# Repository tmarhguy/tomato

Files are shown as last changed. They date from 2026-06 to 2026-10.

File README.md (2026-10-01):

<h1 align="center">Tomato</h1>
<p align="center"><strong>A 32-bit computer architecture built from copper to browser.</strong></p>
<p align="center">
  
  
  
  
  
</p>

<p align="center">
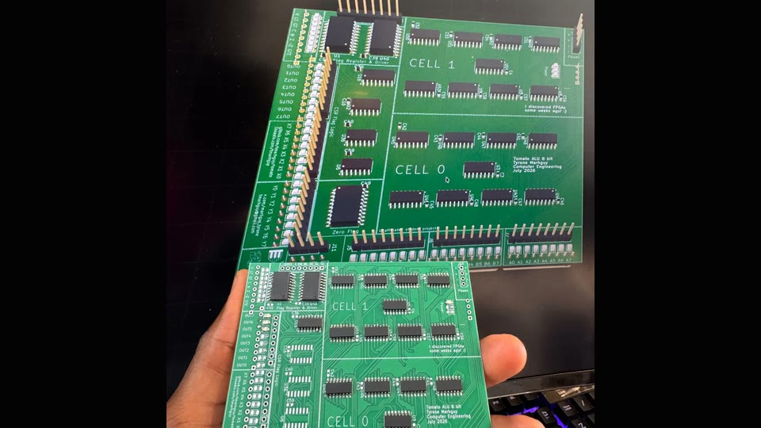
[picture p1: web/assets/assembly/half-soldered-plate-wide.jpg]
Physically assembled Tomato Dual-LUT ALU slice
  
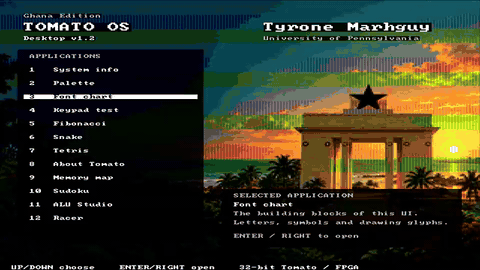
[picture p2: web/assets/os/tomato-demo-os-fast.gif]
Accelerated preview of Tomato OS running on FPGA Tomato
  
</p>
<p align="center"><em>Physical ALU slice · <a href="web/assets/os/tomato-demo-os.mp4">FPGA Tomato OS recording (4× preview)</a></em></p>

The animation is a sped-up preview of the complete FPGA machine.

Tomato is one architecture expressed at several layers:

- a fabricated and soldered **8-bit 74xx Dual-LUT ALU slice**;
- a complete **FPGA Tomato** on the Nexys A7-100T that boots the
  assembly-written Tomato OS;
- **TOMATO OS v3.0**, written in Tomato assembly, with 14 menu entries;
- a functional **Virtual Tomato** ISA emulator in the browser;
- editable Digital schematics, KiCad boards, RTL, an assembler, and focused verification.

The complete discrete computer remains a goal. The assembled ALU slice is real
hardware, but it is not a complete discrete machine. The complete running
computer in this repository is the FPGA implementation.

**Explore:** [architecture](docs/architecture.md) ·
[current status](docs/status.md) ·
[Tomato OS](software/os/README.md) ·
[ISA](docs/isa/README.md) ·
[compute](docs/compute.md) ·
[documentation index](docs/README.md) ·
[project site](https://tomato.tmarhguy.com/)

## Architecture at a glance

These curated diagrams explain the system; the
[interactive GitDiagram](https://gitdiagram.com/tmarhguy/tomato) provides a
zoomable, generated map of the public repository's default branch.

**Visual entry points:** [interactive repository map](https://gitdiagram.com/tmarhguy/tomato) ·
[architecture guide](docs/architecture.md) ·
[web architecture](https://tomato.tmarhguy.com/architecture.html) ·
[ISA reference](https://tomato.tmarhguy.com/isa.html) ·
[run Virtual Tomato](https://tomato.tmarhguy.com/virtual.html)

### One architecture, several realizations

<picture>
  <source media="(prefers-color-scheme: dark)" srcset="web/assets/gallery/diagrams/system-realizations-dark.svg">
  Editable Tomato sources flow into discrete hardware, FPGA, RTL simulation, browser emulation, and their evidence layers
</picture>

The four realization boxes are deliberately separate. The assembled discrete
hardware proves the ALU slice; the FPGA is the complete machine; Icarus runs
the RTL locally; and the browser is a functional ISA emulator.
[Diagram source](docs/diagrams/system-realizations.mmd).

### From source files to runnable artifacts

<picture>
  <source media="(prefers-color-scheme: dark)" srcset="web/assets/gallery/diagrams/artifact-pipeline-dark.svg">
  Tomato ISA and OS sources generate shared FPGA burn headers and a browser firmware image
</picture>

The generated FPGA burn and browser image share the same OS and control data.
They do not share an execution engine: the FPGA and Icarus execute Verilog,
while `tomato-cpu.js` mirrors the ISA-level behavior in JavaScript.
[Diagram source](docs/diagrams/artifact-pipeline.mmd).

### Inside FPGA Tomato

<picture>
  <source media="(prefers-color-scheme: dark)" srcset="web/assets/gallery/diagrams/fpga-datapath-dark.svg">
  FPGA Tomato datapath from program counter and memory through decode, registers, execution, writeback, and memory-mapped peripherals
</picture>

The board harness owns clocks, pins, keypad debounce, glyph rendering, DVI, and
seven-segment output. The machine core exposes those facilities as ports and
memory-mapped windows, keeping board-specific wiring outside the CPU RTL.
[Diagram source](docs/diagrams/fpga-datapath.mmd).

### Authority and state boundaries

- **Edit:** Digital schematics, ISA CSVs, assembly sources, and FPGA/browser
  implementation source.
- **Regenerate:** `.mem` images, `rtl/burn/*.vh`, `tomato-os.bin`, and
  bitstreams. These are derived artifacts, not design authorities.
- **Runtime state:** FPGA RAM, registers, framebuffer, compiler, radio mailbox,
  and the browser machine are volatile. Reset or reload restores the compiled
  image; this repository has no application database.
- **External systems:** Envelop clients, durable queues, hosted services, and
  the nearby bridge belong to the separate Envelop project.

## What runs now

| Layer | Current, repository-backed statement |
|---|---|
| Architecture | 32-bit datapath and instruction word |
| ALU | Custom three-source Dual-LUT ALU: two LUT3 functions feed an adder, `f(a,b,c) + g(a,b,c) + carry` |
| ISA | **91 instructions plus NOP, 92 burned rows** in a 512-row control ROM |
| Register array | Discrete (primary): **32,768 × 32-bit**. FPGA: **256 × 32-bit**, addressed as 3 bank bits plus a 5-bit register field; `r0` is hardwired to zero — no space for more on that implementation |
| FPGA | 100 MHz board input; **6.25 MHz** default CPU and 25 MHz pixel clocks; 90 MHz is only the nextpnr timing target |
| OS | The complete FPGA computer boots assembly-written **TOMATO OS v3.0**, with 14 menu entries including Envelop |
| Browser | Functional ISA-level emulation; not cycle-accurate RTL or physical execution |
| Hardware compiler | Counter FSM searches all **65,536 LUT pairs** for one fixed A/B/C/carry/output example; a hit verifies that example, not a general function |
| ALU verification | A **130-billion-vector** 32-bit ALU run is recorded and its harness is reproducible; the full run log is not checked in |

The architectural register count is **32,768**, because discrete is the
superior design constraint. FPGA implementation remains **256 × 32-bit**
because there is no space for a larger file; its 3-read/1-write array maps to
distributed RAM. Discrete uses external SRAM plus a seven-bit superbank and
`SETBANK2`. Neither the superbank nor that instruction exists in the current
FPGA RTL and burned ISA.

For evidence paths and the distinction between source-complete,
hardware-dependent, and deployed behavior, use
[`docs/status.md`](docs/status.md). Historical journal entries can describe
earlier designs and counts; they do not override current sources.

## See it, run it, inspect it

### Browser

Open the [Tomato site](https://tomato.tmarhguy.com/) and choose the Virtual
Tomato experience. Its checked-in OS image is generated from the assembly and
control data in this repository. Results there must be labeled virtual.

<p align="center">
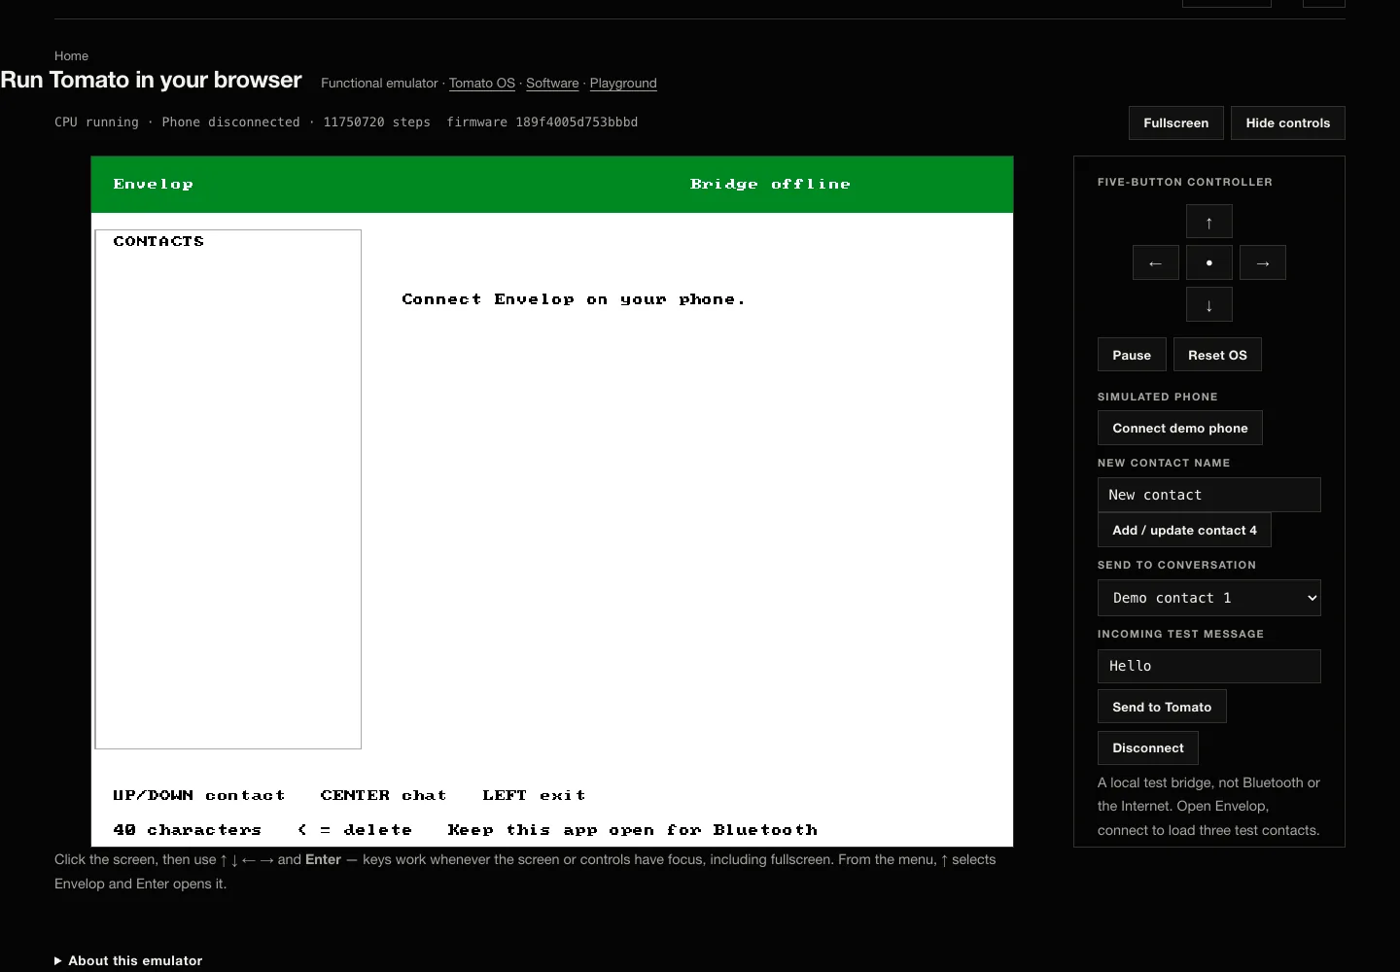
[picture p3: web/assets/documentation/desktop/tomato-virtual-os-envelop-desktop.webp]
Play with Tomato OS in the Virtual Tomato browser emulator
  
</p>
<p align="center"><strong><a href="https://tomato.tmarhguy.com/virtual.html">Play with Virtual Tomato →</a></strong><br><em>Functional ISA emulation with simulated peripherals—not FPGA or discrete-hardware execution.</em></p>

### Local RTL simulation

Icarus Verilog can boot the OS and print its framebuffer without an FPGA:

```bash
make -C hardware/fpga/core os
```

Run the focused core regression:

```bash
make -C hardware/fpga/core test
```

These commands prove simulation behavior, not a currently programmed board.

### Assemble a Tomato program

```bash
python3 software/assembler.py software/asm/counter.s \
  -o /tmp/counter.mem --list
python3 software/assembler.py --selftest
```

The assembler reads the burned ISA and pseudo-instruction CSVs rather than
carrying a private opcode table.

### FPGA build

The default flow is Yosys → nextpnr-xilinx → Project X-Ray. An optional Linux
Vivado batch target is also provided. Building a bitstream does not prove that
a board is currently programmed.

```bash
make fpga-setup
make fpga
```

Programming is intentionally a separate, hardware-changing action; see
[`hardware/fpga/README.md`](hardware/fpga/README.md).

## Proof across the stack

<table>
  <tr>
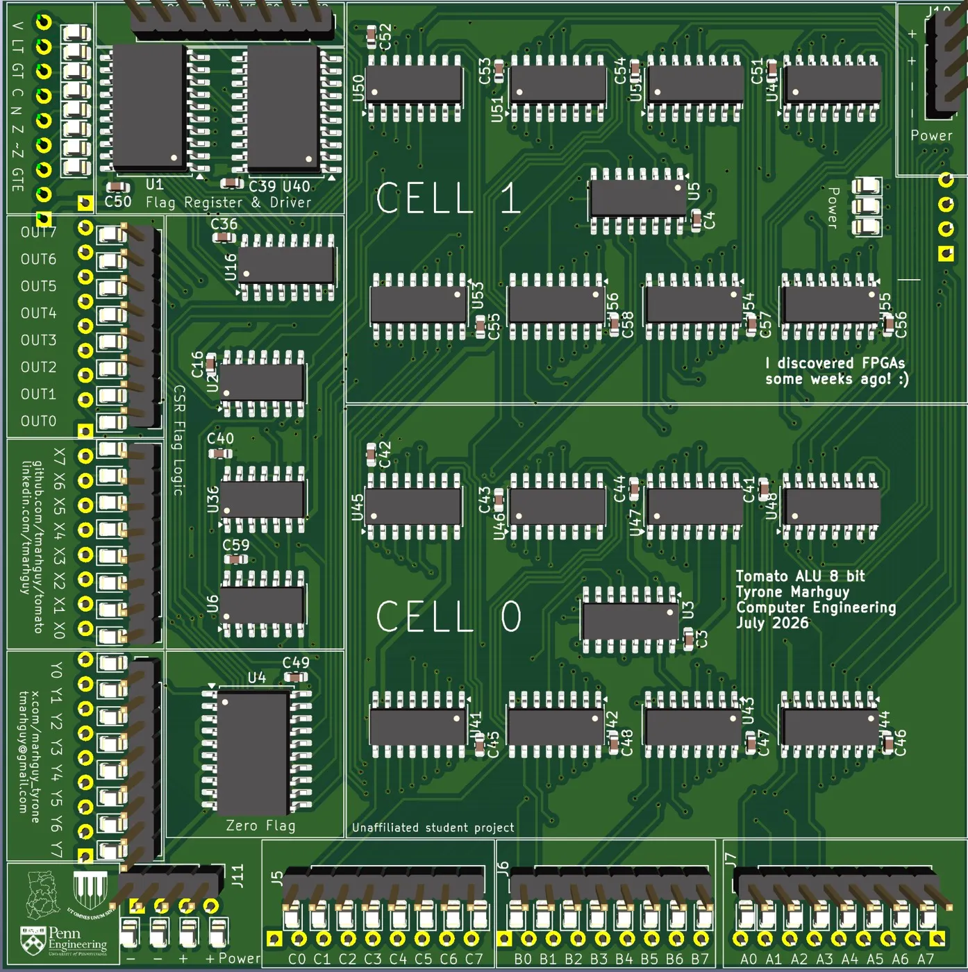
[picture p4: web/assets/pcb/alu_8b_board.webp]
Rendered Tomato Lot 07 Dual-LUT ALU PCB
    <td width="33%" align="center" valign="middle"></td>
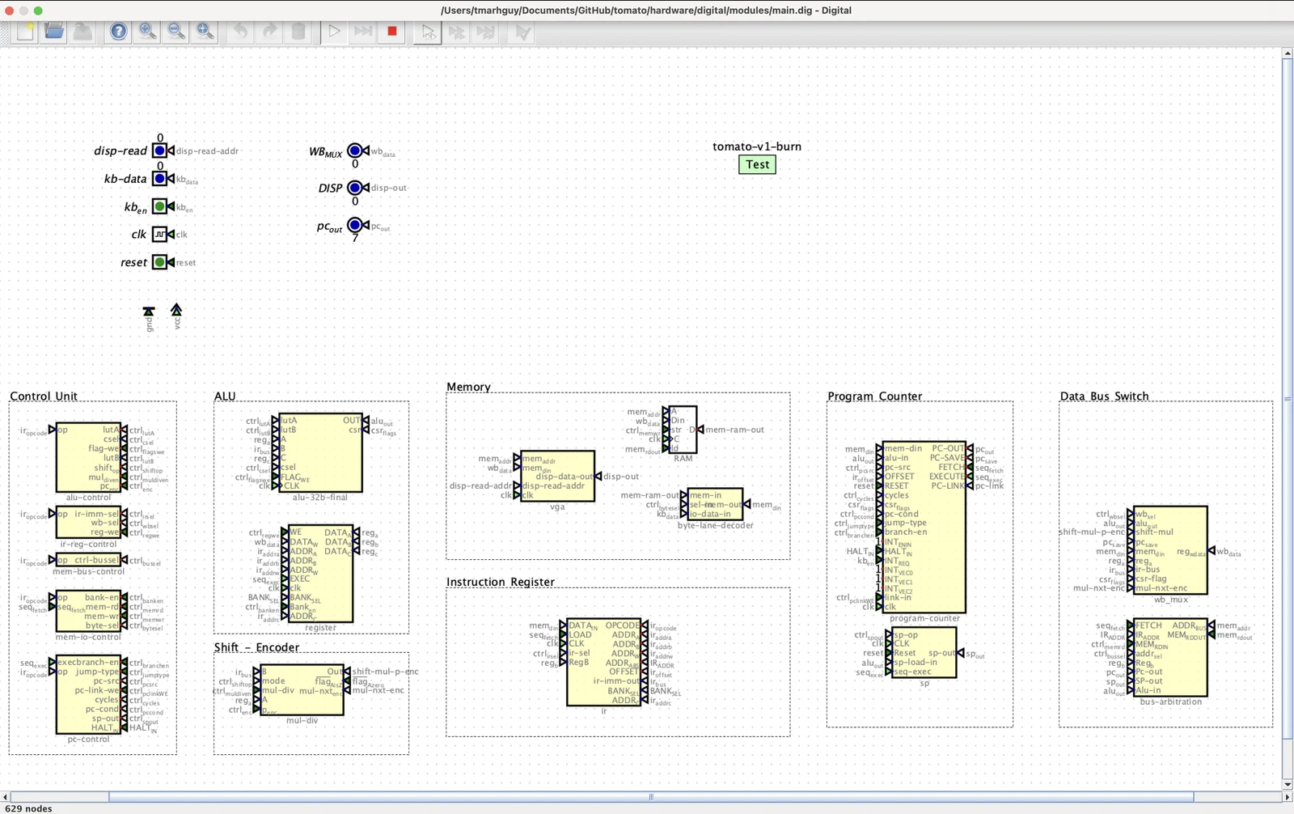
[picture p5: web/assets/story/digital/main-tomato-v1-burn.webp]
Tomato architecture in the Digital logic simulator
    <td width="33%" align="center" valign="middle"></td>
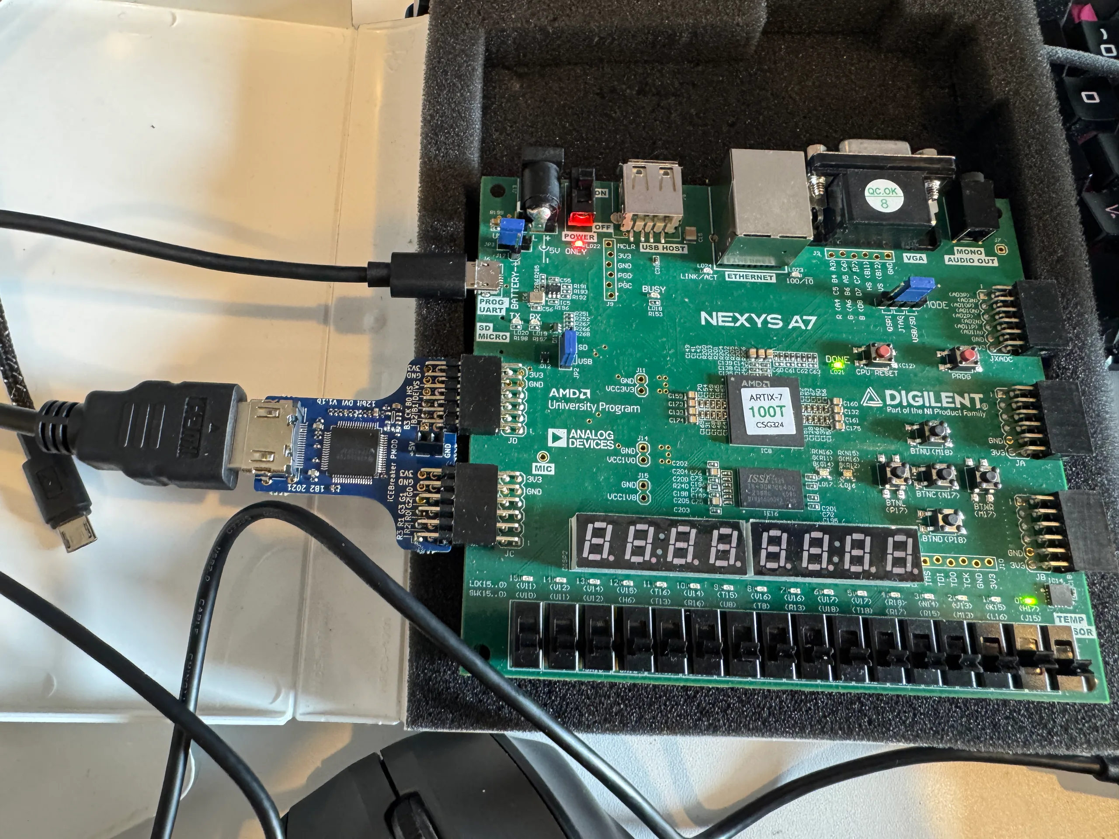
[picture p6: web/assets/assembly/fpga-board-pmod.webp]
Nexys A7 board used for FPGA Tomato display output
    <td width="33%" align="center" valign="middle"></td>
  </tr>
</table>

- **Physical scope:** [`hardware/kicad/boards/07_alu/`](hardware/kicad/boards/07_alu/)
- **Editable logic:** [`hardware/digital/`](hardware/digital/)
- **Complete FPGA machine:** [`hardware/fpga/core/`](hardware/fpga/core/)
- **Machine software:** [`software/`](software/)
- **Verification:** [`verification/`](verification/)
- **Evidence and asset provenance:** [`docs/assets.md`](docs/assets.md)

## Envelop and compute

Envelop is a separate messaging project. Its Tomato-side client and bounded
compute executor are linked into Tomato OS; its user clients, backend, and
nearby bridge live outside this repository.

The intended hardware message path is:

`person → Envelop web app → backend queue → nearby verified bridge → Envelop in Tomato OS → Tomato CPU → labeled reply`

<picture>
  <source media="(prefers-color-scheme: dark)" srcset="web/assets/gallery/diagrams/envelop-boundary-dark.svg">
  Envelop hardware path from person and backend queue through a verified bridge to FPGA Tomato, with virtual preview kept separate
</picture>

Source in a repository is not evidence that a bridge is active or that a reply
ran on hardware. Bridge software is available in the separate Envelop project,
but a nearby authenticated bridge and completed FPGA job require live evidence.
Virtual previews are explicit, separate, and labeled. See
[`docs/compute.md`](docs/compute.md) for the current boundary.
[Diagram source](docs/diagrams/envelop-boundary.mmd).

## Repository map

| Path | Purpose |
|---|---|
| [`docs/`](docs/) | Canonical guides, ISA contracts, and historical journal |
| [`hardware/digital/`](hardware/digital/) | Editable architecture schematics |
| [`hardware/kicad/`](hardware/kicad/) | PCB designs and assembly records |
| [`hardware/fpga/`](hardware/fpga/) | Complete machine, board harness, and simulation |
| [`software/`](software/) | Assembler, programs, and Tomato OS |
| [`microcode/`](microcode/) | Control-ROM packaging |
| [`verification/`](verification/) | ALU and implementation checks |
| [`web/`](web/) | Project site and browser emulator |

## Documentation and history

Start with [`docs/README.md`](docs/README.md). It separates current canonical
guidance from the dated [`docs/log/`](docs/log/) engineering record. The
journal preserves decisions, wrong turns, and superseded designs as history;
use the [current journal index](docs/log/README.md) to navigate it.

Documentation authority and terminology are defined in
[`docs/documentation-policy.md`](docs/documentation-policy.md). When prose and
executable sources disagree, that policy determines which source wins.

## Documentation

Detailed architecture, implementation, verification, and technical
documentation is available in the project documentation.
The technical reference manual source is [`docs/index.adoc`](docs/index.adoc);
build the static manual locally with `make docs` (requires Asciidoctor).

## License and author

Tomato is licensed under the [Solderpad Hardware License 2.1](LICENSE).
Architecture and project by **Tyrone Marhguy**, Computer Engineering ’28,
University of Pennsylvania.

[Contributing](CONTRIBUTING.md) · [security](SECURITY.md) ·
[citation](CITATION.cff) · [third-party notices](THIRD_PARTY_NOTICES.md)

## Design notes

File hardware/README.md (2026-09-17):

# Tomato hardware

Tomato's architecture appears in editable schematics, physical PCB work, and a
complete FPGA implementation. These layers share a design, but they prove
different things.

<p align="center">
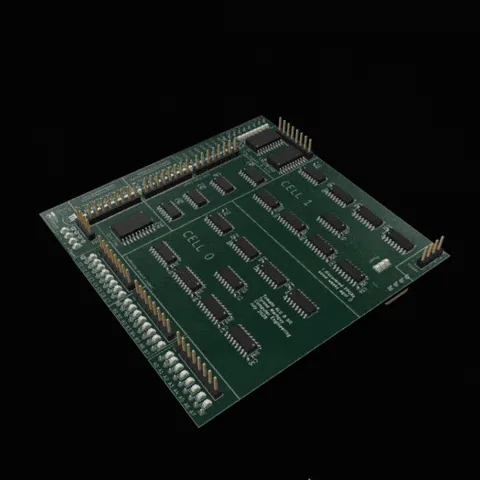
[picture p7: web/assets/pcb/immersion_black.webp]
Tomato Dual-LUT ALU PCB
  
  Nexys A7 used by the complete FPGA Tomato machine
</p>
<p align="center"><em>Discrete ALU work at left; complete FPGA machine at right.</em></p>

## Current scope

- The physically assembled discrete hardware is a **Dual-LUT ALU slice**, not
  a complete discrete computer.
- The complete machine capable of booting Tomato OS is **FPGA Tomato** on the
  Nexys A7-100T.
- Digital schematics remain the editable architectural source for the discrete
  design.
- Exported Verilog is a derivative and must not be hand-edited as design source.

## Directory map

| Path | Role | Authority/evidence |
|---|---|---|
| [`digital/`](digital/) | Digital schematics and simulation | Editable architecture source |
| [`kicad/`](kicad/) | Numbered board designs and assembly documentation | Physical design and pictured build evidence |
| [`fpga/`](fpga/) | Complete Nexys A7 machine, board harness, and tests | Current FPGA implementation |
| [`verilog/`](verilog/) | Digital export policy and netlists | Generated/read-only derivatives |

Current register, ISA, OS, and clock facts live in
[`../docs/status.md`](../docs/status.md). Older hardware notes may describe
different register or ISA designs and do not override that canonical status.

## Workflow boundaries

For discrete logic, edit Digital sources, export Verilog, then copy the export
to the relevant verification/implementation tree and run the appropriate
checks. For PCB work, KiCad sources and assembly records establish design and
physical scope.

For FPGA work, the default build uses Yosys, nextpnr-xilinx, and Project X-Ray.
An optional Linux Vivado batch target also exists. A successful build is not
proof that a board is currently programmed.

## Continue

- [Architecture guide](../docs/architecture.md)
- [Digital guide](digital/README.md)
- [KiCad guide](kicad/README.md)
- [FPGA guide](fpga/README.md)
- [FPGA core guide](fpga/core/README.md)
- [Documentation authority](../docs/documentation-policy.md)

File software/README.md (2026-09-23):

# Tomato software

This directory contains Tomato's two-pass assembler, assembly test programs,
and TOMATO OS v3.0. Machine instructions come from
[`docs/isa/tomato.v1.csv`](../docs/isa/tomato.v1.csv); assembler-only
vocabulary comes from
[`docs/isa/tomato.v1.pseudo.csv`](../docs/isa/tomato.v1.pseudo.csv).

**Project map:** [root README](../README.md) · [ISA](../docs/isa/README.md) · [Tomato OS](os/README.md) · [FPGA core](../hardware/fpga/core/README.md)

<p align="center">
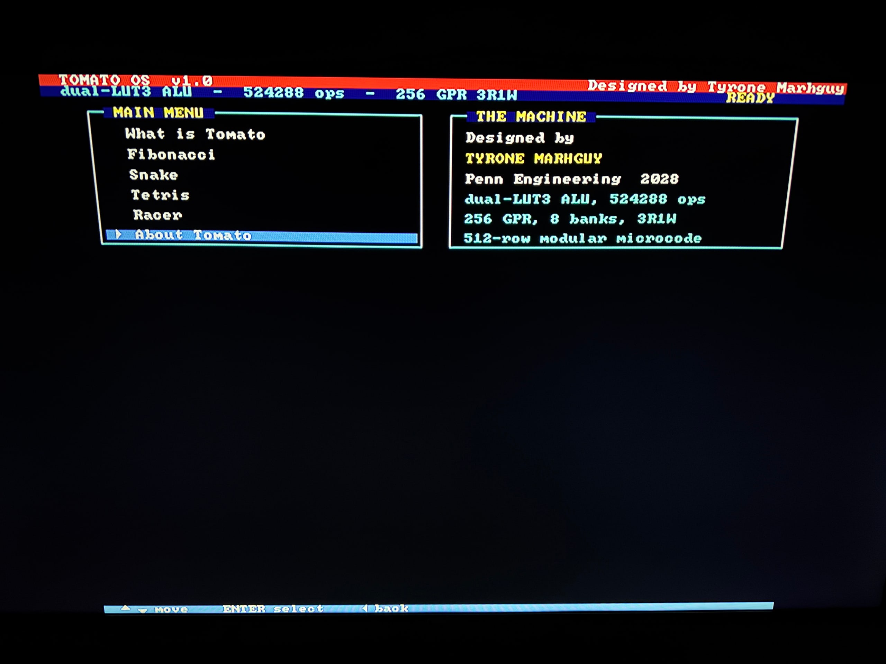
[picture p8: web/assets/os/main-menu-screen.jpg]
Tomato OS main menu on HDMI
  
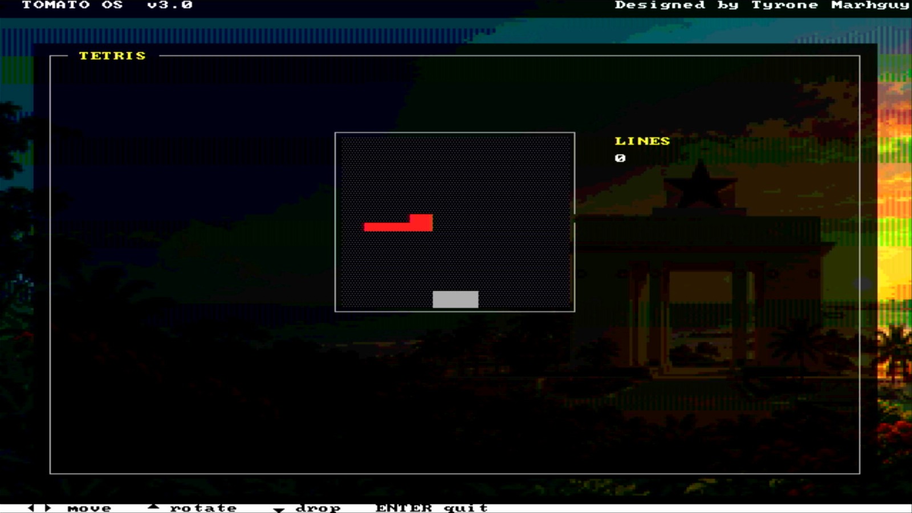
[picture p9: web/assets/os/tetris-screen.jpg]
Tetris on Tomato OS
  
</p>
<p align="center"><em>Tomato OS · menu and Tetris · <a href="https://tomato.tmarhguy.com/software.html">software sheet</a></em></p>

| Path | What |
|---|---|
| `assembler.py` | Two-pass assembler; the ISA CSVs are its only opcode source |
| `os/` | Tomato OS v3.0, its 14 entries, Envelop client, and bounded executor |
| `asm/` | Small programs, each with a value a testbench asserts on |

---

## Table of Contents

- [Assemble](#assemble)
- [Two authorities](#two-authorities)
- [Syntax](#syntax)
- [Directives](#directives)
- [Tomato OS](#tomato-os)
- [Samples](#samples)

---

## Assemble

```bash
python3 software/assembler.py software/asm/counter.s -o hardware/fpga/core/tb/mem/counter.mem --list
```

From `hardware/fpga/core`: `make asm` builds every image, `make burn` packs them into the FPGA burn headers, `make os` runs the OS in simulation.

---

## Two authorities

The assembler holds no opcode table of its own. It reads both CSVs at startup, so growing the machine's vocabulary is a data change, not a code change.

| File | Holds |
|---|---|
| [`tomato.v1.csv`](../docs/isa/tomato.v1.csv) | The 512-row control ROM: **91 instructions plus NOP, 92 burned rows** |
| [`tomato.v1.pseudo.csv`](../docs/isa/tomato.v1.pseudo.csv) | Pseudo-instructions that expand into already-burned instructions |

Check the second one against the first at any time:

```bash
python3 software/assembler.py --selftest
```

That assembles every pseudo twice — once as the pseudo, once as the instructions it claims to expand into — and fails if the two word images differ. `make -C hardware/fpga/core test` runs it as `asm-check`.

---

## Syntax

| Form | Example |
|---|---|
| RRR | `ADD r4, r1, r2` |
| MOV | `MOV r1, r2` (rd ← rB) |
| unary | `ZERO r5` |
| ADDI/LW | `ADDI r1, r0, 10` / `LW r6, r5, 0` |
| SW | `SW r1, r5, 0` (data, base, imm8) |
| branch | `BNE loop` / `BEQ done` (PC-relative) |
| jump | `JMP loop` (absolute word address) |
| system | `NOP` / `HALT` / `RET` |

Comments: `;` or `#`. Labels: `name:`.

### Vocabulary

The CPU has only `BEQ` / `BNE` / `BLT` / `BGE`, and the compare that feeds them is a separate instruction, so plain intent used to read as two unrelated lines. These say it in one:

| Write | Get |
|---|-----|
| `CALL puts` | `JAL r16, puts` — the link register |
| `BEQZ r22, done` | `CMP r22, r0` + `BEQ done` |
| `BNEZ`, `BLTZ`, `BGEZ` | the same shape, other conditions |
| `BLE done` | `BEQ done` + `BLT done` |
| `BGT done` | skip the `BGE` when the compare was equal |
| `LI r5, 100` | `ADDI r5, r0, 100` — value, not address |
| `TST r6` | `CMP r6, r0` |
| `INC` / `DEC` / `NEG` / `CLR` | in-place arithmetic, spelled out |
| `BZ` / `BNZ` / `BMI` / `BPL` | the conditionals, read after a `TST` |
| `BRA` / `ASL` | `JMP` / `LSL` under their usual names |

`LA rd, label` loads an address, and is the one thing limited to the low 4 KB — it assembles to `ADDI rd, r0, addr`, so the label must fit an unsigned 12-bit immediate. Pointer tables have no such limit: a `.word label` holds the full 32-bit address, which is how Tomato OS keeps its prose above `0x1000`.

---

## Directives

| Directive | Effect |
|---|---|
| `.org addr` | Set the next word address (sparse image; holes are 0) |
| `.word n, n` | Emit raw 32-bit words — glyphs, tables, pointers |
| `.space n` | Reserve n zeroed words for something written at runtime |
| `.ascii "text"` | One word per character (memory is word-addressed) |
| `.asciz "text"` | The same, NUL-terminated |

---

## Tomato OS

The OS sources identify **TOMATO OS v3.0** and declare **14 menu entries**.
Desktop v1.2 is the workspace UI revision, not the OS version. The image links
`tomato_os.s`, the Tomato-side Envelop client and setup records, and the bounded
remote executor.

See [`os/README.md`](os/README.md) for the menu, source boundaries, and focused
checks. Envelop's user clients, backend, and nearby bridge live in the separate
Envelop project; their source or deployment status cannot be inferred from the
machine-side assembly here.

---

## Samples

| Program | Check |
|---|---|
| `asm/counter.s` | r1 = disp = 10 |
| `asm/fib.s` | fib(8) → r1 = r6 = 21 |
| `asm/collatz.s` | n=27 → 111 steps in r1/disp |
| `asm/call.s` | JAL/RET → r1=99 r2=42 |
| `asm/bytes.s` | SB/LB signed byte |
| `asm/ecall.s` | trap + RET → r1=42 |
| `asm/softops.s` | ROR/LBU → r1=r6=129 |
| `asm/io.s` | IN/OUT keyboard echo |
| `asm/kb_mmio.s` | LW MMIO kb data/status |

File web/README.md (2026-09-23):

<h1 align="center">TOMATO</h1>
<p align="center"><strong>32-bit Computer.</strong> The oddest machine still built from chips.</p>

 

<p align="center">
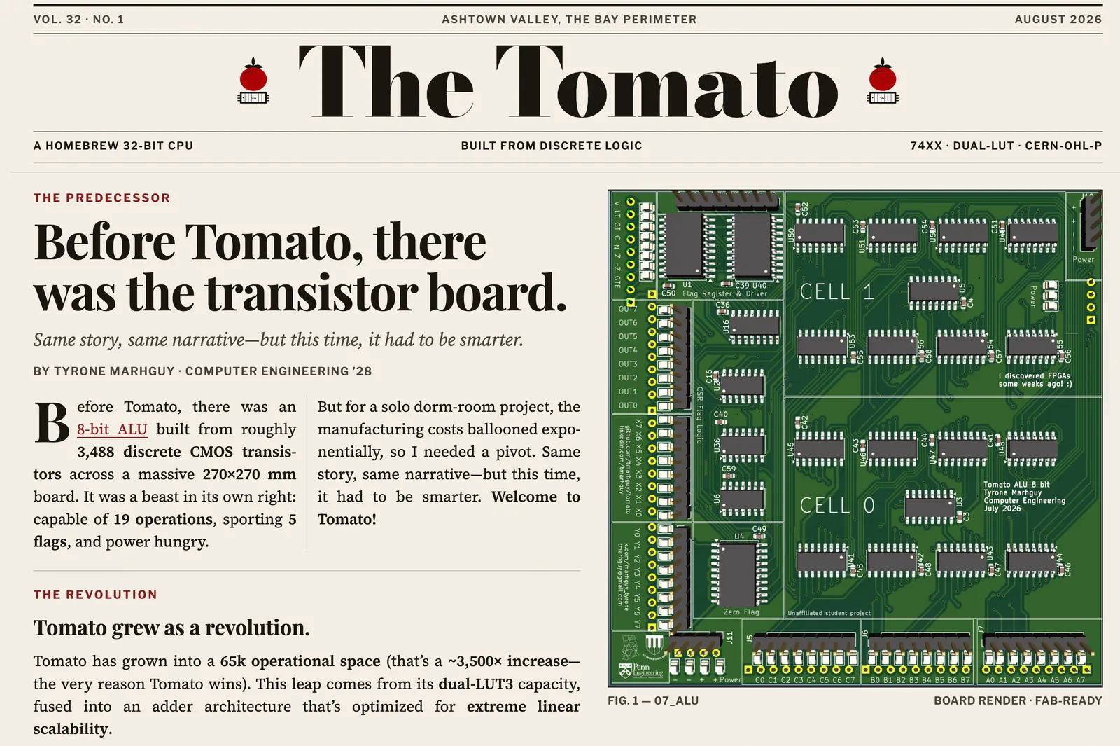
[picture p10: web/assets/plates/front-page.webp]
The Tomato, Vol. 32 No. 1 — front page, August 2026
  
</p>
<p align="center"><em>Vol. 32 · No. 1 · Magnesium Alley, Ashtown-Bay Perimeter · August 2026</em></p>

This is not a SaaS product page. It is not a bloated React template. The live site is a static paper—Libre Franklin and Source Serif 4—that acts as a temporal bridge to the hardware. It features a fully interactive 3D KiCad GLB of [`07_alu`](https://tomato.tmarhguy.com/board.html), **[Virtual Tomato](https://tomato.tmarhguy.com/virtual.html)** in the browser, a bit-level **[Dual-LUT playground](https://tomato.tmarhguy.com/playground.html)**, **[ALU verification sign-off](https://tomato.tmarhguy.com/verification.html)** (SymbiYosys, 476 directed, 10B/130B Verilator), and the project's **[engineering journal](https://tomato.tmarhguy.com/journal.html)**. The old newspaper plates remain as history (`broadsheet.html`); they are not the current design authority.

**Live:** [tomato.tmarhguy.com](https://tomato.tmarhguy.com/)  
**Core CPU architecture:** [Root README](../README.md)  
**Design journal:** [docs/log/](../docs/log/)

### Run locally

Do not open HTML via `file://` — the GLB and ES modules need a server. Use the repository server so cache headers, gzip, and ES modules match deployment:

```bash
cd web && npm run serve
# http://localhost:8080/
```

`npm run serve:plain` is a last-resort Python server with no cache or compression.

---

## Current website direction

The homepage leads with the interactive ALU board and the sentence “A functional 32-bit computer built from scratch in a dorm.” The older line — that its logic can change with each instruction — sits in the What is Tomato? section and the footer. The text keeps its natural height; the board fills the remaining opening viewport. The site explains the configurable datapath, running FPGA software, discrete build, hardware compiler, and verification with diagrams and working examples.

Read [`docs/status.md`](../docs/status.md) and [`docs/documentation-policy.md`](../docs/documentation-policy.md) before changing design or project claims. They record current facts, evidence boundaries, and which source wins. The old newspaper presentation is historical context, not the current design authority.

<p align="center">
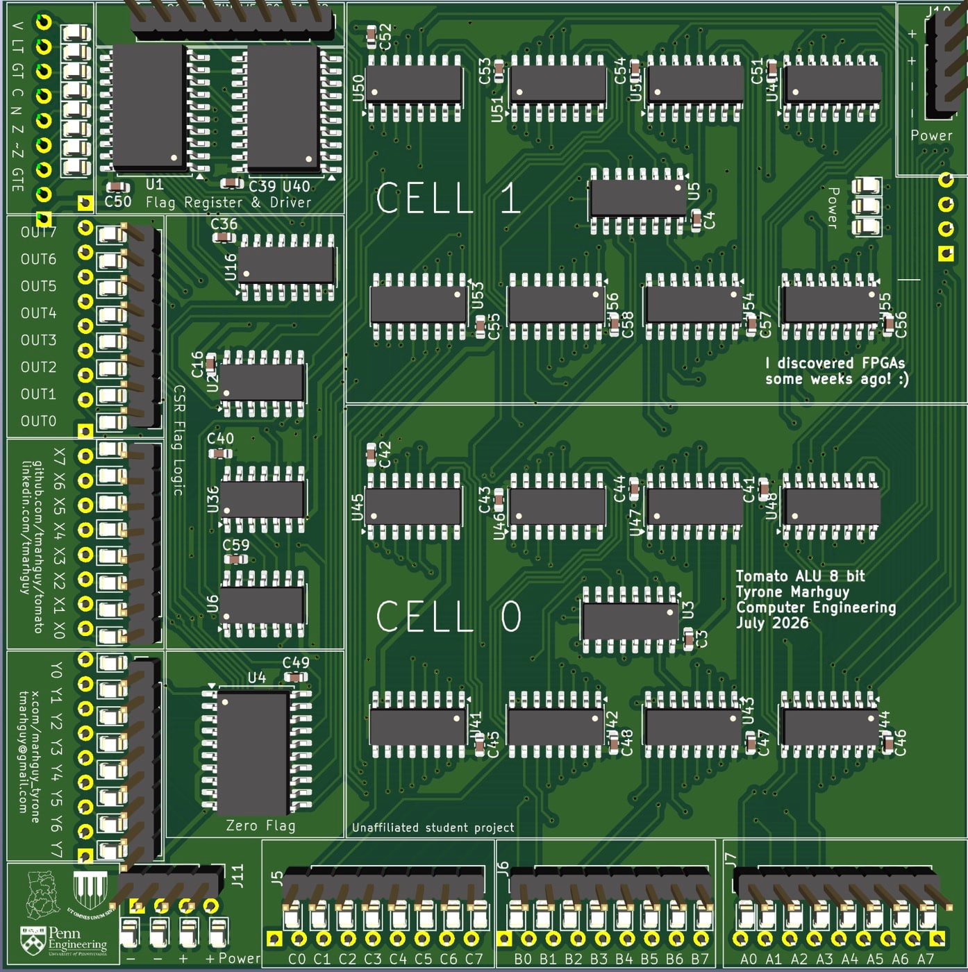
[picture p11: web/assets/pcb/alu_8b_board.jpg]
Tomato 07_alu — KiCad board render
  
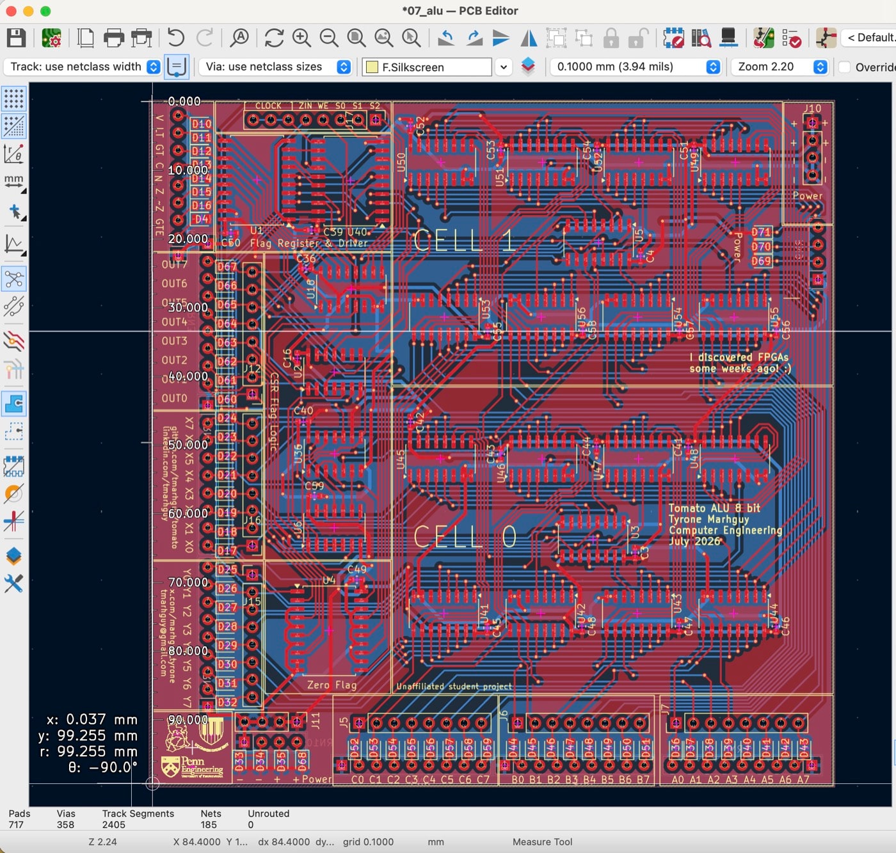
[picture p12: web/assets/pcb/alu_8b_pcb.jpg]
Tomato 07_alu — routed top copper
  
</p>
<p align="center"><em>Left: Board render · Right: Routed top copper — The same plates featured in Fig. 1.</em></p>

---

## Design Constraints & Impact

Every choice on this site mirrors the architectural constraints of the CPU itself: cut the bloat, ensure it routes cleanly, and make it functional on the bench.

- **Static HTML over SPA:** The shipped `07_alu` GLB is **1.26 MB** Draco (**9** meshes). The raw KiCad export behind it is still ~**31 MB** / ~**41k** primitives — that file does not go in the tab. `web/` deploys as a raw folder. Vercel install command: `echo "no-install"`.
- **Relative Links Only:** Nested pages (`journal/…`, `boards/…`), local `npm run serve`, and Vercel all break if assets are rooted at `/css/…`. Everything is strictly relative so the paper works on [tomato.tmarhguy.com](https://tomato.tmarhguy.com/), a local preview, or a subdirectory checkout.
- **Shared identity:** `css/landing.css` owns the homepage, `css/site.css` plus `css/brand.css` carry identity across the reference pages, `css/navigation.css` is the chrome, `css/virtual.css` is the emulator, and `css/viewer.css` keeps the 3D workspace full-screen. Pages use a static header/footer and a responsive all-pages menu.
- **KiCad’s Native Copper:** No artificial gold restyling. The export matches the physical board: **FR4 core black**, silk white, copper untouched. Fig. 1 and the interactive GLB use the exact same material palette.
- **Demand-Rendered 3D:** The optimized GLB is nine draws. A raw KiCad dump is still **~41k**. The loader skips client merge when mesh count is under 32, and the canvas only renders when the camera moves or the board is on-screen.
- **The Forge in the Paper:** [`source.html`](https://tomato.tmarhguy.com/source.html) pulls the live GitHub repo directly into the broadsheet layout so the design and its source can be explored together.

<p align="center">
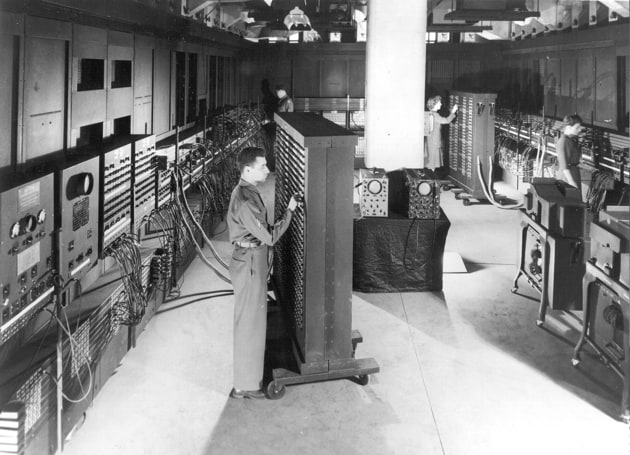
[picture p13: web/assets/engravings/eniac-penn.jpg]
ENIAC at the Moore School, 1946
  
  07_alu board render
</p>
<p align="center"><em>Then: ENIAC at the Moore School (U.S. Army). Now: The 07_alu slice.</em></p>

---

## Core Features

### 1. 3D Immersion: The Bench & The Viewer

We run two cameras on one model (`assets/pcb/alu.glb`), exported directly from **KiCad 10**.

- **[The Bench](https://tomato.tmarhguy.com/)** (`js/bench.js`): Embedded on the front page. Drag, iso/side toggle, spin. Dimmed slightly so the cream paper still reads.
- **[The Viewer](https://tomato.tmarhguy.com/viewer.html)** (`js/viewer.js`): A dedicated, full-screen studio tour. Press **I** for a cinematic, monotonic orbit that lands on the upright isometric view. Any manual input aborts the tour.

### 2. The Playground

The [`playground.html`](https://tomato.tmarhguy.com/playground.html) interface is `07_alu` on a wire. It’s a **bit-level Dual-LUT emulator** running in the browser. Toggle operands, flip both LUT opcodes, and assert carry. If the Dual-LUT architecture doesn't survive a bit-flip in the browser, it won't survive a logic probe on the physical bench.

### 3. Virtual Tomato

[`virtual.html`](https://tomato.tmarhguy.com/virtual.html) boots the shipped OS image (`data/tomato-os.bin`) in a functional ISA emulator (`js/tomato-cpu.js`). It is host-budgeted behavior, not a 6.25 MHz or cycle-accurate machine. On phones, the D-pad uses `touch-action: manipulation` so double-tap zoom does not steal control taps. The homepage embed (`js/virtual-embed.js`) is the same engine with less chrome.

<p align="center">
  Tomato 07_alu — Dual-LUT slice in the round
</p>
<p align="center"><em>Lot 07 in the round · the slice the playground runs · <a href="https://tomato.tmarhguy.com/playground.html">open the playground</a></em></p>

### 4. The Journal & Boards

The journal takes [`docs/log/`](../docs/log/) and typesets it. It currently runs to **44 dispatches**, tracking the build from the first gate to the chips on the copper. The **[boards catalog](https://tomato.tmarhguy.com/boards.html)** tracks all **8 lots**. Lot **07** is **soldered** and on the bench. The remaining boards progress alongside the working FPGA machine.

### 5. The Gallery

[`gallery.html`](https://tomato.tmarhguy.com/gallery.html) is the plate room — the renders, the copper, and the bench photographs, laid out as a bound pictorial rather than a grid of thumbnails.

---

## What the paper is now describing

[`architecture.html`](https://tomato.tmarhguy.com/architecture.html), [`isa.html`](https://tomato.tmarhguy.com/isa.html), and [`software.html`](https://tomato.tmarhguy.com/software.html) cover the datapath, the ROM plus assembler vocabulary, and Tomato OS on HDMI. The burned ISA is **91 instructions plus NOP, 92 burned rows** in a 512-row control ROM. The architectural register file is **32,768 × 32-bit** locations — that is the primary count, because discrete is the superior design constraint. FPGA implementation remains **256 × 32-bit** entries (`{bank[2:0], register[4:0]}`, `r0` hardwired to zero) because there is no space for more on that fabric; the current burned ISA addresses that 256-entry FPGA array. Envelop messaging and the compute boundary live on [`envelop.html`](https://tomato.tmarhguy.com/envelop.html) and [`compute.html`](https://tomato.tmarhguy.com/compute.html). Source: [hardware/fpga/core](../hardware/fpga/core/README.md) · [software/os/tomato_os.s](../software/os/tomato_os.s).

### Tomato OS on the glass

**TOMATO OS v3.0** runs on the Nexys; **Desktop v1.2** is the workspace UI revision, not the OS version. The menu has **14 entries**. Ghana wallpaper, Sudoku, and a real HDMI capture path—not a phone pointed at the monitor. Live sheet: [`os.html`](https://tomato.tmarhguy.com/os.html). Dispatches: [wallpaper](https://tomato.tmarhguy.com/journal/wallpaper-polish.html) · [Sudoku](https://tomato.tmarhguy.com/journal/sudoku.html) · [HDMI capture](https://tomato.tmarhguy.com/journal/hdmi-captured.html).

<p align="center">
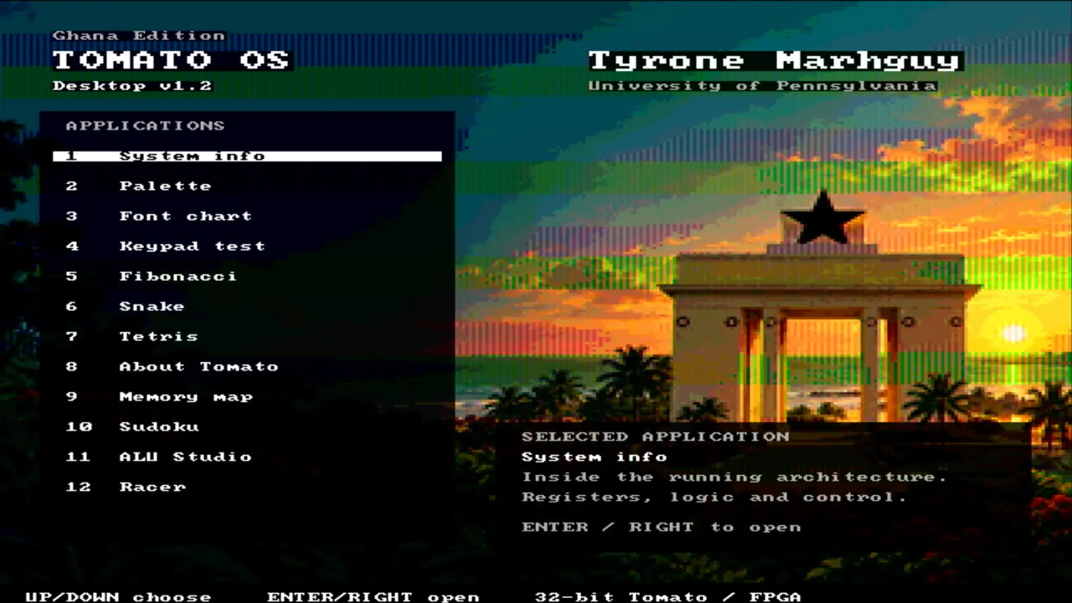
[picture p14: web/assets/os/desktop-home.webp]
Tomato OS Desktop v1.2 with Ghana wallpaper on the FPGA
  
</p>
<p align="center"><em>Desktop v1.2 · wallpaper on the FPGA</em></p>

<p align="center">
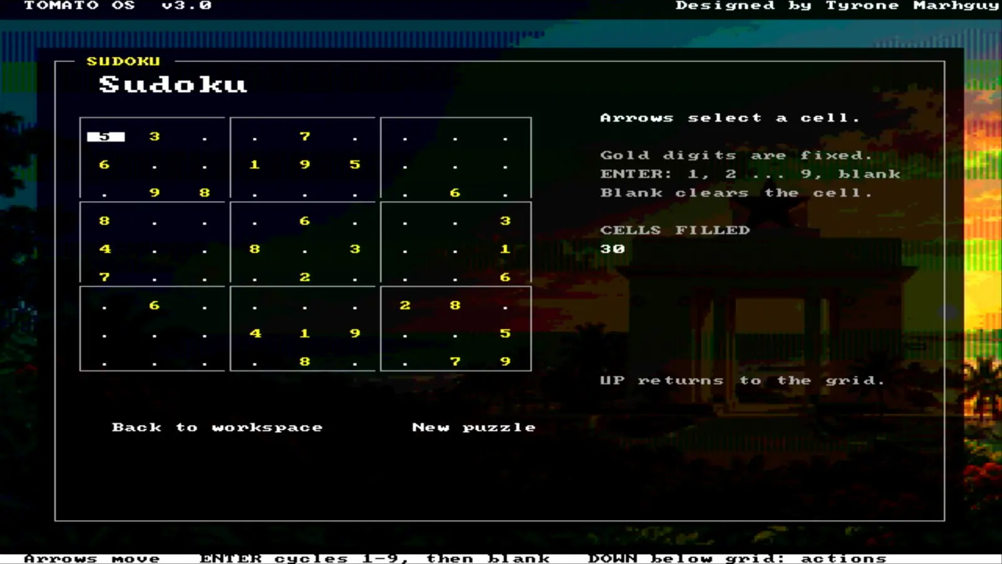
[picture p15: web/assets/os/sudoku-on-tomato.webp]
Sudoku running on Tomato OS
  
  &nbsp;
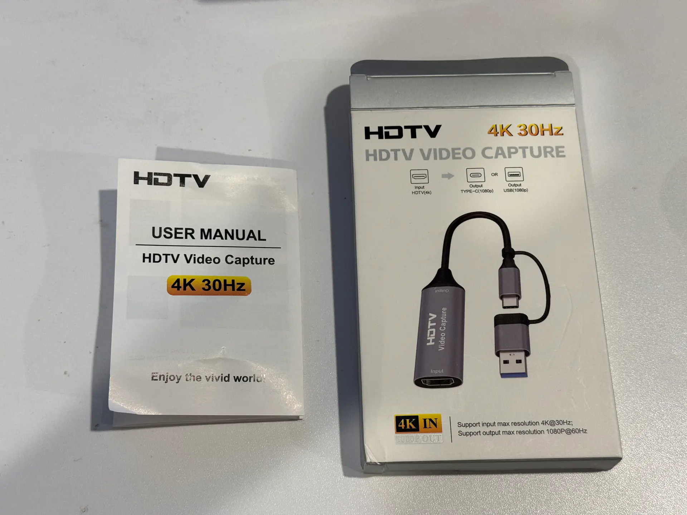
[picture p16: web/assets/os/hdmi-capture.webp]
Clean HDMI capture of Tomato OS
  
</p>
<p align="center"><em>Sudoku on glass · HDMI capture path</em></p>

---

## Repository Map

```text
web/
├── index.html              # Front page
├── virtual.html            # Tomato OS in the browser (functional emulator)
├── envelop.html            # Messaging product boundary
├── compute.html            # Hardware vs virtual compute labels
├── architecture.html       # Datapath & overlay word
├── isa.html                # 91 instructions + NOP, 92 burned rows
├── software.html           # Assembler, Tomato OS, stack
├── os.html                 # Desktop v1.2 / OS v3.0 sheet
├── playground.html         # Dual-LUT emulator
├── status.html             # What exists today
├── faq.html                # FAQ
├── journal.html            # Log index
├── journal/*.html          # Typeset design logs (44)
├── boards.html             # Lots 01–08 tracking
├── boards/*.html           # Individual board specs (8)
├── board.html              # Embedded 3D bench
├── viewer.html             # Full-screen immersion viewer
├── gallery.html            # Plate room
├── verification.html       # ALU sign-off
├── source.html             # GitHub rendered in-paper
├── broadsheet.html         # Historical newspaper layout
├── about.html              # The correspondent
├── 404.html                # Missing page
├── css/site.css            # Current identity
├── css/landing.css         # Homepage
├── css/virtual.css         # Emulator + D-pad
├── css/navigation.css      # Shared chrome
├── css/viewer.css          # Black studio lighting
├── js/tomato-cpu.js        # Functional CPU core (DOM-free, Node-tested)
├── js/virtual.js           # Full-board emulator UI
├── js/virtual-embed.js     # Homepage emulator embed
├── data/tomato-os.bin      # Repacked firmware image (tools/build_web_image.py)
├── assets/pcb/alu.glb      # Draco 07_alu (1.26 MB, 9 meshes)
├── tests/                  # Sanity + emulator regressions
└── ATTRIBUTION.md
```

---

## Local Development & Testing

**Preview** (same as [Run locally](#run-locally) above):

```bash
cd web && npm run serve
# → http://localhost:8080/
```

**Sanity Tests:**
There is no bundler. A silent 404 is the primary failure mode. `tests/site-sanity.mjs` walks every HTML file for dead links, missing assets, root-absolute paths, and JS syntax. After CSS/JS edits, refresh content hashes so browsers do not keep a stale D-pad or emulator:

```bash
cd web && npm run hash:assets && npm test
# Or from the repo root: make web-test
```

---

## Deployment

- **Live origin:** [tomato.tmarhguy.com](https://tomato.tmarhguy.com/)
- **Vercel:** The root `vercel.json` serves `web/`, installs nothing (`echo "no-install"`), and builds with `npm run hash:assets && npm test`. No framework.
- **CI:** `.github/workflows/web.yml` runs `npm test` on web PRs and pushes to `main`. There is no GitHub Pages workflow.

### Custom domain DNS (Namecheap)

Same pattern as `alu.tmarhguy.com`. In Namecheap → Domain List → `tmarhguy.com` → Advanced DNS:

| Type | Host | Value | TTL |
|---|---|---|-----|
| CNAME | `tomato` | `cname.vercel-dns.com.` | Automatic |

Add `tomato.tmarhguy.com` as a domain on the Vercel project. Clear any custom domain under the repo **Settings → Pages** so GitHub stops 301ing `github.io/tomato` at a dead hostname.

---

## Author

**Tyrone Marhguy** — Computer Engineering ’28, [University of Pennsylvania](https://www.upenn.edu/)

A look at the bottom left of the physical `07_alu` board reveals three silkscreened marks: **Penn Engineering, Achimota School, and the Ghana flag**. That silk is why the paper is printed in Ashtown Valley, even when the copper lands in Philadelphia.

| Links | |
| --- | --- |
| **Paper** | [tomato.tmarhguy.com](https://tomato.tmarhguy.com/) |
| **Repo** | [github.com/tmarhguy/tomato](https://github.com/tmarhguy/tomato) |
| **Email** | [tmarhguy@gmail.com](mailto:tmarhguy@gmail.com) |
| **Twitter** | [@marhguy_tyrone](https://twitter.com/marhguy_tyrone) |

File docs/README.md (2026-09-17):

# Tomato documentation

This directory separates current reference material from Tomato's dated
engineering record. If two documents disagree, start with
[`status.md`](status.md) and apply
[`documentation-policy.md`](documentation-policy.md).

## Start here

| Document | Use it for |
|---|---|
| [`status.md`](status.md) | Current facts, exact terminology, and deployment boundaries |
| [`architecture.md`](architecture.md) | The 32-bit machine, ALU, control, registers, memory, and implementations |
| [`compute.md`](compute.md) | Browser, RTL, FPGA, Envelop, and remote-compute provenance |
| [`isa/README.md`](isa/README.md) | Burned ISA contract and assembler vocabulary |
| [`../software/os/README.md`](../software/os/README.md) | Tomato OS v3.0, its 14 entries, source layout, and checks |
| [`assets.md`](assets.md) | Image selection, captions, provenance, and reuse |
| [`documentation-policy.md`](documentation-policy.md) | Which source wins and how status words are used |

The [root README](../README.md) is the visual front door. Subsystem guides live
with their source:

- [hardware](../hardware/README.md)
- [FPGA](../hardware/fpga/README.md)
- [FPGA core](../hardware/fpga/core/README.md)
- [software](../software/README.md)
- [verification](../verification/README.md)
- [web and browser emulator](../web/README.md)

## Canonical versus historical

Current guides describe the repository as it exists now. The
[`log/`](log/) directory is a historical build journal: entries retain the
claims, terminology, and plans that were accurate to the author at the time.
Some therefore describe abandoned word widths, register designs, old ISA
counts, or preview-only integrations.

Use the [current journal index](log/README.md), which labels the collection and
links newer entries missing from the original welcome dispatch. Do not use a
dated entry to establish present status unless a current guide confirms it.

## Machine-readable contracts

| Path | Authority |
|---|---|
| [`isa/tomato.v1.csv`](isa/tomato.v1.csv) | Burned control-ROM rows |
| [`isa/tomato.v1.pseudo.csv`](isa/tomato.v1.pseudo.csv) | Assembler-only expansions |
| [`isa/datapath-audit.csv`](isa/datapath-audit.csv) | Derived implementation checklist |
| [`isa/lut.csv`](isa/lut.csv) | ALU LUT primitive catalog |
| [`isa/profiles.csv`](isa/profiles.csv) | Architecture-mapping exploration data |

Generated burns, memory images, screenshots, and packaged artifacts are
derivatives or evidence, not editable authorities.

## Focused checks

```bash
python3 tools/gen_microcode_v1.py --check
python3 software/assembler.py --selftest
make -C hardware/fpga/core burn-check
```

The first two check the ISA and assembler contracts. The third checks the FPGA
burn against the ISA source. Full simulation and hardware programming are
separate activities.

## Other references

- [`alu/`](alu/) contains the typeset ALU reference sources.
- [`nl-grammar.md`](nl-grammar.md) defines the deterministic controlled
  language used by local compute tooling.
- [`remote-compute-preview.md`](remote-compute-preview.md) records a
  simulation-only integration checkpoint; it is not current deployment proof.
- [tomato.tmarhguy.com](https://tomato.tmarhguy.com/) is the public narrative
  surface and may differ from the working tree until deployed.

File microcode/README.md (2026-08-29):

# Tomato — Microcode

<p align="center"><strong>Per-board EEPROM images · packed from the ISA CSV.</strong></p>

 

Per-board 8-bit EEPROM images for Tomato control decode. Digital format: `v2.0 raw`.

**Authority (512 rows):** [`docs/isa/tomato.v1.csv`](../docs/isa/tomato.v1.csv)

**Project map:** [Root README](../README.md) · [ISA](../docs/isa/README.md) · [FPGA burn](../hardware/fpga/core/README.md)

<p align="center">
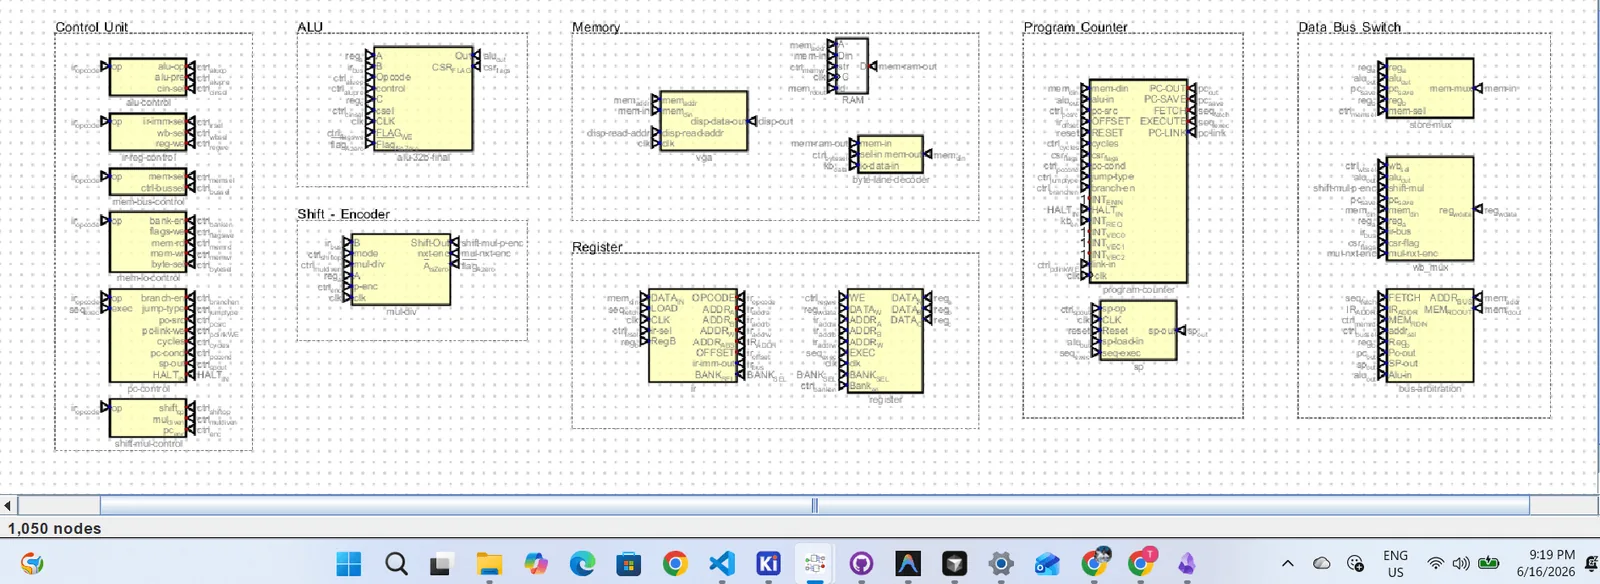
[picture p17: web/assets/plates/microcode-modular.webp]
Modular microcode control boards
  
</p>
<p align="center"><em>Modular decode · local EEPROMs travel with the datapath</em></p>

```bash
python3 tools/gen_microcode_v1.py              # pack hex + mem from the CSV
python3 tools/burn_microcode_to_digital.py     # optional Digital board burn
```

Also writes `$readmemh`-ready `*.mem` under `microcode/` and `hardware/fpga/core/tb/mem/`.

| File | Board | Fields |
|---|---|---|
| `alu_control_1.hex` | ALU | `alu_op[7:0]` → lutA / lutB |
| `alu_shift_control.hex` | ALU | `csel[2:0]`, `flag-we`, `shift_op[5:4]`, `mul_div_en`, `pc_enc` |
| `ir_reg_control.hex` | IR/reg/WB | `ir_imm_sel[3:0]`, `wb_sel[6:4]`, `reg_we[7]` |
| `mem_bus_control.hex` | Mem bus | `ctrl_bussel[2:0]`, `alusel[3]` |
| `mem_io_control.hex` | Mem I/O | `bank_en`, `mem_rd`, `mem_wr`, `byte_sel[6:3]` |
| `pc_control.hex` | PC | `branch_en`, `jump_type`, `pc_src[4:2]`, `pc_link_we`, `cycles[7:6]` |
| `pc_sp_mul_control.hex` | PC/SP | `pc_cond[2:0]`, `sp_op[5:4]` |
| `shift_mul_control.hex` | Shift/mul (spare) | `shift_op[1:0]`, `mul_div_en` |

## Legacy

Pre-v1 **1024-row** images: [`legacy-1024/`](legacy-1024/).

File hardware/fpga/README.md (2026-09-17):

# Tomato FPGA

This directory contains the complete Tomato machine for the Digilent Nexys
A7-100T (`xc7a100tcsg324-1`) plus an independent display bring-up project.

<p align="center">
  Nexys A7 used by FPGA Tomato
</p>

## Projects

| Project | Purpose |
|---|---|
| [`core/`](core/) | Complete 32-bit Tomato CPU, Tomato OS, board harness, and Icarus tests |
| [`hdmi_test/`](hdmi_test/) | Independent 640×480 display/pinout bring-up |

The complete machine lives in `core/`. Current register, ISA, OS, and clock
facts are maintained in [`../../docs/status.md`](../../docs/status.md); the
bring-up projects are separate designs and do not extend the core's feature
claims.

The `FREQ_MHZ := 90` build setting is a nextpnr timing target, not the runtime
CPU frequency and not a hardware-performance claim.

## Build flows

The default flow is:

`Yosys → nextpnr-xilinx → Project X-Ray`

Programming uses `openFPGALoader`. An optional Linux-only Vivado batch target
is available for the same core and board. Neither build route proves that a
board is currently programmed.

One-time open-source setup:

```bash
make -C hardware/fpga/core setup
```

Build from the repository root:

```bash
make fpga
```

Or build the core directly:

```bash
make -C hardware/fpga/core fpga
```

The hardware-changing programming step is deliberately separate:

```bash
make fpga-program
```

After changing the ISA or OS, regenerate the burn before synthesis:

```bash
make -C hardware/fpga/core burn BOOT=tomato_os
```

## Focused simulation

No FPGA toolchain is required for the Icarus checks:

```bash
make -C hardware/fpga/core burn-check
make -C hardware/fpga/core os
make -C hardware/fpga/core test
```

Simulation results must be labeled RTL simulation. Building or simulating is
not evidence of physical execution.

## Layout

| Path | Contents |
|---|---|
| [`common.mk`](common.mk) | Shared open-source build rules |
| [`scripts/`](scripts/) | Toolchain setup and environment |
| [`core/rtl/`](core/rtl/) | Machine RTL |
| [`core/rtl/board/`](core/rtl/board/) | Board clocks, reset, display, buttons, and seven-segment harness |
| [`core/tb/`](core/tb/) | Unit, program, OS, and integration testbenches |
| [`core/constr/`](core/constr/) | Nexys A7 constraints |
| [`hdmi_test/`](hdmi_test/) | Standalone display bring-up |

Generated `.tools/`, `build/`, and `sim/` directories are not source
authorities.

## Continue

- [FPGA core](core/README.md)
- [Architecture](../../docs/architecture.md)
- [Tomato OS](../../software/os/README.md)
- [ISA](../../docs/isa/README.md)
- [Current status](../../docs/status.md)

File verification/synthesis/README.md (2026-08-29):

# ALU synthesis — SkyWater 130nm HD

<p align="center"><strong>Yosys + ABC characterization of the Dual-LUT 32b ALU.</strong></p>

 

Open-source **ASIC characterization** of the Tomato 32-bit ALU: the Digital-export netlist [rtl/alu-32b-final.v](rtl/alu-32b-final.v) mapped to **sky130_fd_sc_hd** standard cells with Yosys + ABC, then measured for gate area, cell count, logic depth, and carry-chain timing. This is not tape-out sign-off. It answers: if this Verilog were silicon on a standard open PDK, how big and how fast is the datapath?

The discrete bench runs at breadboard speeds; this flow reports what the **same logic** looks like at 130nm. Source schematic: [alu-32b-final.dig](../../hardware/digital/modules/alu-32b-final.dig). Functional sign-off lives in [verification/README.md](../README.md).

**Project map:** [Verification](../README.md) · [Benchmark](../../test/README.md) · [Root README](../../README.md)

---

## Table of Contents

- [Results at a glance](#results-at-a-glance)
- [Why this path is shallow](#why-this-path-is-shallow)
- [What each layer measures](#what-each-layer-measures)
- [Layout](#layout)
- [Netlist policy](#netlist-policy)
- [Run synthesis](#run-synthesis)
- [Done checklist](#done-checklist)
- [Related docs](#related-docs)
- [Author](#author)

---

## Results at a glance

**As of August 2026** | Corner **TT 25C 1.8V** | Tool **Yosys 0.67** + ABC

| Metric | Value | Notes |
|---|---|---|
| Chip area | **6531 um^2** | Top module alu-32b-final |
| Sequential area | **9.81%** | Flag latches inside alu_8b_final |
| Mapped cells | **512** | sky130_hd after dfflibmap + ABC |
| Wires / wire bits | 3193 / 4890 | Post-map netlist |
| Ports / port bits | 1830 / 3045 | Includes slice hierarchy |
| LTP depth (top) | **4** | Inter-slice carry chain |
| Critical path (LTP) | lutA[7] through cout0-cout3 | Four 8b slices |
| Comb. delay (est.) | **4.12 ns** | Liberty typical arcs on carry path |
| Fmax comb. (est.) | **243 MHz** | Pre-route, no clock |
| Reg. cycle (est.) | **4.77 ns** | Comb + DFF overhead |
| Fmax registered (est.) | **210 MHz** | CLK to OUT budget |

### Dominant cell types

| Cell | Count | Area (um^2) |
|---|---|---|
| sky130_fd_sc_hd__mux4_2 | 136 | 3060 |
| sky130_fd_sc_hd__mux2_1 | 100 | 1126 |
| sky130_fd_sc_hd__xnor2_1 | 64 | 561 |
| sky130_fd_sc_hd__dfxtp_1 | 32 | 641 |
| sky130_fd_sc_hd__maj3_1 | 32 | 320 |
| sky130_fd_sc_hd__clkinv_1 | 52 | 195 |

Area and cell counts come from Yosys `stat -liberty`. Timing is a **pre-route liberty arc estimate** along the Yosys longest topological path (not OpenSTA slack). Re-run updates [reports/metrics.txt](reports/metrics.txt).

---

## Why this path is shallow

Tomato's ALU is built around **ripple carry across four 8-bit slices**, not a deep Wallace tree or multi-cycle flag reduction. The Yosys LTP report puts the top-level critical structure at exactly **four macro-blocks deep**: one hop per byte-slice cout, from the high bit of the lutA program bus into the first slice and rippling through the rest.

**The carry chain wins.** Flag logic and zero detect add sequential area (~10%) but do not dominate topological depth at the 32-bit boundary the way a 32-bit NOR tree would in a conventional ALU. Programmable LUT planes feed a nibble adder; arithmetic depth is the story.

**Registered vs combinational.** The exported netlist includes CLK, FLAG_WE, and flag latches on the top 8b slice. Combinational OUT can settle in one carry sweep; a clocked system budgets ~0.66 ns for DFF clock-to-Q and setup (~243 MHz comb vs ~210 MHz registered in the estimate).

---

## Carry topology awareness (Kogge-Stone)

The programmable datapath is **`sum = lutB(A,B,C) + lutA(A,B,C) + cin`** — two 3-input LUT mux planes per bit, then carry. We know that replacing the ripple 4b/8b chain with a **Kogge-Stone 32b prefix add** on the same planes is faster on this PDK.

A synthesis benchmark in [test](../../test/README.md) implements that variant (`alu-32b-koggestone.v`): same dual-LUT planes, KS carry, flags stripped for apples-to-apples speed/area.

| Metric | Ripple ALU (this flow) | ALU + Kogge-Stone ([test](../../test/README.md)) |
|---|---|---|
| Area | 6531 um^2 | **4704 um^2** (~28% smaller) |
| Cells | 512 | **378** (~26% fewer) |
| Comb. delay (est.) | 4.12 ns | **3.25 ns** (~1.27x faster) |
| Fmax comb. (est.) | 243 MHz | **308 MHz** |
| Fmax registered (est.) | 210 MHz | **256 MHz** |

Production Tomato keeps ripple carry for simpler byte-slice physical design and integrated flag/zero logic on the top 8b slice. The benchmark proves the LUT architecture is not the bottleneck — carry topology is.

---

## What each layer measures

| Step | Yosys pass | Proves / reports |
|---|---|---|
| Elaborate | read_verilog + hierarchy | Digital-export netlist elaborates clean |
| Map | synth, dfflibmap, abc | Generic logic to sky130_hd cells |
| Area | stat -liberty | um^2, cell mix, sequential fraction |
| Depth | ltp | Longest topological path (logic levels) |
| Export | flatten + write_verilog | Mapped netlist for optional STA |
| Timing est. | estimate_timing.py | Liberty NLDM typical arcs on LTP carry chain |

Pipeline script: [scripts/synth.ys](scripts/synth.ys). Liberty: `pdk/sky130_fd_sc_hd__tt_025C_1v80.lib` (fetch with scripts/fetch_lib if missing).

---

## Layout

Industry-standard open-source ASIC flow layout (RTL, scripts, PDK, reports):

```
verification/synthesis/
├── README.md
├── run.bat / run.sh         # Entry points (run from this directory)
├── rtl/
│   └── alu-32b-final.v      # Sole synthesis netlist (Digital export)
├── scripts/
│   ├── synth.ys
│   ├── extract_metrics.py
│   ├── estimate_timing.py
│   └── fetch_lib.ps1 / .sh
├── pdk/
│   └── sky130_fd_sc_hd__tt_025C_1v80.lib
├── constraints/
│   └── timing.tcl           # Optional OpenSTA
└── reports/                 # Generated (gitignored)
    ├── synth.log
    ├── metrics.txt
    ├── timing_est.txt
    └── synth_mapped.v
```

---

## Netlist policy

**One netlist, one top:** [rtl/alu-32b-final.v](rtl/alu-32b-final.v) is the only synthesis input. Export from [alu-32b-final.dig](../../hardware/digital/modules/alu-32b-final.dig) when the schematic changes. Copy to `verification/rtl/` for formal/UVM and to `synthesis/rtl/` for this flow.

There is **no** alu-32b-full.v in this tree. That name was a stale export from an older hierarchy (74157/74182 datapath, Opcode/control ports), not the current dual-LUT ladder. Synthesis and sign-off both use alu-32b-final.

| Copy | Path | Consumer |
|---|---|---|
| Synthesis | synthesis/rtl/alu-32b-final.v | Yosys to sky130 |
| Sign-off | verification/rtl/alu-32b-final.v | Formal, directed, UVM |

---

## Run synthesis

**Prerequisites**

1. [OSS CAD Suite](https://github.com/YosysHQ/oss-cad-suite-build/releases) (Windows: `C:\tools\oss-cad-suite\`)
2. PDK liberty in `pdk/` (if missing, run fetch_lib):

```powershell
cd verification/synthesis
powershell -File scripts/fetch_lib.ps1
```

```bash
cd verification/synthesis
bash scripts/fetch_lib.sh
```

**Run**

```powershell
cd verification/synthesis
.\run.bat
```

```bash
cd verification/synthesis
./run.sh
```

Or from the verification harness:

```bash
make synth
```

**Output:** `reports/synth.log`, `reports/metrics.txt`, `reports/synth_mapped.v`.

```powershell
Select-String "Chip area for top module" reports\synth.log
Select-String "Longest topological path in alu-32b-final" reports\synth.log -Context 0,5
```

---

## Done checklist

You are done with ASIC characterization when:

| Check | Command / artifact |
|---|---|
| Liberty present | `pdk/sky130_fd_sc_hd__tt_025C_1v80.lib` exists |
| Synthesis passes | `run.bat` or `make synth` exits 0 |
| Area reported | `reports/metrics.txt` shows chip_area_um2: 6531.264 |
| LTP depth = 4 | metrics.txt shows carry chain across four slices |
| Mapped netlist | `reports/synth_mapped.v` generated |
| README matches run | Metrics table reflects latest metrics.txt |

Clean generated artifacts: `make synth_clean`.

---

## Related docs

| Doc | Content |
|-----|---|
| [verification/README.md](../README.md) | ALU formal + UVM sign-off |
| [test/README.md](../../test/README.md) | Kogge-Stone + ALU+KS benchmark vs ripple ALU |
| [07 ALU board doc](../../hardware/kicad/boards/07_alu/README.md) | Physical dual-LUT PCB |
| [alu-32b-final.dig](../../hardware/digital/modules/alu-32b-final.dig) | Logic source of truth |
| [Root README](../../README.md) | Tomato architecture map |

---

## Author

**Tyrone Marhguy** — Computer Engineering '28, [University of Pennsylvania](https://www.upenn.edu/). Contact badges live on the [root README](../../README.md#author).

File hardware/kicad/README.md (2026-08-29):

# Tomato — KiCad

<p align="center"><strong>Numbered PCB lots for the 32-bit Dual-LUT machine.</strong></p>

 

Physical boards for Tomato. Logic authority stays in [Digital](../digital/README.md); these projects are fab and assembly. Lot **07** (`07_alu`) is on the iron.

**Project map:** [Hardware](../README.md) · [Boards](boards/README.md) · [07_alu doc](boards/07_alu/README.md) · Paper: [boards.html](https://tomato.tmarhguy.com/boards.html)

<p align="center">
  Tomato 07_alu — Dual-LUT slice in the round
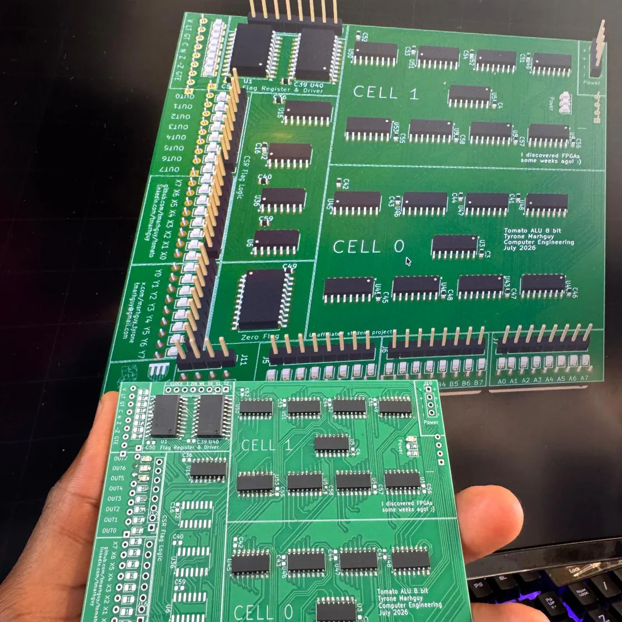
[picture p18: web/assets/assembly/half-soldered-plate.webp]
Tomato 07_alu — first population
  
</p>
<p align="center"><em>Lot 07 in the round &amp; on the iron · Dual-LUT slice · <a href="boards/07_alu/README.md">board doc</a></em></p>

<p align="center">
  Tomato ALU PCB — board render
  Tomato ALU PCB — top-layer layout
</p>
<p align="center"><em>Left: board render · Right: routed top copper</em></p>

```
kicad/
├── boards/     # 01_alu … 08_display — numbered lots
├── modules/    # Reusable subcircuits
└── README.md
```

| Lot | Path | Role | Status |
|-----|---|---|---|
| 01 | [01_alu/](boards/01_alu/) | Early ALU experiments | Historical |
| 02 | [02_shift_encoder/](boards/02_shift_encoder/) | Shift encoder + mul-div control | In design |
| 03 | [03_memory/](boards/03_memory/) | Memory, byte-lane, VGA | In design |
| 04 | [04_register/](boards/04_register/) | Register file, IR | In design |
| 05 | [05_program_counter/](boards/05_program_counter/) | PC, stack pointer | In design |
| 06 | [06_data_bus/](boards/06_data_bus/) | Data bus, wb_mux | In design |
| 07 | [07_alu/](boards/07_alu/) | Dual-LUT ALU PCB | **Populating** |
| 08 | [08_alu_fsm/](boards/08_alu_fsm/), [08_display/](boards/08_display/) | FSM bring-up, display | In design |

---

## Legacy — 8-bit transistor ALU (pre-Tomato)

> The notes below document the earlier discrete-transistor / modular board story (270×270 mm class designs, `main_logic`, `add_sub`, …). Paths and inventory there are **historical**. Living Tomato copper is the numbered lots above; Lot 07 is the Dual-LUT slice.

### KiCad PCB Design Files

**Complete hardware design for the 8-bit discrete transistor ALU**

This directory contains all KiCad schematic and PCB layout files for fabrication-ready hardware.

---

## Directory Structure

```
kicad/
├── boards/              # Complete board designs
│   ├── alu/             # Main 270×270mm ALU board (if monolithic)
│   ├── add_sub/         # Add/subtract module
│   ├── flags/           # Flag generation circuit
│   ├── main_control/    # Control decoder
│   ├── main_logic/      # Logic unit
│   └── led_panel/       # Display panels
├── modules/             # Reusable subcircuits
│   ├── gates/           # Logic gate implementations
│   ├── adder/           # Adder circuits (1-bit, 2-bit, 8-bit)
│   └── mux/             # Multiplexer modules
└── README.md            # This file
```

---

## Main ALU Board

**Design:** 270mm × 270mm combinational logic processor

### Specifications

| Parameter | Value |
|---|---|
| **Board Size** | 270mm × 270mm (10.6" × 10.6") |
| **Layers** | 2 (signal + ground) |
| **Transistors** | 3,488 (Hybrid: Discrete + equivalent ICs) |
| **Technology** | 5V logic, NMOS/PMOS pairs |
| **Power** | 5V @ 0.5-1A |
| **I/O** | 22 pins (8× A, 8× B, 5× FUNC, 1× GND) |
| **Outputs** | 12 pins (8× OUT, 4× FLAGS) |

### Board Sections

1. **Arithmetic Unit** (top-left)
   - 8-bit ripple-carry adder
   - XOR array for B input
   - 432 transistors

2. **Logic Unit** (top-right)
   - NAND/NOR/XOR arrays
   - PASS A/B buffers
   - 5:1 MUX
   - 352 transistors

3. **Selection Logic** (center)
   - 2:1 MUX (arithmetic vs logic)
   - Global inverter
   - 176 transistors

4. **Flag Generation** (bottom-left)
   - EQUAL comparator
   - LESS comparator
   - POSITIVE detector
   - COUT routing
   - ~240 transistors

5. **Control Decoder** (bottom-right)
   - FUNC[4:0] opcode decoder
   - Control signal generation
   - ~68 transistors

Main Logic Board
*Figure 1 - Main ALU logic board: 270×270mm with 3,488 transistors (Hybrid)*

**Evidence:** Physical PCB fabricated and assembled.

---

## File Formats

### KiCad Project Files

| Extension | Purpose | Version Control |
|---|---|---|
| `.kicad_pro` | Project settings | Track |
| `.kicad_sch` | Schematic | **Track (critical)** |
| `.kicad_pcb` | PCB layout | **Track (critical)** |
| `.kicad_sym` | Custom symbols | Track |
| `.kicad_mod` | Custom footprints | Track |
| `-backups/` | Auto-backups | Ignore |
| `fp-info-cache` | Footprint cache | Ignore |

### Export Formats

| Format | Purpose | Location |
|---|---|---|
| **PDF** | Documentation | Export as needed |
| **SVG** | Vector schematics | `../../web/assets/schematics photos svg/` |
| **Gerber** | Manufacturing | Generated on demand |
| **BOM** | Component list | `docs/build-notes/bom.md` |
| **STEP** | 3D mechanical | `web/glb exports/` |

---

## Board Designs

### Main Logic Board

**File:** `boards/main_logic/main_logic.kicad_sch`

Main Logic Schematic
*Figure 2 - Complete main logic schematic*

**Key Components:**
- 624 discrete transistors (plus 2,864 in ICs)
- 74HC157 2:1 MUX (2×)
- Power distribution network
- I/O headers

**Interfaces:**
```
Inputs:  A[7:0], B[7:0], FUNC[4:0], VCC, GND
Outputs: OUT[7:0], LESS, EQUAL, POSITIVE, COUT
```

**Evidence:** Complete schematic shows all signal paths.

### Add/Sub Module

**File:** `boards/add_sub/add_sub.kicad_sch`

Add/Sub Schematic
*Figure 3 - Add/subtract module with XOR array*

**Function:** Conditional B inversion for subtraction

**Components:**
- 8× XOR gates (96T)
- M control signal routing

**Logic:** B' = B XOR M

**Evidence:** XOR array enables efficient ADD/SUB implementation.

### Flags Board

**File:** `boards/flags/flags.kicad_sch`

Flags Schematic
*Figure 4 - Flag generation circuit*

**Flags generated:**
- EQUAL: A == B comparator (~100T)
- LESS: A < B magnitude comparator (~120T)
- POSITIVE: (OUT > 0) detector (~20T)
- COUT: Carry out routing (0T)

**Evidence:** Dedicated flag logic provides comparison results.

### Control Unit

**File:** `boards/main_control/main_control.kicad_sch`

Control Schematic
*Figure 5 - Control unit opcode decoder*

**Function:** FUNC[4:0] → {M, MUX_SEL, INV_OUT, LOGIC_SEL}

**Implementation:** Combinational decode logic (~68T)

**Evidence:** Control decoder translates opcodes to internal control signals.

---

## PCB Design Process

### Step 1: Schematic Capture

Schematic Design
*Figure 6 - Schematic capture in KiCad*

**Process:**
1. Create hierarchical design
2. Place components
3. Wire connections
4. Add power symbols
5. Annotate references
6. Run ERC (Electrical Rules Check)

### Step 2: PCB Layout

PCB Layout
*Figure 7 - PCB layout for ALU*

**Process:**
1. Import netlist
2. Define board outline (270×270mm)
3. Place components strategically
4. Route power rails (wide traces)
5. Route signals
6. Add ground plane
7. Run DRC (Design Rules Check)

### Step 3: Routing

Routing Demo
*Figure 8 - Click to watch: PCB routing demonstration*

**Routing strategy:**
- Power rails first (1mm+ traces)
- Critical signals (clock-free, so no priority)
- Minimize via count
- Maintain trace spacing (0.2mm min)

**Evidence:** Routing video shows systematic layout approach.

---

## Manufacturing

### Gerber Generation

**Process:**
```
KiCad → File → Fabrication Outputs → Gerbers
```

**Generated files:**
- Copper layers (Top, Bottom)
- Solder mask layers
- Silkscreen layers
- Drill files (.drl)
- Board outline

### PCB Ordering

**Recommended manufacturers:**
- **JLCPCB** - Economical, good quality
- **PCBWay** - Higher quality options
- **OSH Park** - USA-based, excellent quality

**Specifications to provide:**
- Board size: 270×270mm
- Layers: 2
- Thickness: 1.6mm
- Copper: 1oz
- Surface finish: HASL lead-free
- Silkscreen: White on green

---

## Assembly Notes

### Component Placement Order

1. **Smallest first:** Resistors, capacitors (if SMD)
2. **Transistors:** 3,488 total (624 Discrete pairs + 74xx ICs + Support)
3. **ICs:** 74HC157 multiplexers (use sockets)
4. **Headers:** I/O connectors
5. **LEDs:** Output indicators (last)

### Soldering Tips

- **Temperature:** 320-350°C for lead-free solder
- **Tip size:** Fine chisel (1-2mm) for transistor leads
- **Flux:** Use liberally for better flow
- **Inspection:** Magnification recommended
- **Testing:** Test subsystems before full integration

Component Placement
*Figure 9 - Component placement before soldering*

Soldering Progress
*Figure 10 - Hand soldering transistors (Total count: 3,488)*

**Evidence:** Assembly process documented step-by-step.

---

## Design Files

### Opening in KiCad

```bash
cd schematics/kicad/boards/main_logic
kicad main_logic.kicad_pro
```

**KiCad version:** 9.0.6 or later required

### Exporting

**Schematic PDF:**
```
File → Plot → Plot format: PDF
```

**Schematic SVG:**
```
File → Plot → Plot format: SVG
```

**PCB 3D View:**
```
View → 3D Viewer → File → Export → STEP
```

---

## References

- [Board Documentation](boards/README.md) - Individual board details
- [Modules](modules/README.md) - Reusable subcircuits
- [Architecture](../../docs/ARCHITECTURE.md) - System architecture
- [BOM](../../docs/build-notes/bom.md) - Bill of materials

---

**Last Updated:** 2026-01-16  
**KiCad Version:** 9.0.6+  
**Board Count:** 8 designs  
**Status:** Fabrication-ready

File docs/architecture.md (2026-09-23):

# Tomato architecture

Tomato is a 32-bit architecture centered on a Dual-LUT ALU. This document
describes the current design shared by the repository's editable schematics,
FPGA implementation, ISA contract, and software. For concise status and exact
claim boundaries, see [`status.md`](status.md).

## Scope

Tomato exists in several forms, which must not be conflated:

- The **discrete ALU slice** is physically assembled 74xx hardware. It proves
  the ALU construction, not a complete discrete computer.
- **FPGA Tomato** is the complete machine implemented on a Nexys A7-100T. It
  can boot Tomato OS and drive the display and controls.
- **Virtual Tomato** is a functional browser ISA emulator. It is neither
  cycle-accurate RTL nor physical hardware.
- **RTL simulation** runs the machine and testbenches locally with Icarus.

The complete discrete computer remains a goal.

## Datapath

The instruction register, general-purpose data path, registers, and ALU are
32 bits wide. The core is a multi-cycle Von Neumann machine.

```text
program counter → memory → instruction register
                         ↓
                  register file 3R1W
                         ↓
               dual-LUT ALU / shift / mul-div
                         ↓
                 writeback and memory
```

The current FPGA RTL declares a **256 × 32-bit physical register array**. Each
address combines three bank bits with a five-bit register field; `r0` is
hardwired to zero. Its asynchronous 3-read/1-write shape maps to distributed
RAM on the Artix-7.

Older journal entries describe a 32,768-register discrete-SRAM proposal. That
design required mirrored external SRAM, a seven-bit superbank latch, and
`SETBANK2`; none is present in the current FPGA RTL or burned ISA. The current
size is therefore an implementation and ISA choice, not a documented Artix-7
capacity limit. Authority:
[`hardware/fpga/core/rtl/regs.v`](../hardware/fpga/core/rtl/regs.v),
[`hardware/fpga/core/rtl/ir.v`](../hardware/fpga/core/rtl/ir.v), and
[`isa/tomato.v1.csv`](isa/tomato.v1.csv).

## Dual-LUT ALU

Each ALU bit applies two independently programmed three-input truth tables,
then combines their outputs through the arithmetic carry path:

```text
out = f(a, b, c) + g(a, b, c) + carry_in
```

The theoretical LUT/carry configuration space is not an instruction count.
The installed ISA is the subset named by the control ROM: **91 instructions
plus NOP, 92 burned rows** in a 512-row ROM.

The editable architecture source is under
[`hardware/digital/`](../hardware/digital/); the current FPGA realization is
under [`hardware/fpga/core/rtl/`](../hardware/fpga/core/rtl/); the burned
contract is [`isa/tomato.v1.csv`](isa/tomato.v1.csv).

## Instruction and control model

The 32-bit instruction word uses a 9-bit opcode and overlays operand,
immediate, branch, and jump fields according to instruction class. The opcode
addresses a 512-row control space. Burned rows cover ALU operations, memory,
control flow, shift, multiply/divide, and system behavior; unused rows are
safe NOP rows.

In the discrete design, decode is divided among local control boards so control
travels with the subsystem it drives. In FPGA Tomato, equivalent control is
implemented in RTL and generated burn tables. The machine-readable ISA wins
over prose when row names or counts disagree.

See [`isa/README.md`](isa/README.md) for editing and verification rules.

## Memory and I/O in FPGA Tomato

The FPGA machine uses word addressing. Its principal windows are:

| Window | Base word address | Purpose |
|---|---:|---|
| Data/program memory | `0x000000` | 16,384 × 32-bit program, data, and stack |
| Framebuffer | `0x300000` | 80 × 60 text tiles |
| Keyboard and timer | `0x780000` | Keycode, ready/consume, milliseconds, and CPU-frequency words |
| Dual-LUT compiler | `0x780080` | Fixed-example LUT-pair search registers |
| nRF8001 ACI mailbox | `0x780100` | Machine-side radio controller window |

The board harness provides 640×480 scanout, five-button input, clock/reset,
and seven-segment output. These board-specific facilities are kept outside the
machine RTL where practical.

## Clock language

The Nexys A7 oscillator is 100 MHz. FPGA Tomato divides it by 16, so the CPU
runs at **6.25 MHz** by default; the pixel clock is 25 MHz. The **90 MHz**
number in the build is nextpnr's configured timing target. It is not the CPU
runtime frequency and does not by itself prove operation on a board.

## Software stack

[`software/assembler.py`](../software/assembler.py) is a two-pass assembler
driven by the ISA CSVs. [`software/os/`](../software/os/) contains TOMATO OS
v3.0 and linked firmware modules. The current OS has 14 menu entries, including
Envelop and Compiler. See the [OS guide](../software/os/README.md).

## Authority map

| Question | Current authority |
|---|---|
| Architecture schematic | `hardware/digital/` |
| FPGA behavior | `hardware/fpga/core/rtl/` |
| Burned ISA | `docs/isa/tomato.v1.csv` |
| Pseudo-instructions | `docs/isa/tomato.v1.pseudo.csv` |
| OS version/menu | `software/os/*.s` |
| Current prose/status | `docs/status.md` |
| Historical rationale | `docs/log/` |

The full precedence and update procedure are in
[`documentation-policy.md`](documentation-policy.md).

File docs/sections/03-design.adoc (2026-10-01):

[[design]]
== Design

This chapter records the microarchitecture: how the RTL realizes the
machine in <<architecture>>.
It is an implementation description, not a second ISA.

=== Pipeline and control

The FPGA core is a multi-cycle machine, not a pipelined superscalar.
One instruction occupies the fetch, decode, register-read, execute, and
writeback resources in sequence; control is a 512-row microcode ROM
addressed by the 9-bit opcode.

[source,text]
----
IF:  PC -> memory -> IR
ID:  opcode -> 512-row control ROM -> control bundle
EX:  3R1W register read -> ALU / shift / mul-div / lane
WB:  writeback mux -> register file or memory / MMIO
----

Key RTL (authoritative over prose):

* `hardware/fpga/core/rtl/main.v` — top-level machine core
* `hardware/fpga/core/rtl/control.v` — control bundle and sequencing
* `hardware/fpga/core/rtl/pc.v`, `sp.v` — program counter and stack pointer
* `hardware/fpga/core/rtl/regs.v` — 256 x 32 physical array
* `hardware/fpga/core/rtl/alu.v` — Dual-LUT ALU plus carry chain
* `hardware/fpga/core/rtl/shift.v`, `muldiv.v`, `lane.v` — side units
* `hardware/fpga/core/rtl/bus.v`, `wb.v` — memory path and writeback mux

=== ALU and function search

The ALU computes `f(a,b,c) + g(a,b,c) + carry` per bit, where `f` and `g`
are independently programmed LUT3 functions.
Shift, multiply/divide, and byte/word lane operations bypass or extend the
ALU result through the writeback mux.

A bounded hardware compiler searches LUT pairs for one fixed example:

* enumerates all 65,536 `{lutB, lutA}` pairs;
* holds A, B, C, carry, and expected output fixed;
* stops at the first matching pair.

A hit verifies only that fixed example, not a full truth table or a
general function.
Authority: `hardware/fpga/core/rtl/compiler_fsm.v`.

[source,verilog]
----
// Per-bit Dual-LUT ALU sketch (simplified; see rtl/alu.v)
wire f = lut3_flut(a[i], b[i], c[i], lut_f);
wire g = lut3_glut(a[i], b[i], c[i], lut_g);
assign {carry[i+1], out[i]} = f + g + carry[i];
----

=== Clocking and reset

The Nexys A7 oscillator is 100 MHz.
The default RTL divides it for two synchronous domains:

[stem]
++++
f_{cpu} = \frac{100\ \mathrm{MHz}}{16} = 6.25\ \mathrm{MHz},
\qquad
f_{pixel} = \frac{100\ \mathrm{MHz}}{4} = 25\ \mathrm{MHz}
++++

The 90 MHz number in the build is the nextpnr place-and-route timing
target (`FREQ_MHZ := 90`), not an oscillator value, CPU frequency,
measured Fmax, or instruction rate.

TIP: When quoting clocks, always name the domain: board input, CPU
runtime, pixel clock, or routing target. Never collapse them to one number.

=== Board harness boundary

The board harness (`rtl/board/`) owns clocks, pins, keypad debounce, glyph
rendering, DVI scanout, and seven-segment output.
The machine core sees those facilities only through the windows in
<<memory-map-fpga>>.
This keeps board-specific wiring outside the CPU RTL and preserves the
same core across simulation, FPGA, and emulator front ends.

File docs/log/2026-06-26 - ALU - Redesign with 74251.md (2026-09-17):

In routing the ALU, I came across a realization that the fact that the 125 + 138 combination defeats the optimization i was looking for. In fact, I need 3 chips for a single ALU-cell; but the 74251 offers same logical capacity without the physical chance of contention. Over the 74151, the 74251 offers a stronger drive strength, which was my initial worry when designing with 74151. 

Logical changes are none, but routing and metrics of area, and performance (by bus length) are better with the 74251.

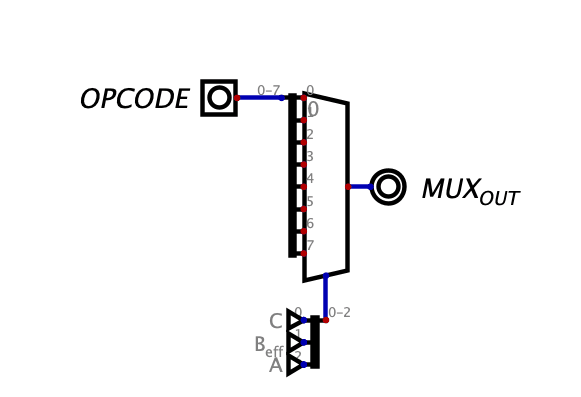
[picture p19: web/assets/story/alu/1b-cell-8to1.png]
Digital schematic of a one-bit ALU cell using an 8-to-1 multiplexer


*Retrospective technical illustration · opcode bits select the one-bit mux cell that motivated the 74251 redesign.*

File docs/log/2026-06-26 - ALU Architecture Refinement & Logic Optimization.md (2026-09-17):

**Refinement of Generate ($G$) and Propagate ($P$) Signals**

In the initial architecture, the logic generation for the 74182 look-ahead unit was bottlenecked by a naïve implementation using AND and XOR gates. This approach was inherently bloated, requiring a massive array of 74541 inverting drivers to handle the logic inversion, which created unnecessary routing congestion and footprint bloat.

I have overhauled this logic layer to prioritize efficiency and routing symmetry:

- **Logical Optimization:** By swapping the AND gates for NAND gates, I have eliminated the need for the redundant 74541 inverter bank.
    
- **Inverter Consolidation:** To maintain a clean signal path, I am now utilizing the spare gates within existing NAND packages as single-input inverters (via the identity $\text{NAND}(a, a) = \neg a$). This approach bypasses the complexity of XNOR configurations, which would have introduced open-drain headaches and required tedious pull-up resistor management.
    
- **Result:** This optimization is a net gain for board "Fractal Competence," reducing the footprint requirement by approximately 8 inverting driver chips and simplifying the trace density significantly.

**74283 Integration**

The core arithmetic logic has been transitioned to a 74283-based implementation. The 32-bit ALU is now modularized into eight discrete 4-bit slices, with each slice paired to a dedicated 74283 chip. This allows for a clean, repetitive layout in KiCad that mirrors the natural 4-bit flow of the logic, facilitating shorter signal paths and improved timing stability for higher theoretical MHz target.

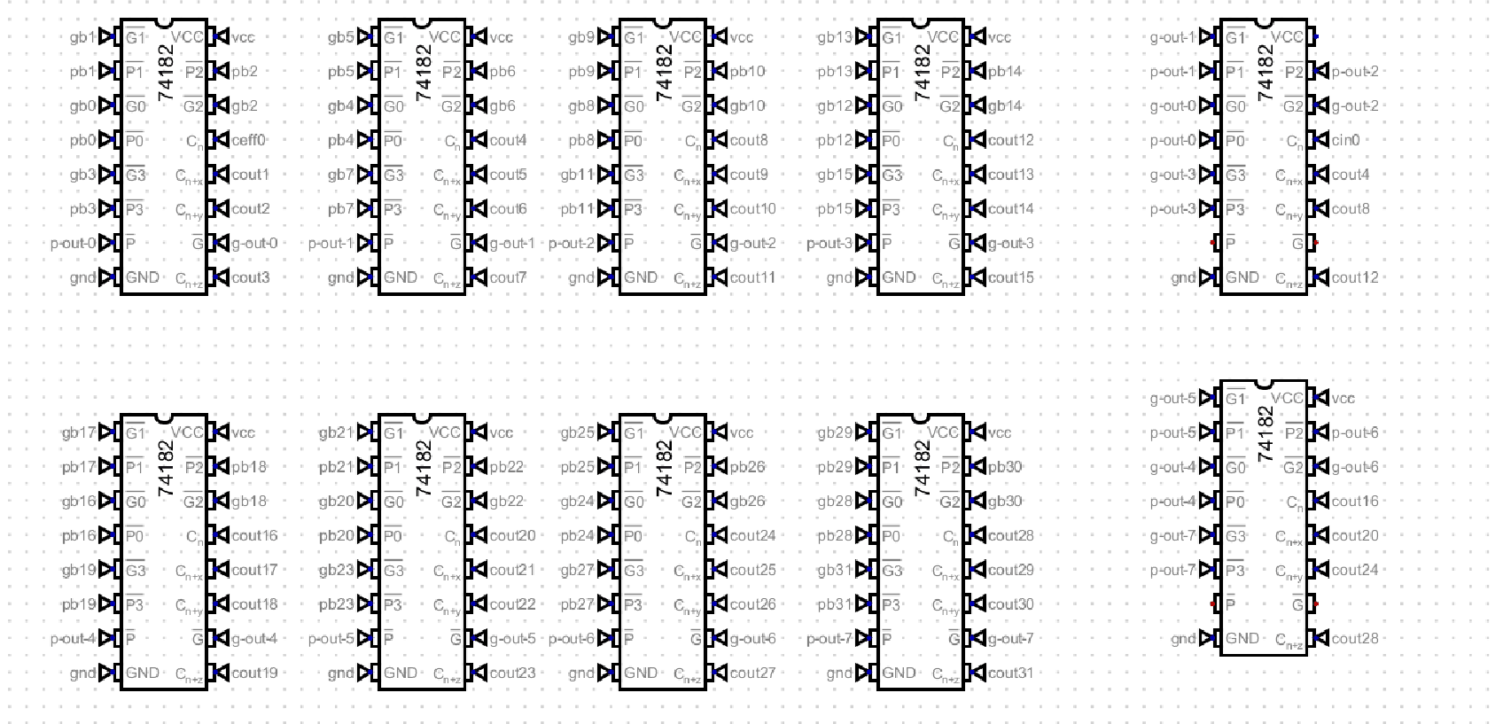
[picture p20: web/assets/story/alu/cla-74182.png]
Digital schematic wall of 74182 carry-lookahead chips


*Retrospective technical illustration · the carry-lookahead spine before NAND consolidation and localized 74283 slices reduced routing pressure.*

The routing is now strictly localized to these slices, aligning perfectly with the intended hardware-software co-design goals.

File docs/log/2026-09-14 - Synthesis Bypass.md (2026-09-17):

# Synthesis Bypass

I have spent the entire day, and much of that was waiting on synthesis, routing, and bitstream generation! In one case, I took a walk to bike around and after 36 mins, it was still running.

Fast iteration needs something more. As it is, I have already proven that Tomato works extensively. To iterate on Envelop, I have designed a Python preview script to allow me to interact with the code written, with button keys, like I would if the same code were burned to the FPGA.

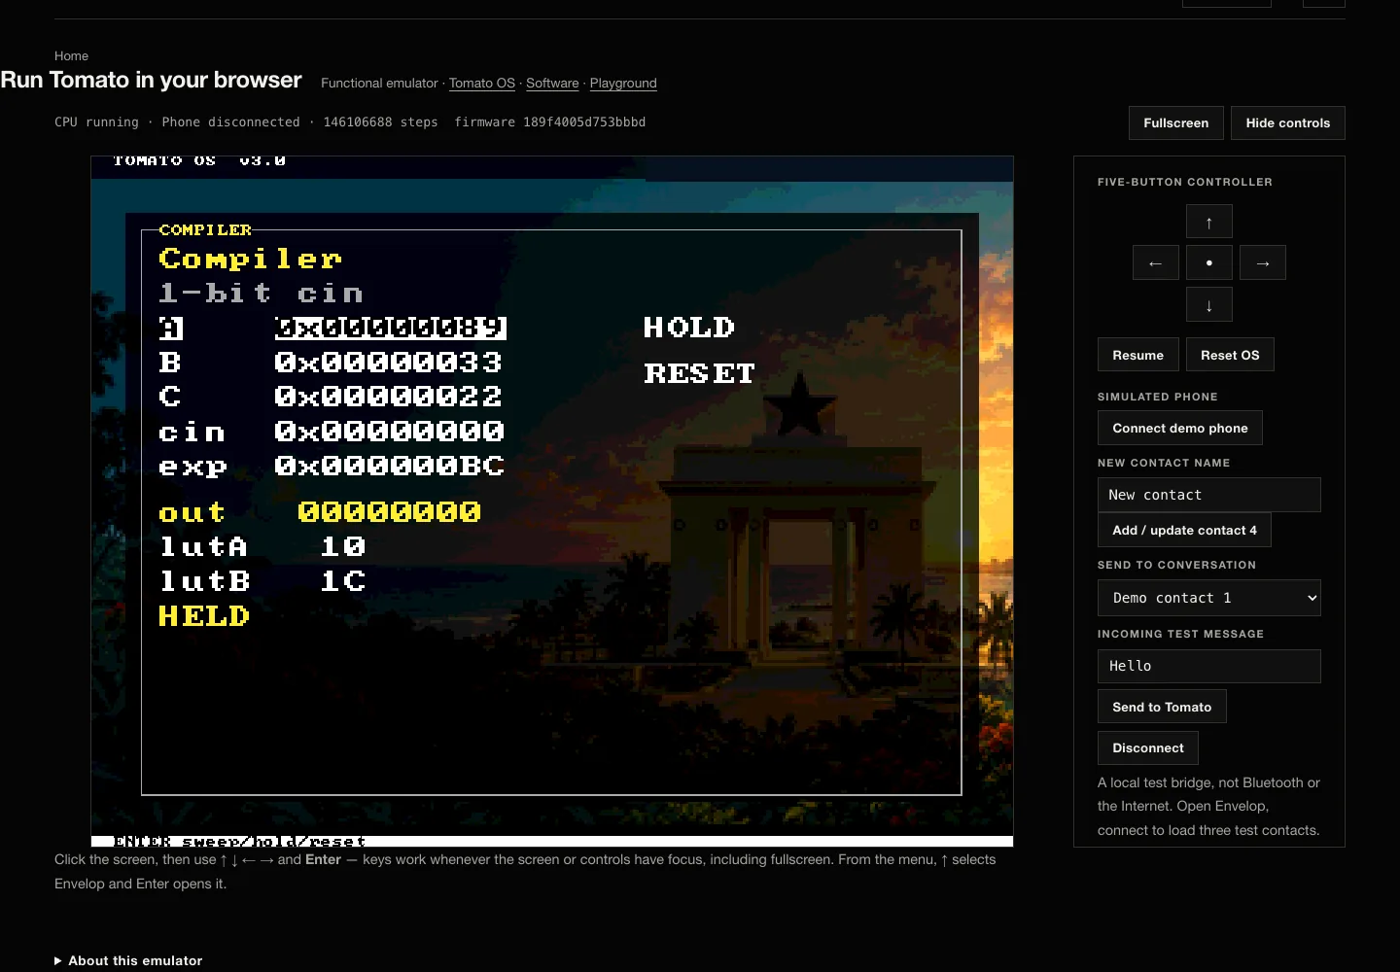
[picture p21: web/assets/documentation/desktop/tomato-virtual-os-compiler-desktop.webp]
Compiler screen running inside Tomato OS in the desktop Virtual Tomato emulator


*Browser emulation · the generated OS image in the functional CPU emulator; this preview shortens iteration but is not physical FPGA execution.*

This has been a tough friction point, and initially with my frustration with Vivado ([Exploring Beyond Vivado](<./2026-08-28%20-%20Exploring%20Beyond%20Vivado%20-%20Open-Source%20Synthesis%20Pivot.md>)), I lamented on the cycle taking forever — but I had not worked with FPGA enough to fully appreciate it if I skipped those layers into, say, a Python preview. But now, I have built sufficient base intuition to skip to Python.

This Python preview will act like a GitHub feature branch :) Maybe it took me too long to find this friction point and eliminate it! The realization of the hours this workflow will save me thrills me, but leaves me with at least two seemingly orthogonal thoughts:

- **Why didn't I think of this any earlier, and does the past time I put in go to waste?** I would answer that sometimes, our attentions are all in another direction and we don't focus on another. Also, until there's a real friction, you won't realize. In fact, before today, the whole workflow took at most 4 mins or less from code to bitstream on FPGA. Only today did I have to wait for so long, and eventually found an amortized way out. No time therefore has gone to waste, as I got to experience the workflow consistently — I even keep debugging the Makefile if there is an issue on different machines.
- **Why I never worked with others — maybe they would have shared insights that would lead to earlier thoughts on a preview mechanism.** Interesting fact is I love working with people, especially when they know their stuff too. In fact, I always allude to my high school, Achimota School science and math class. Everyone was so smart in their own ways, and that culture of excellence made the impossible on the outside world feel normal, a place where quirkiness from curiosity was allowed. In the case of Tomato, it so happens it always started as a personal learning experience — I wanted to understand computers — until it grew bigger and bigger. I've considered several times "recruiting interns", but the problem is the learning curve the project has reached. How do I explain building a computer from scratch (transistor level), combining it with 7 other custom-built boards, modular control, custom ISA, custom OS, custom hex firmware and assembler, custom app, the website flow, KiCad, routing, fabrication, soldering, FPGA toolchain, software simulation, without derailing my progress? I argue that there is a fine line between teaching and growing — but after so long, it'd take more to teach than to just finish. But granted, doesn't it make more sense that if you took a book to learn, you don't feel that pressure to "call" someone to sit next to you to view the same book? Everyone has their own paths to follow, and if most people wanted to, they could also join. It's more nuanced as I've framed, but Tomato has been fun. All this from the realization of seeking efficiency that Python just offered!

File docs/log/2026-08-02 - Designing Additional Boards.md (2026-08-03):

# Designing additional boards

**Date:** 2026-08-02  
**Status:** In progress — peripheral PCB design  
**Related:** [Falling back to 32b](2026-07-31%20-%20Falling%20back%20to%2032b.md) · [The lingering catch](2026-07-31%20-%20The%20lingering%20thoughts.md) · [07 ALU board doc](../../hardware/kicad/boards/07_alu/README.md)

---

## Context

I am pushing to design the remaining boards.

I had assumed that the most complicated one to design was the main board — the **ALU** — which is done and routed ([`07_alu`](../../hardware/kicad/boards/07_alu/README.md)). The next thing is everything else: register file, memory, PC/stack, data bus, shift/mul-div. The ALU was the deep combinational problem; what is left is mostly **32-bit plumbing** — mux trees, decode fanout, and connectors that do not fight the floor plan.

That is the plan [from last week](2026-07-31%20-%20The%20lingering%20thoughts.md): while the ALU fab runs, design slices that ship in the final machine instead of a throwaway FSM.

---

## Starting with multiplexers

The first slice I am tackling is the **multiplexers** on the data path — writeback mux, bus arbitration, and the glue that ties ALU, memory, and register ports onto one 32-bit highway.

A naïve 32-bit mux bank (one huge `74257` tree per source, every bit routed independently) costs **hundreds of millimetres** of trace and real estate. The approach for Tomato:

1. **Bus drivers** (`74AC125` / tri-state family) on each contributor — ALU result, memory read, PC+1, shift/mul, etc.
2. **Matched decode enables** from the modular control boards — only one driver active per phase, same idea as the [ALU display scan chain](2026-06-19%20-%20ALU%20segment%20display%20design.md) (one hot index, shared bus).
3. **KiCad target:** [06_data_bus](../../hardware/kicad/boards/06_data_bus/) — `wb_mux.kicad_sch`, `bus_arbitration.kicad_sch`, tied to Digital [`wb_mux.dig`](../../hardware/digital/modules/wb_mux.dig) and [`bus-arbitration.dig`](../../hardware/digital/modules/bus-arbitration.dig).

Digital already has the behavior; the board work is making the 32-bit fanout **physically tolerable**.

---

## Contention and timing

Contention is a real issue on a shared tri-state bus — two drivers fighting the same line is not theoretical.

But I am not running at GHz. At breadboard / bring-up clock rates, the window where two enables overlap badly is small. From earlier calculations, the chance of meaningful contention during switching is **~1%**, or more accurately **under 5%** of transitions — acceptable for lab bring-up if decode is one-hot and enables are never deliberately stacked.

Heat from brief overlap at these speeds should be ok. Production hygiene still matters: **one active driver per bus**, decode timed to the sequencer phases documented in [Load Store Pipeline Analysis](2026-06-11%20-%20Load%20Store%20Pipeline%20Analysis.md).

---

## Board queue (after ALU)

| Board | KiCad | Digital anchor | Notes |
|---|---|---|---|
| **06** data bus | [06_data_bus/](../../hardware/kicad/boards/06_data_bus/) | `wb_mux`, `bus-arbitration` | **Current focus** — mux + drivers |
| 04 register | [04_register/](../../hardware/kicad/boards/04_register/) | `register.dig`, `ir.dig` | 3R1W, 32 GPR × 8 banks |
| 05 PC / SP | [05_program_counter/](../../hardware/kicad/boards/05_program_counter/) | `program-counter.dig`, `sp.dig` | Fetch address source |
| 03 memory | [03_memory/](../../hardware/kicad/boards/03_memory/) | `memory.dig`, `byte-lane-decoder` | Load/store path |
| 02 shift / mul-div | [02_shift_encoder/](../../hardware/kicad/boards/02_shift_encoder/) | `mul-div.dig`, `shift-mul-control` | [Priority-encoder mul](2026-06-15%20-%20Multiplication%20and%20Division.md) |
| 08 display / FSM | [08_display/](../../hardware/kicad/boards/08_display/), `08_alu_fsm` | `alu-display-control` | Bench debug |

Control ROM boards ([microcode modularization](2026-06-16%20-%20Microcode%20Control%20Modularization.md)) ride with their datapath slices — not a separate queue item.

---

## Open questions

- One consolidated **06_data_bus** PCB vs split wb_mux and arbitration across connectors?
- Which `74xx` driver family on the 32-bit backplane — `AC125` vs `HC125` vs registered enables for cleaner turn-off?
- Order after mux: register file (loopback tests) vs memory (load/store integration)?
- Re-run contention estimate at target max clock once sequencer timing is nailed down.

---

## Lean recommendation (today)

Finish the **mux + driver** plan on `06_data_bus` in KiCad first — it unblocks every other board that needs to read or write the shared 32-bit word. Keep enables decode-driven and one-hot; do not sprawl a discrete 32-bit mux forest across the whole CPU footprint.

The ALU was the hard part. The rest is wiring Tomato's existing simulation into boards that fit the bench.

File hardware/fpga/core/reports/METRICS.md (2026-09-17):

# Tomato FPGA metrics (evidence log)

Runtime clocks and CPI below are reproducible from in-tree source and tests.
The post-route resource/Fmax figures are a recorded prior run; its raw
nextpnr log is not checked in, so treat them as an evidence note, not as a
result reproducible from this file alone.

## Full CPU — `hardware/fpga/core`

Post-route on `xc7a100tcsg324-1`, top `nexys_top`, from `nextpnr-xilinx`. Reproduce with `../scripts/env.sh make fpga` from `hardware/fpga/core`; the log is not checked in, `build/` is gitignored.

| Metric | Value |
|---|---|
| Flow | yosys → nextpnr-xilinx → prjxray → openFPGALoader (no Vivado) |
| Synthesis options | `synth_xilinx -flatten -abc9 -nodsp` |
| Board oscillator | 100 MHz (Digilent pin E3) |
| CPU clock | **6.25 MHz** (100 ÷ 16, `CPU_DIV_LOG2 = 4`) |
| Pixel clock | **25 MHz** (100 ÷ 4), 640×480 nominal-60-Hz timing: 800×525 totals produce **~59.52 Hz** |
| Bitstream | `build/nexys_top.bit`, 3.8 MB |

### Utilisation

| Resource | Used | Available | % |
|---|---|---|---|
| LUTs | 8852 | 126800 | 6% |
| Flip-flops | 323 | 126800 | 0% |
| CARRY4 | 508 | 15850 | 3% |
| RAMB36E1 | 20 | 135 | 14% |
| RAMB18E1 | 1 | 270 | 0% |
| BUFGCTRL | 3 | 32 | 9% |
| DSP48E1 | 0 | 240 | 0% |
| IOB | 71 | 630 | 11% |

The block RAM is 16K × 32 of data memory (20 RAMB36) plus the glyph ROM. No DSPs by choice — see the third section of [core/README.md](../README.md#three-concessions-to-the-fabric).

### Timing

The current Makefile passes `--freq 90`. That is the configured
place-and-route timing target for named clocks, not a runtime frequency or a
measured Fmax. The table below records a prior nextpnr run; no raw log is
checked in.

| Clock | Runs at | Post-route Fmax | Margin |
|---|---|---|---|
| `cpu_clk` | 6.25 MHz | **104.18 MHz** | 16× |
| `pix_clk` | 25 MHz | **189.93 MHz** | 7.6× |

The old Vivado project closed against a relaxed 125 ns (8 MHz) constraint and
never had a checked-in report. The current XDC instead constrains the real
100 MHz input oscillator with a 10 ns period. The recorded CPU-domain Fmax
above is not the 6.25 MHz runtime clock and is not the 90 MHz build target.

## Icarus CPI — `hardware/fpga/core` (`make cpi`)

Sim-only: cycle + fetch-retire from reset release to halt. **Not** a board MHz claim.

| Program | Cycles | Instr retired | CPI |
|---|---|---|-----|
| counter | 68 | 34 | **2.000** |
| fib | 134 | 66 | **2.030** |
| collatz | 2096 | 1048 | **2.000** |
| call | 12 | 6 | **2.000** |
| bytes | 23 | 9 | **2.556** |
| softops | 20 | 9 | **2.222** |

Mixed average ≈ **2.13**. Microcode `cycles` is 1 (F+E) or 2 (F+E+M). Full table: [CPI.md](CPI.md).

The unweighted mean of these six samples is ~2.13 CPI. Applying that simulated
instruction mix to the configured 6.25 MHz clock projects roughly **2.9
million instructions/s**. This is a workload-derived calculation, not measured
board throughput, emulator speed, or a universal operations/s rating. The
roughly 11 ms desktop-paint figure is likewise a cycle-model projection, not a
wall-clock FPGA measurement.

## ALU Sky130 (not the FPGA CPU)

See [verification/synthesis/README.md](../../../../verification/synthesis/README.md): **6531 µm²**, **512** cells, **~210 MHz** registered estimate (TT liberty, pre-route).

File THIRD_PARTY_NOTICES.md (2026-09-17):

# Third-party notices

Tomato is offered under `Apache-2.0 WITH SHL-2.1`; see [LICENSE](LICENSE),
[LICENSE-APACHE](LICENSE-APACHE), and [NOTICE](NOTICE). The items below are
separate dependencies, tools, data, or reference media. Their own terms remain
authoritative.

## Material stored or generated in this repository

| Material | Location / provenance | Terms and decision |
|---|---|---|
| ENIAC photograph | `web/assets/engravings/eniac-penn.jpg`; U.S. Army photograph via [Wikimedia Commons](https://commons.wikimedia.org/wiki/File:Classic_shot_of_the_ENIAC.jpg) | Public-domain U.S. government photograph; source attribution is preserved in `web/ATTRIBUTION.md`. |
| Printable ASCII font ROM | Generator `tools/gen_font_rom.py` and generated `font_rom.v` | Project-authored data under Tomato's project licence unless a more specific notice appears in the generated file. |

Nordic-generated nRF8001 ACI setup bytes are intentionally not stored or
redistributed. The repository ships only independently written transport RTL
and project-authored simulator placeholders. Those placeholders do not
configure a physical radio.

## Tools and fetched dependencies

| Component | Location / use | Upstream licence |
|---|---|---|
| Digital by Helmut Neemann | Authoring/viewing `.dig` schematics | [GPL-3.0](https://github.com/hneemann/Digital/blob/master/LICENSE) for the application. Running a GPL tool does not by itself relicense Tomato-authored `.dig` design files. |
| KiCad | Authoring `.kicad_*` projects and renders | GPL-3.0 for the application. Tomato-authored board sources and renders remain under their stated project terms. |
| SkyWater 130 nm PDK liberty | `verification/synthesis/pdk/` (fetched and gitignored) | [Apache-2.0](https://github.com/google/skywater-pdk); the fetched PDK's own notices and terms apply. |
| OSS CAD Suite | `hardware/fpga/.tools/` (fetched and gitignored) | Mixed licences, including GPL, ISC, and MIT; inspect the bundled notice for each component. |
| nextpnr-xilinx and Project X-Ray database | Fetched through the FPGA flow | ISC for nextpnr; Apache-2.0 for Project X-Ray/prjxray-db. |
| Project X-Ray tools | `hardware/fpga/.tools/prjxray` (built locally and gitignored) | [Apache-2.0](https://github.com/f4pga/prjxray). |
| GitHub Actions | `.github/workflows/` | Each action retains its upstream licence; workflow references are commit-pinned for reproducibility. |

Generated schematics, renders, bitstreams, databases, and reports can contain
or depend on third-party material. Do not infer redistribution permission from
the licence of the tool that produced them. Review the relevant upstream terms
before redistributing fetched dependencies or their embedded data.

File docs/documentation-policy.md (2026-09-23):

# Tomato documentation authority

This policy defines which source wins when Tomato documentation disagrees.
Current status and public wording start at [`status.md`](status.md).

## Authority order

1. **Executable/editable design sources**
   - architecture: `hardware/digital/`
   - FPGA implementation: `hardware/fpga/core/rtl/`
   - operating system: `software/os/*.s`
   - browser emulator behavior: `web/js/tomato-cpu.js`
2. **Machine-readable contracts**
   - burned ISA contract: `docs/isa/tomato.v1.csv`
   - assembler pseudos: `docs/isa/tomato.v1.pseudo.csv`
   - generated web-image format: `tools/build_web_image.py`
3. **Consistency generators and tests**
   - `tools/gen_microcode_v1.py --check`
   - `software/assembler.py --selftest`
   - focused testbenches and web tests
4. **Canonical current prose**
   - `docs/status.md`
   - focused subsystem documentation that cites the sources above
5. **Narrative surfaces**
   - root README and `web/`
6. **Historical records**
   - `docs/log/`

Generated Verilog burns, assembled memory files, web data images, screenshots,
and packaged artifacts are evidence or derivatives, not editable authorities.
Regenerate them from source and identify their provenance. A dated journal
entry remains valid as history but must not override current code or
`docs/status.md`.

## Claim rules

- Pair mutable numerical claims with their source path or generate them.
- Use the exact ISA wording: **91 instructions plus NOP, 92 burned rows**.
- Use **TOMATO OS v3.0** for the OS and **Desktop v1.2** only for the workspace
  UI revision. Count the current menu as 14 entries.
- Keep routing target, oscillator, pixel clock, and CPU runtime clock distinct.
- Never use an emulator or RTL-simulation result as evidence of physical
  execution.
- Never call hardware “online” without a current lease or equivalent live
  observation.
- Describe the complete discrete machine as a goal. Describe only the
  physically assembled Dual-LUT ALU slice as built.
- Preserve hardware-versus-virtual provenance in captions, result labels, alt
  text, and metadata.

## Status words

- **Implemented:** present in current source.
- **Verified:** a named reproducible check passed against that source.
- **Hardware-demonstrated:** direct evidence identifies an FPGA or physical
  assembly and the operation shown.
- **Deployed:** the checked artifact or revision is confirmed at its public
  endpoint.
- **Preview:** intentionally incomplete or non-production behavior.
- **Planned:** no current implementation claim.

Do not substitute one status for another. In particular, “implemented” does
not imply deployed, and “verified” without a target does not imply hardware.

## Updating canonical facts

When a source change alters a fact:

1. update the machine-readable or executable authority;
2. run its focused consistency check;
3. update `docs/status.md` in the same change;
4. update current subsystem docs, README, and site copy;
5. leave historical logs intact, adding a short current/superseded note only
   when readers could otherwise mistake one for present status.

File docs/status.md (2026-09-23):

# Tomato canonical facts and status

Last verified from repository sources: 2026-09-16.

This file is the short, current factual backbone for Tomato documentation. It
describes what the repository proves; it does not turn plans, historical
journal entries, or an available build target into a deployment claim.

## Canonical vocabulary

- **Tomato** is the 32-bit architecture and project as a whole.
- **Discrete ALU slice** means the physically assembled 74xx Dual-LUT ALU
  hardware shown in the repository. Do not describe it as a complete discrete
  computer.
- **FPGA Tomato** means the complete Tomato machine implemented on the Nexys
  A7-100T; it boots the assembly-written Tomato OS. A reply produced there may
  be labeled **Physical Tomato** only when an active bridge reports a completed
  hardware job.
- **Virtual Tomato** means the browser ISA-level emulator. It consumes the
  generated OS image and burned control tables but is not cycle-accurate RTL,
  an FPGA, or the discrete ALU hardware.
- **RTL simulation** means the local Icarus-driven machine used by
  `tools/virtual_tomato.py` and the FPGA testbenches. Label its results as
  simulation, never physical execution.
- **Envelop** is a separate messaging project. Its Tomato-side client and
  bounded compute executor are assembly linked into Tomato OS; its web/native
  clients, backend, and nearby bridge live in the Envelop repository.

## Current canonical facts

| Topic | Adopted fact | Repository authority |
|---|---|---|
| Word size | Tomato is a 32-bit architecture. | `hardware/digital/`, `hardware/fpga/core/rtl/`, `docs/isa/tomato.v1.csv` |
| Physical scope | A discrete ALU slice has been built; the complete running computer is the FPGA implementation. | `hardware/kicad/`, `web/assets/pcb/`, `hardware/fpga/core/` |
| Dual-LUT ALU | The custom ALU takes three 32-bit sources; two independently programmed LUT3 functions feed an adder as `f(a,b,c) + g(a,b,c) + carry`. | `hardware/fpga/core/rtl/alu.v`, `hardware/digital/`, `hardware/kicad/boards/07_alu/` |
| ISA count | **91 instructions plus NOP, 92 burned rows** in a 512-row control ROM. Pseudos do not add burned rows. | `docs/isa/tomato.v1.csv`; consistency check: `tools/gen_microcode_v1.py --check` |
| Register array | Discrete architecture (primary count): **32,768 × 32-bit** locations — discrete is the superior design constraint. FPGA implementation remains **256 × 32-bit** entries, addressed as `{bank[2:0], register[4:0]}`, with `r0` hardwired to zero, because there is no space for a larger file. The current burned ISA addresses that 256-entry FPGA array; it does not yet establish access to the 32,768-entry discrete superbank. | `hardware/fpga/core/rtl/regs.v`, `hardware/fpga/core/rtl/ir.v`, `docs/isa/tomato.v1.csv` |
| Tomato OS | The assembled source identifies **TOMATO OS v3.0** and contains **14 menu entries**. `Desktop v1.2` is the workspace UI revision, not the OS version. | `software/os/tomato_os.s` (`s_title`, `s_sp_tag`, `menu_items`, `n_menu`) |
| Envelop in Tomato OS | Envelop is one of those 14 entries. Its firmware and bounded remote executor are linked into the OS image. The shipped setup records are simulator-only placeholders; Nordic-generated ACI bytes are not redistributed, so physical radio use requires a locally supplied setup image. | `software/os/envelop_lite.s`, `envelop_setup.s`, `remote_exec.s`, FPGA core `Makefile` |
| Browser execution | The public browser implementation is a functional ISA-level emulator, not cycle-accurate RTL. Its checked-in image is derived from OS assembly and control data. | `web/js/tomato-cpu.js`, `tools/build_web_image.py`, `web/data/tomato-os.*` |
| Hardware compiler scope | The counter FSM enumerates all **65,536** `{lutB,lutA}` pairs for fixed A, B, C, carry, and expected-output values, stopping at the first match. A hit verifies only that fixed example; it does not prove a full truth table or general function. | `hardware/fpga/core/rtl/compiler_fsm.v` |
| Recorded ALU run | The verification record reports a completed **130-billion-vector** 32-bit ALU run against a reference model. The harness and reproduction command are checked in; the full run log/artifact is not. | `verification/gauntlet/README.md`, `verification/gauntlet/` |
| FPGA clocks | The Nexys A7's **100 MHz board oscillator** is the input clock. The default RTL divides it by 16 for a **6.25 MHz CPU clock** and by 4 for a **25 MHz pixel clock**. With 800×525 scan totals, that pixel clock produces **~59.52 Hz** refresh (640×480 nominal-60-Hz timing). These are different clock domains/metrics, not alternate CPU speeds. | `hardware/fpga/core/constr/nexys.xdc`, `hardware/fpga/core/rtl/board/nexys_top.v`, `videoout.v` |
| 90 MHz wording | **90 MHz is the configured nextpnr place-and-route timing target** (`--freq`), not an oscillator value, CPU runtime frequency, measured Fmax, or instruction rate. | `hardware/fpga/core/Makefile` (`FREQ_MHZ := 90`), `hardware/fpga/common.mk` |
| FPGA throughput | At 6.25 MHz, instruction throughput depends on CPI. The checked-in Icarus samples range from 2.000 to 2.556 CPI; converting their unweighted ~2.13-CPI summary gives a **workload-derived projection of ~2.9 million instructions/s**, not measured board throughput or a universal operations/s rating. | `hardware/fpga/core/reports/CPI.md`, `hardware/fpga/core/reports/METRICS.md` |
| Browser speed | Virtual Tomato is host-budgeted functional execution. Its `CPU_HZ = 6,250,000` value drives the guest timer model, while the UI loop runs as many ISA steps as an 8 ms/60,000-step frame budget permits. It must not be described as a 6.25 MHz or cycle-accurate emulator. | `web/js/tomato-cpu.js`, `web/js/virtual.js` |
| FPGA build flow | The default documented build is Yosys → nextpnr-xilinx → Project X-Ray; an optional Linux Vivado batch target exists for the same board. Neither target alone proves a currently programmed board. | `hardware/fpga/core/Makefile`, `hardware/fpga/common.mk` |

## Envelop execution boundary

Use this path when explaining the integrated system:

`person → Envelop web app → Envelop backend queue → nearby verified bridge → Envelop in Tomato OS → Tomato CPU → labeled reply`

- Human-to-Tomato text remains queued until Tomato accepts it and the active
  bridge records the acknowledgement. That acknowledgement is not a human read
  receipt.
- Hardware compute is a durable backend job. A timeout is an unknown outcome;
  it must not trigger an automatic virtual replay.
- Virtual Tomato preview is explicit and labeled. It runs separately in the
  browser, is not sent to the FPGA, and is never queued for later hardware
  execution.
- “Online” for hardware means the backend observes an unexpired authenticated
  bridge lease after the bridge verifies Tomato's exact `ENVELOP/1` identity.
  It does not mean that source code merely contains bridge support.

## Status boundaries

- **Source-complete:** FPGA Tomato, Tomato OS, its 14-entry menu, Envelop
  firmware, the browser emulator, and local RTL simulation are present in this
  repository.
- **Testable without hardware:** ISA consistency, assembly/layout, FPGA
  simulation, OS boot, browser-emulator regression, and the local remote
  executor have repository tests.
- **Hardware-dependent:** a currently programmed FPGA, attached radio, active
  nearby bridge, and completed physical reply require live evidence. Do not
  infer them from source, a screenshot, or a build recipe.
- **Envelop availability:** the Tomato-side client and executor are checked in
  here; web/native clients, backend, and bridge software are in the separate
  Envelop project. Neither repository proves that a nearby authenticated bridge
  is currently active.
- **Deployment-dependent:** public site content and Envelop's hosted backend
  may differ from a working tree. Verify the deployed artifact before using
  “live now,” “online,” or equivalent wording.

## Known documentation drift

The primary architectural register count is **32,768**, because discrete is
the superior design constraint. Discrete uses a 32,768-entry file (external
SRAM plus a seven-bit superbank / `SETBANK2`). FPGA implementation remains
**256 × 32-bit**, addressed by three bank bits and a five-bit register field,
because there is no space for more on that fabric. Neither the superbank latch
nor `SETBANK2` is present in current FPGA RTL or the burned ISA; those belong
to the discrete architecture, not the FPGA stand-in.

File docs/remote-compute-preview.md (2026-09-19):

# Remote compute — OS/preview ABI v1

This is a simulation-only integration checkpoint. No bitstream was generated
or programmed. The Mac app and production Supabase bridge are unchanged by
this iteration. Results are emitted by actual Tomato RTL executing OS assembly;
the Python compiler does not compute answers. The preview labels results as
RTL simulation, never as physical FPGA execution.

## Run and test

`python3 tools/virtual_tomato.py` serves http://127.0.0.1:8766/.
Open Envelop with Up, Center; click Connect demo phone. A live Hi, Hey, or
Hello receives this personalized, ACK-gated firmware sequence:

1. `Hello, {firstname}! I'm Tomato.`
2. `I reply from a dorm table I call home.`
3. `Tyrone Marhguy built me transistor-up!`
4. `Try 23 + 19 on my dual-LUT ALU!`

Names are bounded so the complete introduction stays within Tomato's
40-character display record. Enter commands in the multiline simulated-phone
field. The transcript records actual outgoing firmware replies and separately
labels compiler errors.

`make -C hardware/fpga/core remote-test` runs native compute cases, randomized
ALU checks, malformed binary jobs, firmware transport and sandbox tests, plus
launcher/game/chat regression. No FPGA tools are invoked.

## Grammar currently implemented

- `/calc 23 + 19`: `+ - & | ^`, decimal, hexadecimal, binary literals.
- `/run` followed by newline- or semicolon-separated instructions.
- `R0 = 42` through `R7`; values -2147483648..4294967295, modulo-32-bit results.
- `ADD SUB AND OR XOR dst,a,b`.
- `MASKADD XORAND dst,a,b,c` use the real compound ISA instructions.
- `STORE [0..255],R0` and `LOAD R0,[0..255]`.
- Exactly one `RETURN R0`, last; maximum 32 instructions, 2048 source characters.
- `/help` and Hi/Hey/Hello are handled by OS firmware. Other ordinary text gets
  a bounded fallback. Only one ordinary outgoing chat message is in flight;
  greeting and help sequences advance only after ACKs using the existing retry
  path. Duplicate/history messages remain silent. Requests arriving while a
  chat reply is pending may not get another automatic chat reply.

Example:

```
/run
R0 = 0x20
R1 = 15
R2 = 3
MASKADD R3,R0,R1,R2
STORE [0],R3
LOAD R4,[0]
ADD R5,R4,R2
RETURN R5
```

Expected result: 38 / 0x00000026.

## Wire format for other implementers

Existing PG framing and CRC remain unchanged. New frame type **32** is a job,
using an existing nonzero contact route. Payload is tokenBE32, version byte 1,
then records below. Maximum payload 197 bytes. The firmware independently
checks the whole program before clearing or changing sandbox registers/memory.
It then walks the same records sequentially. No host machine code is accepted.

| Bytecode | Record bytes |
|---|---|
| 1 SET | op, dst, immediateBE32 (6 total) |
| 2..6 ADD/SUB/AND/OR/XOR | op,dst,a,b,c (5); binary ops ignore c but validate it |
| 7..11 MASKADD/XORAND/ANDADD/ORADD/XORADD | op,dst,a,b,c (5) |
| 12..13 ANDN/ORN | op,dst,a,b,c (5); c pad 0 |
| 14..31 Dual-LUT nests (XORBC…NORXOR) | op,dst,a,b,c (5); `~(A⊗(B⊕C))` forms |
| 32 LOAD | op,dst,offset8 (3) |
| 33 STORE | op,src,offset8 (3) |
| 34..45 Dual-LUT nests (NORNAND…XORXNOR) | op,dst,a,b,c (5); 32/33 reserved for memory |
| 48 RETURN | op,src (2); must end payload |

Nested Boolean forms such as `nand(34, 235, 2355)` fuse to one Dual-LUT opcode
(e.g. **23 NANDAND** = `~(A & (B & C))`) matching Envelop’s website compiler.

Reply frame type **33**, same route: tokenBE32,status8,resultBE32 (9 bytes).
Status 0 is success. Errors: 1 INVALID_OPCODE, 2 PROGRAM_TOO_LONG,
3 REGISTER_RANGE, 4 MEMORY_RANGE, 5 MISSING_RETURN, 6 UNSUPPORTED_RAW_LUT,
7 MALFORMED_PROGRAM. Result is zero on error. A job without a complete token
is dropped. Unknown/unverified routes are ignored. Error text and hexadecimal
results are projected into the actual OS chat framebuffer.

This checkpoint sends one result frame, without durable result retry/cache,
accepted/running frames or production job-state updates. A repeated job is
deterministically re-executed from cleared state. Before production integration,
add token-correlated result ACK/retry and a bounded result cache. Preserve a
pending normal-chat TX projection until its ACK; compute still returns its
binary result while that chat is pending.

## Reserved RAM and ABI

| Region | Purpose |
|---|---|
| 0x1500 onward, below 0x1600 | Chat help/fallback code |
| 0x1600..0x17ff | Greeting/help/error strings and sequence lookup tables |
| 0x1d00 onward, below 0x2000 | Executor code |
| 0x26a0..0x26bf | Executor state, result packet and saved OS r10 |
| 0x26c0 onward | Result label |
| 0x26e0..0x26e7 | Eight virtual registers |
| 0x2700..0x27ff | 256 private 32-bit words |

Strict assembly checks emitted code AND `.space` allocations for overlap and
16K-word overflow. Existing desktop strings occupy 0x3000 onward: that region
is not free. Execution preserves the OS framebuffer base, keyboard/timer base,
text-width register, parser/service return links, menu register and BLE bases.
Host-visible R0 is virtual storage; it is not physical zero register r0.

## Explicit next steps

1. Implement/freeze LUTCFG/LUTEXEC ISA, assembler, RTL and randomized equivalence
   tests. Current compiler and executor reject raw operations explicitly.
2. Define virtual flags independently of interpreter CMP/loop housekeeping;
   otherwise H=Z/C/etc would read the interpreter's flags rather than job flags.
   Native arithmetic is working; remote flag-derived H semantics are not claimed.
3. Add raw bytecode execution only after those interfaces are verified.
4. Integrate a shared strict compiler, durable FIFO job model, rate limits,
   result ACK/retry, and contact/job sync into the production backend and bridge.
5. Add job/result UI to native clients; preserve chat compatibility. Full register
   trace, offline queued jobs, real BLE compute and raw ALU tests remain pending.
6. Only then request hardware deployment; current user instruction forbids it.

## Envelop local integration (2026-09-15)

Start `python3 tools/virtual_tomato.py`. Envelop/apple’s packaged app offers
**Use Tomato** in the device conversation (and **Try Tomato locally** before
profile restoration). It calls `/interpret` for original/canonical/bytecode,
tries its current eligible BLE route, then offers explicit virtual fallback.
`/execute` starts an isolated CPU RTL instance with the same OS and compiler.
This is a local development service, bound to loopback with host validation and
per-process request token; it is not a public authenticated cloud executor.

`python3 tools/test_remote_service.py` tests the running service. Natural example:
`What is (57 + 19) AND 0x3F?` → native ADD then AND → `12 / 0x0000000C`.
See the root sprint in both repositories for the remaining lifecycle and cloud
work. Current physical firmware was deliberately not upgraded in this sprint.

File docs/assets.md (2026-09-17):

# Tomato documentation assets

Tomato images are evidence, not decoration. Use an image only when it clarifies
what was built, where code ran, or how a subsystem fits together.

The current reusable documentation collection lives under
[`web/assets/`](../web/assets/). This guide describes how repository
documentation should select and label those files; it does not make the asset
directory an architectural authority.

## Recommended evidence set

| Subject | Reusable asset | What it supports |
|---|---|---|
| Assembled ALU slice | `web/assets/assembly/half-soldered-plate.webp` | Physical assembly of the Dual-LUT ALU slice |
| FPGA setup | `web/assets/assembly/fpga-board-pmod.webp` | Nexys A7 hardware used by FPGA Tomato |
| Tomato OS | `web/assets/os/desktop-home.webp` | OS desktop shown on the FPGA display path |
| ALU board render | `web/assets/pcb/alu_8b_board.webp` | Lot 07 PCB design |
| ALU routed board | `web/assets/pcb/alu_8b_pcb.jpg` | Board layout, not assembled hardware |
| Digital schematic | `web/assets/story/digital/main-tomato-v1-burn.webp` | Editable architecture schematic view |
| Envelop browser conversation | `web/assets/envelop/envelop-demo.mp4` + `envelop-demo-poster.webp` | Browser UI recording of a hello and Tomato’s multi-message reply; not physical-hardware evidence |
| Envelop in current OS image | `web/assets/documentation/desktop/tomato-virtual-os-envelop-desktop.webp` | Browser-emulated OS UI with simulated peripherals; not FPGA or online bridge evidence |
| Envelop FPGA frameport | `web/assets/gallery/os/envelop-as-seen-on-fpga-frameport.png` | FPGA display-path capture; reported bridge state applies only to the captured frame |
| Envelop FPGA compute result | `web/assets/gallery/os/tomato-envelop-from-fpga-frameport.webp` | Optimized FramePort capture of a bounded result; not current bridge-availability evidence |
| Compiler in current OS image | `web/assets/documentation/desktop/tomato-virtual-os-compiler-desktop.webp` | Browser-emulated current compiler screen |
| Real-phone responsive pages | `web/assets/documentation/infinix/*.webp` | Current local site rendered on the documented Infinix; UI-only evidence |

Prefer these established images over adding near-duplicates. Dimensions,
capture method, privacy review, and per-file captions for the 2026-09-16
website set are recorded in the
[`web/assets/documentation` catalog](../web/assets/documentation/README.md).
Those captures prove the interface state shown, not deployment or physical
availability.

## Caption and alt-text rules

Every image should answer three questions where relevant:

1. **What is shown?** Name the board, screen, schematic, or result.
2. **Where did it run?** Distinguish discrete hardware, FPGA Tomato, Virtual
   Tomato, and RTL simulation.
3. **What does it prove?** Do not infer a complete system from a component.

Good alt text is concrete: “Physically assembled Tomato Dual-LUT ALU slice.”
Avoid claims such as “the discrete Tomato computer” because only the ALU slice
has been physically assembled. For emulator and simulation output, include that
provenance in the alt text or adjacent caption.

## Status boundaries

- A PCB render proves a design exists, not that it was fabricated or assembled.
- An assembly photograph can prove the pictured component exists, not that a
  complete computer ran.
- An FPGA photograph identifies hardware, but a result requires an associated
  run record or visibly grounded capture.
- A screenshot proves the captured interface state, not current deployment.
- Virtual and simulation results must remain labeled when copied or cropped.
- Generated images and memory artifacts must name their source or generator.

## Privacy and sanitization

Before publishing a capture, remove or avoid:

- personal notifications and account identifiers;
- credentials, tokens, private endpoints, and administrative controls;
- device identifiers and nearby-device details;
- keyboard suggestions or unrelated app content;
- real names and messages when synthetic fixtures can demonstrate the state.

Strip unnecessary metadata from published derivatives. Keep any original
capture notes outside public narrative surfaces when they contain operational
detail.

## File practices

- Prefer WebP for photographic and UI documentation images; preserve a source
  format only when it materially improves reuse.
- Use stable, descriptive lowercase names.
- Keep dimensions large enough for readable text but avoid shipping an
  oversized source when a smaller derivative is sufficient.
- Do not edit generated diagrams or screenshots to imply a different execution
  target.
- Record third-party or generated-image attribution in the repository's
  designated attribution/legal files rather than duplicating uncertain claims.

Current terminology and execution-label rules come from
[`status.md`](status.md) and [`compute.md`](compute.md).

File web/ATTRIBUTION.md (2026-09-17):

# Image attribution

Unless a row says otherwise, photographs, screen captures, diagrams, renders,
videos, and drawn ornaments are original Tomato / Tyrone Marhguy work.
Tool-generated images name the editable source or generating tool; generation
does not imply that Digital, KiCad, or another tool endorses Tomato. The single
third-party historical photograph is identified with its public-domain source.

| File | Source |
|---|---|
| `assets/pcb/alu_8b_board.jpg` | KiCad render, board `07_alu` |
| `assets/pcb/immersion_black.mp4` | KiCad 3D orbit of `07_alu` — dark immersion, H.264 from the black GIF |
| `assets/pcb/immersion_black.webp` | Poster still for the dark-stock orbit |
| `assets/pcb/hero.mp4` | Tomato-authored 07_alu KiCad render tour, encoded as H.264 |
| `assets/pcb/hero.webp` | Poster still for the front-page tour |
| `assets/compiler/opcode-sweep-sim.mp4` | Opcode-space sweep in simulation — H.264 from `opcode_sweep_sim.mp4` |
| `assets/compiler/opcode-sweep-fpga.mp4` | Same FSM on Artix‑7 — H.264 from `fpga_opcode_sweep.mp4` |
| `assets/compiler/fpga-terminal-program.mp4` | Open-source FPGA build — Yosys → nextpnr → bitstream (`media/compiler/fpga_terminal_program.mp4`) |
| `assets/compiler/fpga-terminal-program.webp` | Poster still for the terminal build clip |
| `assets/gallery/compiler/fpga-terminal-program-{128,640,1280}w.webp` | Responsive gallery posters for the same terminal clip (`gallery.html` · Beyond Vivado) |
| `assets/compiler/opcode-sweep-sim.webp` | Poster still for the simulation sweep |
| `assets/assembly/digikey-box.webp` | DigiKey parts box, 17 Aug 2026 — cropped to the branded face |
| `assets/assembly/work-setup.mp4` | Soldering lights on the loop, interleaved with board-test stills (3s / 2s) |
| `assets/assembly/work-setup.webp` | Poster — board-test cover of the interleaved clip |
| `assets/assembly/board-test.webp` | On-board test still — 07_alu on the mat |
| `assets/assembly/half-soldered.webp` | Half-soldered 07_alu held next to Digital |
| `assets/assembly/half-soldered-plate.webp` | Square plate of the half-soldered shot |
| `assets/og/tomato-board.webp` | KiCad 07_alu isometric — 1200×630 Open Graph card (`media/pcb/board_iso.png`) |
| `assets/pcb/board-iso.webp` | Full-aspect 07_alu isometric still |
| `assets/assembly/placing-and-soldering.mp4` | Placing 74ACT logic on 07_alu |
| `assets/assembly/placing-and-soldering.webp` | Poster still for the placement clip |
| `assets/assembly/soldering-led.mp4` | Soldering 0805 indicator LEDs |
| `assets/assembly/soldering-led.webp` | Poster still for the LED clip |
| `assets/pcb/immersion_white.webp` | KiCad 3D orbit of `07_alu` (still / poster) |
| `assets/pcb/alu_8b_pcb.jpg` | Routed top copper, `07_alu` |
| `assets/plates/digital-main.jpg` | Digital `main.dig`, 27 Jun 2026 |
| `assets/plates/alu-4b.jpg` | Digital `alu-4b-final` |
| `assets/plates/kicad-sch.jpg` | KiCad schematic sheet, `07_alu` |
| `assets/plates/microcode.jpg` | Digital modular-decode schematic |
| `assets/mark.svg` | Printer’s mark drawn for this site (tomato over a 74xx DIP) |
| `assets/slice.svg` | Nibble diagram drawn for this site |
| `assets/plates/gallery-slideshow.jpg` | Gallery as a simple slideshow — the cut that kept the paper one site |
| `assets/assembly/hdmi-test.mp4` | First pixels — 12-bit PMOD HDMI test pattern on Nexys A7 |
| `assets/assembly/hdmi-test.webp` | Poster still for the HDMI test clip |
| `assets/assembly/fpga-board-pmod.webp` | Nexys A7 with iCEBreaker 12-bit DVI PMOD on JC/JD, HDMI connected |
| `assets/assembly/layout-tomato-alu-8bit.png` | KiCad PCB editor — routed 07_alu top layer |
| `assets/assembly/early-ratsnest-nine-ics.png` | Early placement — nine ICs, ratsnest before route |
| `assets/assembly/3d-green-cells-july.png` | KiCad 3D render — green mask, July |
| `assets/assembly/3d-olive-penn-branding.png` | KiCad 3D render — olive mask with Penn silk |
| `assets/assembly/alu_back.png` | B.Cu — ground pours and vias on 07_alu |
| `assets/pcb/drc.webp` | KiCad DRC report — 0 errors before fab |
| `assets/pcb/status-bar.webp` | KiCad status bar — 185 nets, zero unrouted |
| `assets/plates/alu-4b-final.webp` | Digital `alu-4b-final` nibble cell |
| `assets/story/digital/main-tomato-v1-burn.webp` | Digital `main.dig` — tomato-v1-burn top sheet |
| `assets/plates/microcode-modular.webp` | Digital modular microcode decode sheet |
| `assets/plates/front-page.webp` | Front page plate — Vol. 32 No. 1 |
| `assets/story/display/segment-control.webp` | Digital seven-segment control sheet |
| `assets/story/open-source/librelane-3.0.8.webp` | LibreLane release — open ASIC toolchain |
| `assets/story/open-source/openroad-activity.webp` | OpenROAD / FOSS P&amp;R research |
| `assets/plates/mouser-pmod-1.jpg` | Mouser order — Digilent PMOD VGA in transit |
| `assets/plates/mouser-pmod-2.jpg` | Mouser checkout summary for the same PMOD order |
| `assets/engravings/eniac-penn.jpg` | ENIAC at the Moore School, 1946. Public-domain U.S. Army photograph, via [Wikimedia Commons](https://commons.wikimedia.org/wiki/File:Classic_shot_of_the_ENIAC.jpg) |

Digital is GPL-3.0-licensed authoring software by Helmut Neemann; KiCad is
GPL-3.0-licensed authoring software. The Tomato-authored `.dig`/KiCad designs
and their renders are project outputs, not copies of those applications. See
[`THIRD_PARTY_NOTICES.md`](../THIRD_PARTY_NOTICES.md) for the legal boundary.

No synthetic generative-image source is currently identified in this published
asset catalog. If one is added, record the generator, date, prompt/source
record location, edits, and redistribution basis here before publication.

Original Tomato assets are distributed under the repository's stated
`Apache-2.0 WITH SHL-2.1` terms. Third-party material remains under the terms
named for that item.

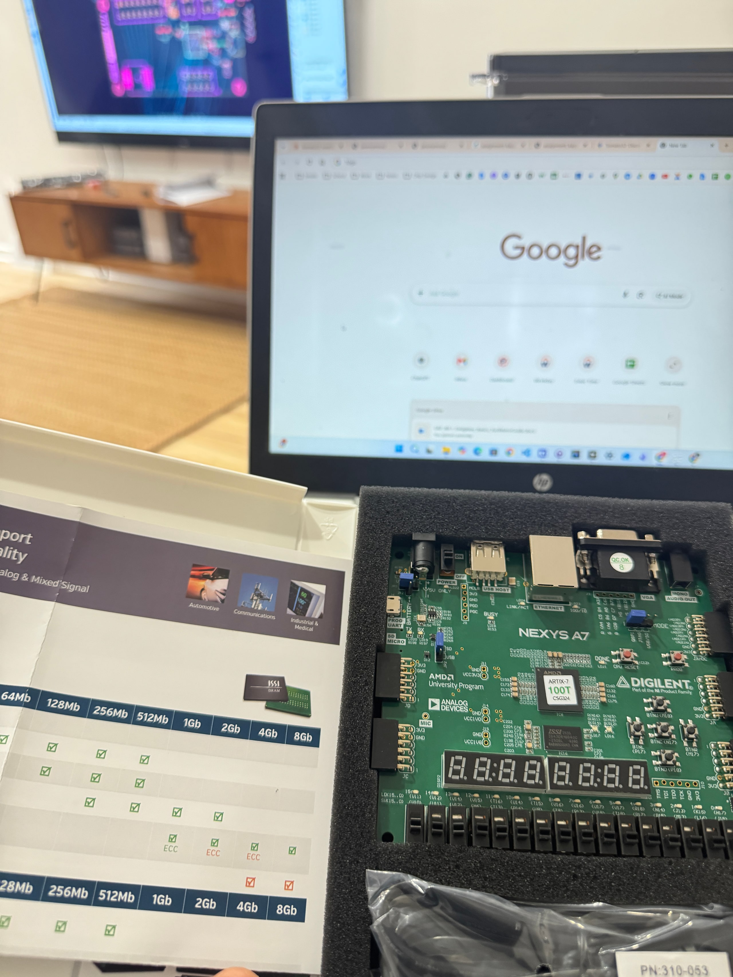
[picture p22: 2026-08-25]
web/assets/story/hardware/nexys-a7.jpg

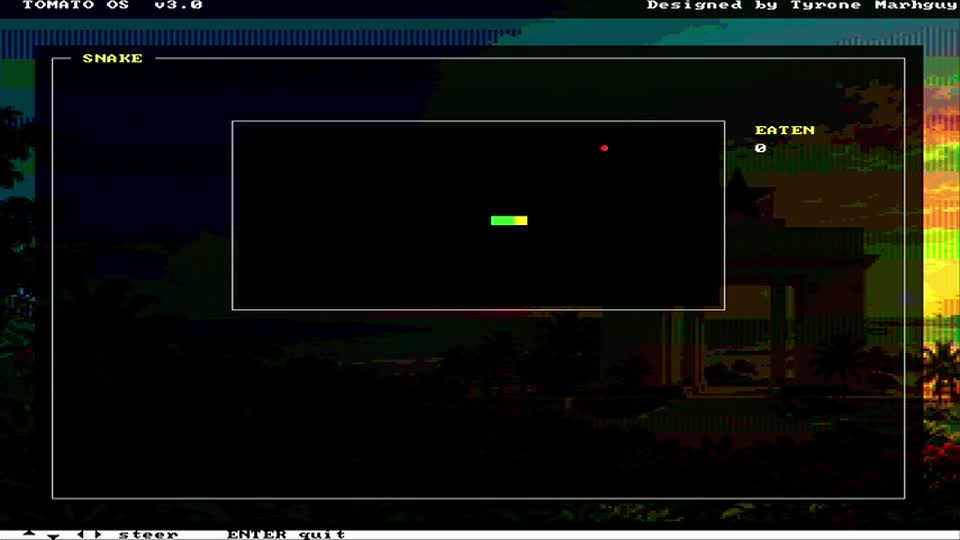
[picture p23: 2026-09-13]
web/assets/os/tomato-demo-os-poster.jpg

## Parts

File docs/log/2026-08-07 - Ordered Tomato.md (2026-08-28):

# Ordered Tomato

**Date:** 2026-08-07 — PCBs · **2026-08-08** — parts  
**Status:** Ordered — waiting on fab + DigiKey  
**Board:** [`07_alu`](../../hardware/kicad/boards/07_alu/README.md) (dual-LUT 8b slice × **2** → 16b bring-up)  
**Related:** [Designing additional boards](2026-08-02%20-%20Designing%20Additional%20Boards.md) · [Falling back to 32b](2026-07-31%20-%20Falling%20back%20to%2032b.md)

---

## It is real

After months of schematic churn, opcode tables, and the occasional 40b detour, Tomato has left the screen.

**Yesterday:** bare boards on JLCPCB.  
**Tonight:** every IC, cap, LED, and SIP resistor network on DigiKey — enough for **two** `07_alu` slices.

The dual-LUT ALU is no longer a KiCad fantasy. Copper is being etched. Chips are in a warehouse in Minnesota. I am genuinely excited.

<p align="center">
  Tomato ALU — board render
  Tomato ALU — top copper
</p>

<p align="center"><em>Figure 1 — What we are actually building: <code>07_alu</code> — board render (left), routed top copper (right). DRC clean, 0 unrouted nets.</em></p>

---

## Fabrication — boards

I finally stopped polishing and hit submit. The existential “one more routing pass” voice is quiet for now — and honestly, it was not buying much anymore.

- **Board:** `07_alu` — 8-bit dual-LUT ALU slice  
- **Cost:** under **$6** for the PCB order (easy to reorder if something goes wrong)  
- **ETA:** ~two weeks to Philadelphia  

If there is a fab error, I can spin another batch without heartbreak. That was the whole point of keeping the board small and the order cheap.

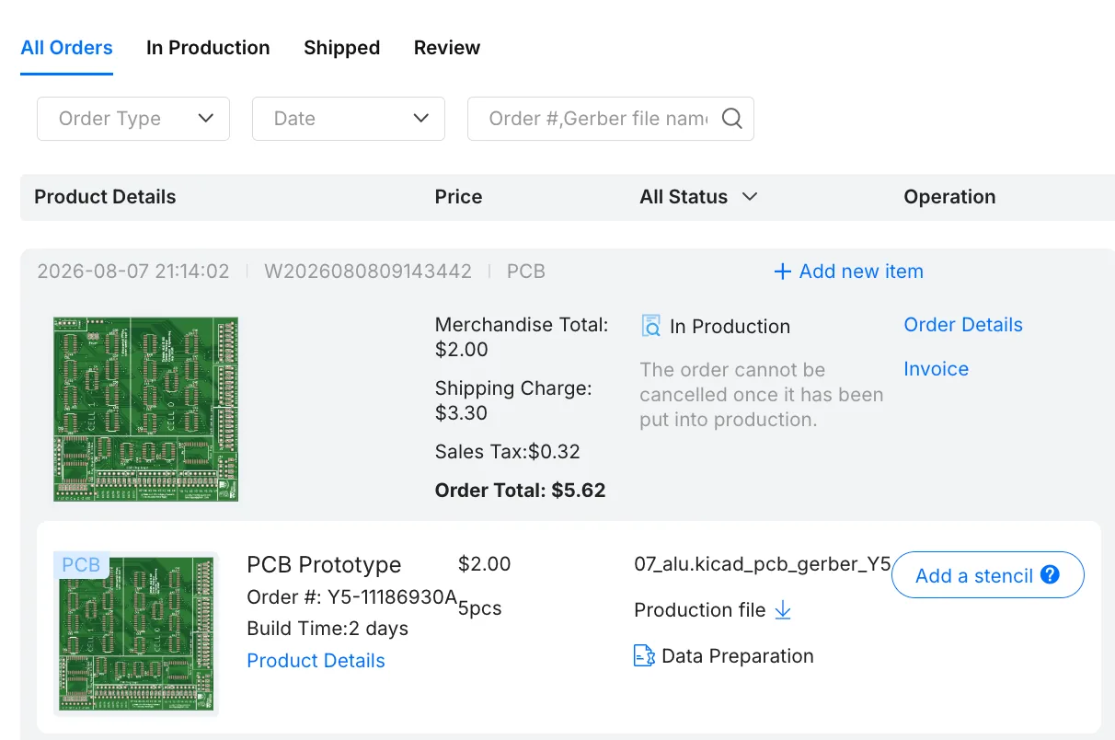
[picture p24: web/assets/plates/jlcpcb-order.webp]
JLCPCB order confirmation

*Figure 2 — JLCPCB order — copper incoming.*

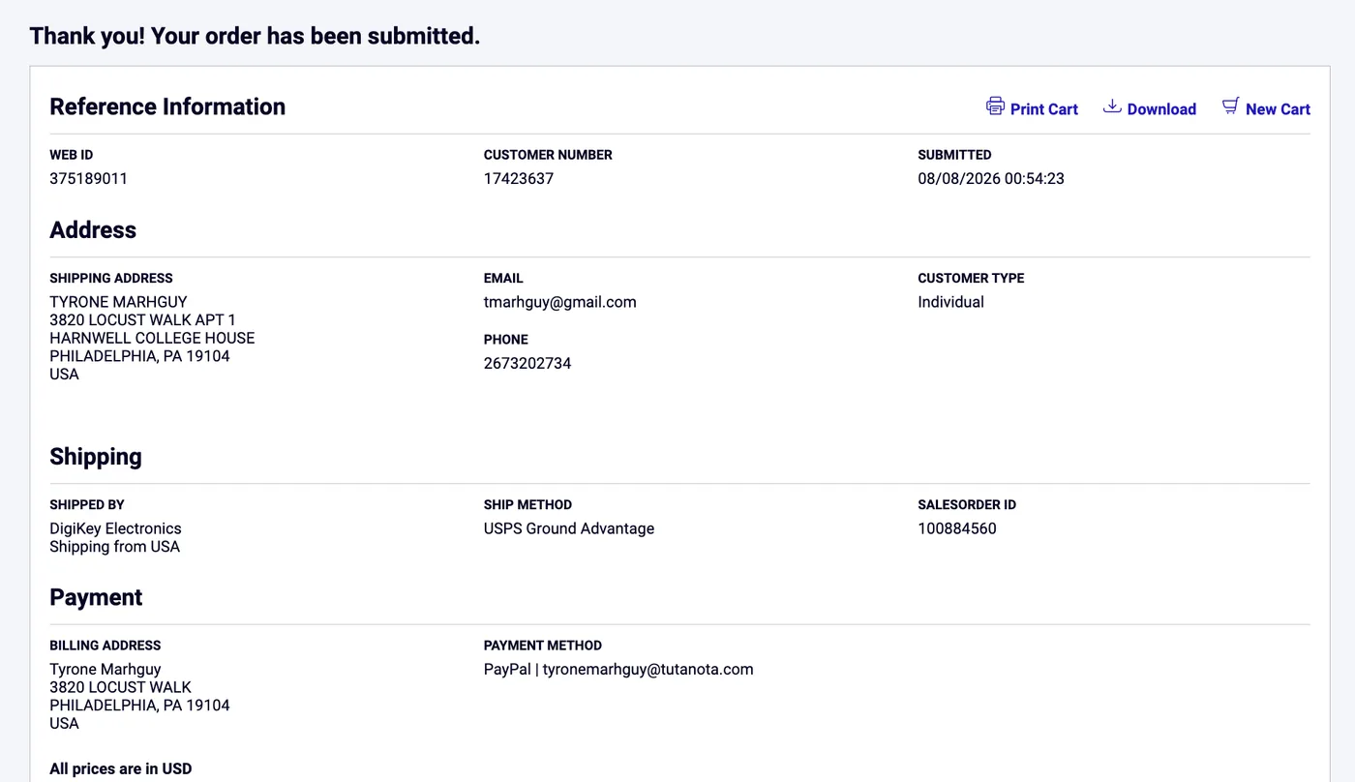
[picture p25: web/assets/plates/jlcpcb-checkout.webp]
JLCPCB checkout

*Figure 3 — JLC order details.*

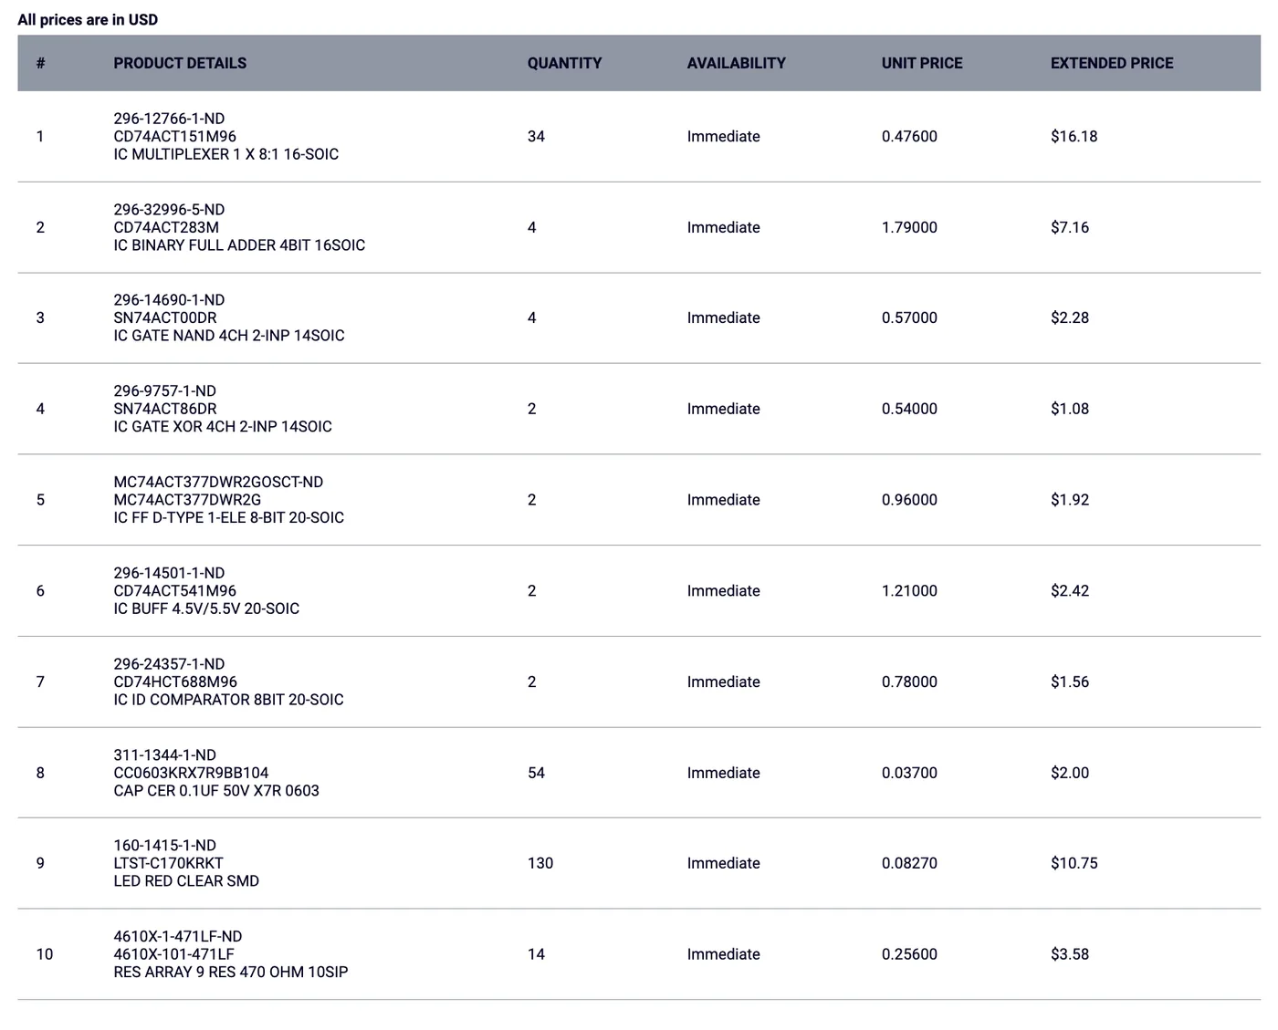
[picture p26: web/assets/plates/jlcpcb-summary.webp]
JLCPCB summary

*Figure 4 — JLC summary.*

---

## DigiKey — parts (order `100884560`)

Same night, different kind of commitment: **34× 74ACT151** muxes do not lie. This is a real machine, not a simulation.

I sized the cart for **two boards** — a full **16-bit** datapath from day one. One board proves the slice; two boards is the actual Tomato width on the bench. The marginal cost of the second slice (~$20 in parts on top of ~$40 for one) was too good to skip.

| Line | Part | Qty | Role |
|---|---|-----|---|
| 1 | CD74ACT151M96 | **34** | 8:1 LUT muxes — the heart of the dual-LUT plane |
| 2 | CD74ACT283M | **4** | 4-bit ripple adders |
| 3 | SN74ACT00DR | **4** | Quad NAND (glue) |
| 4 | SN74ACT86DR | **2** | Quad XOR |
| 5 | MC74ACT377DWR2G | **2** | Octal D-FF / flag latch |
| 6 | CD74ACT541M96 | **2** | Octal bus buffer |
| 7 | CD74HCT688M96 | **2** | 8-bit identity comparator (zero detect) |
| 8 | CC0603 100nF | **54** | Decoupling (50 + spares) |
| 9 | LTST-C170KRKT red LED | **130** | Debug wall (126 + spares) |
| 10 | 4610X-101-471LF SIP-9 | **14** | Bussed 470Ω LED limiters |

- **Subtotal:** $48.93  
- **Total (ship + tariff + tax):** **~$61**  
- **Availability:** all lines **immediate** — no backorders  
- **BOM on disk:** [`07_alu_digikey_bom.csv`](../../hardware/kicad/boards/07_alu/07_alu_digikey_bom.csv)  
- **Order export:** [`100884560.csv`](../../hardware/kicad/fabrication/07_alu/07_alu_digikey_bom.csv) (fabrication copy)

Swapped the backordered Samsung 100nF caps for Yageo `311-1344-1-ND`. Picked `CD74HCT688M96` over SN74HC688 for cleaner 5V ACT interfacing. Same footprint, better margins.

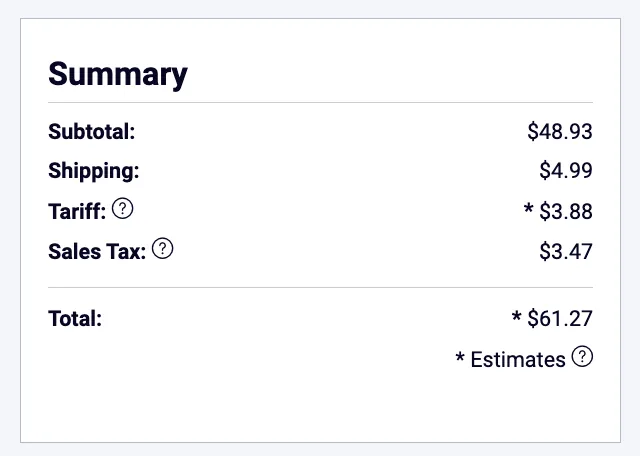
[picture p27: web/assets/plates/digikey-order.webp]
DigiKey order confirmation

*Figure 5 — DigiKey order `100884560` — 10 line items, two boards worth of silicon.*

---

## Still to source

DigiKey does not have the SIP-4 networks without a 2,000-piece reel trap, and I already have headers in the lab:

| Item | Qty (2 boards) | Refs |
|---|---|---|
| SIP-4 bussed 470Ω (`4604X-101-471LF` or equiv.) | **4** | RN9, RN10 |
| 4-pin headers | **4** | J10, J11 |
| 8-pin headers | **14** | J5–J7, J12, J15–J17 |

Fallback for RN9/RN10: discrete 470Ω resistors, common on one side.

---

## What happens next

1. **Wait** — JLC boards (~2 weeks), DigiKey box (days).  
2. **Grab** SIP-4 + headers before the soldering marathon.  
3. **Assemble** board #1 — 131 placements, 63 LEDs, the whole debug wall.  
4. **Bring up** 8-bit — opcode walk, carry chain, flag latch, LED sanity.  
5. **Assemble** board #2 — cascade to **16-bit**, wire slice-to-slice, and finally *see* the dual-LUT datapath breathe.

If something is wrong, I will know because 130 red LEDs do not lie.

This is the best part of the project — the part where the schematic meets flux and patience. Tomato is ordered. Now we build.

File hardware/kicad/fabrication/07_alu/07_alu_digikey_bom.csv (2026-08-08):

# | QUANTITY | PART NUMBER | MANUFACTURER PART NUMBER | DESCRIPTION | UNIT OF MEASURE | CUSTOMER REFERENCE | AVAILABILITY | UNIT PRICE
1 | 34 | 296-12766-1-ND | CD74ACT151M96 | IC MULTIPLEXER 1 X 8:1 16-SOIC |  |  | Immediate | 0.47600
2 | 4 | 296-32996-5-ND | CD74ACT283M | IC BINARY FULL ADDER 4BIT 16SOIC |  |  | Immediate | 1.79000
3 | 4 | 296-14690-1-ND | SN74ACT00DR | IC GATE NAND 4CH 2-INP 14SOIC |  |  | Immediate | 0.57000
4 | 2 | 296-9757-1-ND | SN74ACT86DR | IC GATE XOR 4CH 2-INP 14SOIC |  |  | Immediate | 0.54000
5 | 2 | MC74ACT377DWR2GOSCT-ND | MC74ACT377DWR2G | IC FF D-TYPE 1-ELE 8-BIT 20-SOIC |  |  | Immediate | 0.96000
6 | 2 | 296-14501-1-ND | CD74ACT541M96 | IC BUFF 4.5V/5.5V 20-SOIC |  |  | Immediate | 1.21000
7 | 2 | 296-24357-1-ND | CD74HCT688M96 | IC ID COMPARATOR 8BIT 20-SOIC |  |  | Immediate | 0.78000
8 | 54 | 311-1344-1-ND | CC0603KRX7R9BB104 | CAP CER 0.1UF 50V X7R 0603 |  |  | Immediate | 0.03700
9 | 130 | 160-1415-1-ND | LTST-C170KRKT | LED RED CLEAR SMD |  |  | Immediate | 0.08270
10 | 14 | 4610X-1-471LF-ND | 4610X-101-471LF | RES ARRAY 9 RES 470 OHM 10SIP |  |  | Immediate | 0.25600

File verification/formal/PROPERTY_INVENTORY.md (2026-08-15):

# Formal property inventory (ALU only)

Generated by `verification/scripts/inventory_formal.py`.
These properties cover the **ALU netlist**, not the full Tomato CPU / ISA / memory system.

## Jobs (5/5 documented PASS)

| Job | Mode |
|-----|---|
| `alu_1b_verify.sby` | prove |
| `alu_8b_verify.sby` | prove |
| `alu_32b_verify.sby` | prove |
| `alu_32b_equiv_verify.sby` | prove |
| `alu_32b_flags_verify.sby` | cover |

## Bind statement counts

| Bind file | Source assert | Source cover | Elaborated assert | Elaborated cover |
|---|---|---|---|---|
| `alu_1b_verify_bind.v` | 3 | 4 | 3 | 4 |
| `alu_8b_verify_bind.v` | 3 | 4 | 24 | 32 |
| `alu_32b_verify_bind.v` | 12 | 4 | 12 | 4 |
| `alu_32b_equiv_verify_bind.v` | 1 | 3 | 1 | 3 |
| `alu_32b_flags_verify_bind.v` | 0 | 5 | 0 | 5 |
| **Total** | **19** | **20** | **40** | **48** |

**Headline:** ALU formal suite = **5/5 jobs**, **19 assert + 20 cover** source (**40 + 48** after 8b generate).

```bash
make -C verification formal_inventory
make -C verification formal_full   # requires sby
```

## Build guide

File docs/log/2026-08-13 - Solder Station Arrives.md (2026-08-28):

The new solder station arrived on campus from Amazon and works perfectly. Now, I’m just waiting on the custom PCB and DigiKey components to arrive so I can get to work and resume building project "Tomato."

<p align="center">
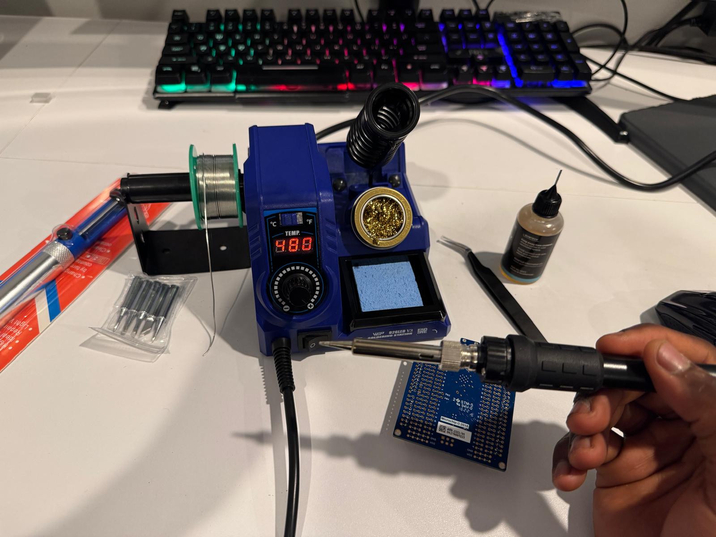
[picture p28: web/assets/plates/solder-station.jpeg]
WEP 926LED V3 on the desk — display at 480, iron over a small Microchip board.
  
</p>

> **Station in. Boards still inbound.** The iron works. Tomato waits on the custom PCB and DigiKey parts. Then: back to the build.

Having a proper iron is a hilarious contrast to my early engineering days. When I was 13, my family lived on a bus for two years while my dad was sick. We had no electricity, so sheer necessity drove me to rig up LEDs to old mobile phone batteries to give us light.

My "soldering iron" back then was just a nail heated red-hot in a fire. I’d hold it with pliers—or a makeshift wooden holder that frequently caught fire—to melt thick chunks of salvaged solder.

| Then | Now |
| ---- | --- |
| A nail, heated red-hot in a fire | WEP 926LED V3, **480 °C** on the display |
| Pliers — or a wooden holder that caught fire | Coil stand, brass wool, sponge |
| Salvaged chunks of solder | A spool on the station |
| Hand-crank a wind generator, stay under **5V**, charge to **4.1V** | Campus desk. Waiting on JLCPCB + DigiKey. |

To charge the batteries, I relied on a wind generator I had actually built myself _([See video of me rewinding my first wind generator at 11 years in Ghana](https://docs.google.com/videos/d/1zLeuVECxmtJ6nVa4QfNbt_4gfXpi5gCUJMtCwPADubI/play?usp=sharing))_.

Because it lacked working propellers at the time, I had to act as the wind. I would sit and hand-crank it with a piece of wood for hours every day, constantly watching a multimeter to ensure I generated just under **5V** to safely charge the batteries to **4.1V**.

It was quite the hustle, but we've come a long way. My family is healthy, and I'm currently pursuing computer engineering degree at an Ivy League. I loved that early ingenuity, but I'm thrilled to have real tools now. Back to the build!

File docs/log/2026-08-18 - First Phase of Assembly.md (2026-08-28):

# First Phase of Assembly

**Date:** 2026-08-18  
**Status:** Populating `07_alu` — muxes and adders down, lamps started  
**Board:** [`07_alu`](../../hardware/kicad/boards/07_alu/README.md)  
**Related:** [Ordered Tomato](2026-08-07%20-%20Ordered%20Tomato.md) · [PCBs Arrive!](2026-08-15%20-%20PCBs%20Arrive!.md) · [Solder station arrives](2026-08-13%20-%20Solder%20Station%20Arrives.md)

---

Today is perhaps one of the most important ones of this project. I got the parts from DigiKey. There was an initial delay, but they replaced the order when I called. After weeks of staring at digital schematics and KiCad renders, having physical silicon show up at the door is a huge milestone.

<p align="center">
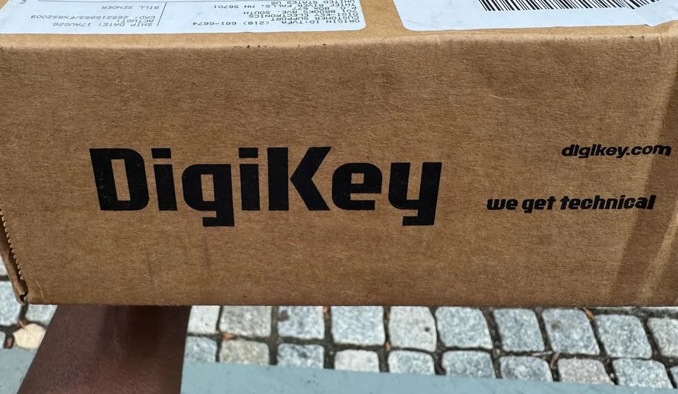
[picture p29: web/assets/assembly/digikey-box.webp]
DigiKey box — 74ACT parts for 07_alu.
  
</p>
<p align="center"><em>The box. DigiKey, 17 August 2026.</em></p>

With the components finally here, I cleared the desk, set up the flux and tweezers, and laid out the tools. The footprint on these SMD chips is a completely different object when you are holding them rather than placing them on a grid.

<p align="center">
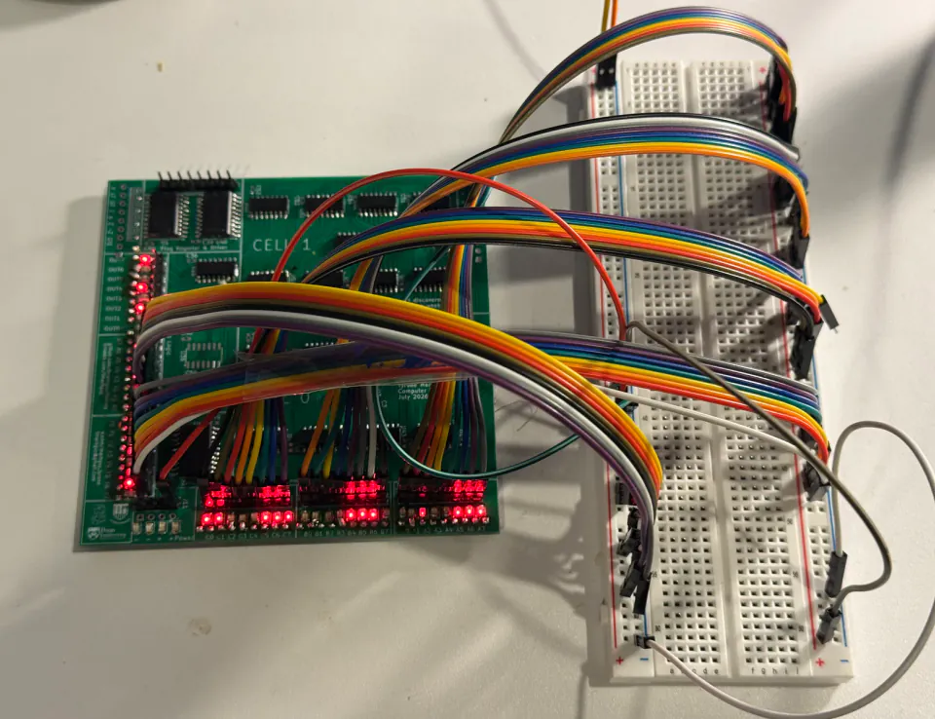
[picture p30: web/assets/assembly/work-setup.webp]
Soldering bench — iron, flux, tweezers, multimeter.
  
</p>
<p align="center"><em>The bench, ready.</em></p>

All parts have arrived. I have soldered every **74ACT151** on one of the boards, and each adder (**74ACT283**). The 74ACT series wants a steady hand. Laying down that much logic takes time and patience.

<p align="center">
  <video src="../../web/assets/assembly/placing-and-soldering.mp4" controls width="70%"></video>
</p>
<p align="center"><em>Placing and soldering the 74ACT logic onto 07_alu.</em></p>

The LEDs are tiny. I have soldered about seven of them. Aligning them without bridging the pads is a test of endurance, but seeing those indicators sit on the copper makes it worth it.

<p align="center">
  <video src="../../web/assets/assembly/soldering-led.mp4" controls width="70%"></video>
</p>
<p align="center"><em>Soldering the 0805 indicator LEDs.</em></p>

It is exciting seeing these parts for the first time and each of them fitting. I put the half-soldered board next to the simulation on the monitor. Looking back and forth between the digital truth table and the physical gates on the mat is surreal.

<p align="center">
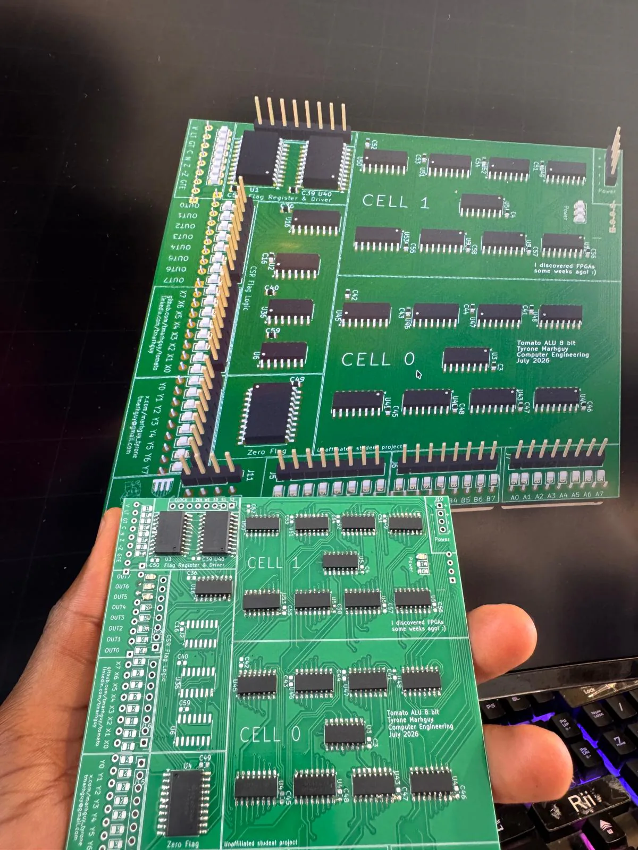
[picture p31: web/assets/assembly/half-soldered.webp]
Half-soldered 07_alu held next to its Digital simulation.
  
</p>
<p align="center"><em>Copper next to Digital. The same slice.</em></p>

Each one fit so nicely that it made the months of routing and DRC feel suddenly concrete. Designing the paths in KiCad is one thing. Seeing the copper line up with the pins is another. This board is finally coming to life.

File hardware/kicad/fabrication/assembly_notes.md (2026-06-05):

# Assembly Notes

Assembly instructions and notes for PCB fabrication.

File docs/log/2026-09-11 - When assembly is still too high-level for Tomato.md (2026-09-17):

I’m expanding Tomato’s ISA beyond its current 52 burned opcodes, and one idea keeps becoming more important:

**the lower I go, the more of the machine I can actually see.**

If I understand exactly what the hardware can do in one cycle, I can design algorithms around its natural operations instead of forcing the machine to imitate conventional instruction sets.

That matters on Tomato because the execution unit can evaluate operations of the form $f(a, b, c) + g(a, b, c) + cin$ in **one cycle**.

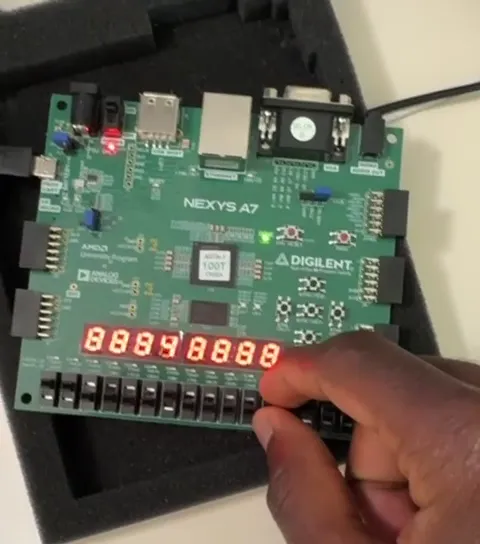
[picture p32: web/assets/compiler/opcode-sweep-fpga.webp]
Opcode search running on the Tomato FPGA hardware compiler
<p align="center"></p>

*FPGA hardware recording · the compiler searches ALU control rows; select the poster to play the capture.*

A compiler—or even a programmer writing ordinary assembly—may see an expression such as an XOR3 combined with some unusual NAND/NOR function and break it into several familiar instructions. Tomato may already be able to perform that entire expression directly.

That exposes an interesting problem: **assembly itself can become an abstraction barrier.**

Assembly languages are built around operations people have already decided are useful enough to name: `ADD`, `XOR`, `AND`, `NOR`, shifts, branches, and so on. There is no natural mnemonic for every strange function Tomato’s datapath can express, nor should there necessarily be.

But if the hardware can perform those functions natively, restricting access to only the operations we already know how to name leaves part of the machine unexplored.

So instead of asking:

> *What instructions should Tomato have?*

I'm curious to know:

> **What is the most direct way to expose the computation the hardware is already capable of?**

If the doors and the keys already exist, why add another locked door between them? That’s the direction I want to explore as the ISA grows.

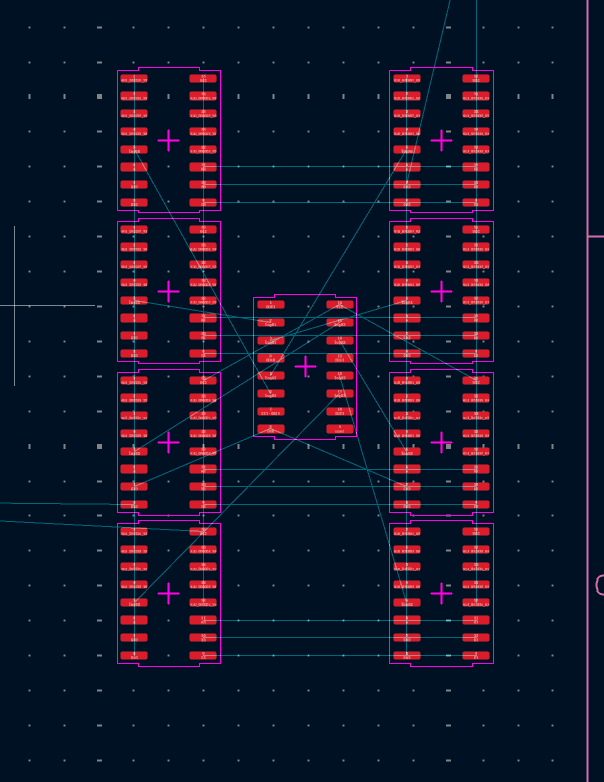
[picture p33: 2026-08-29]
web/assets/assembly/early-ratsnest-nine-ics.png

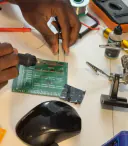
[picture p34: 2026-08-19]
web/assets/gallery/assembly/placing-and-soldering-128w.webp

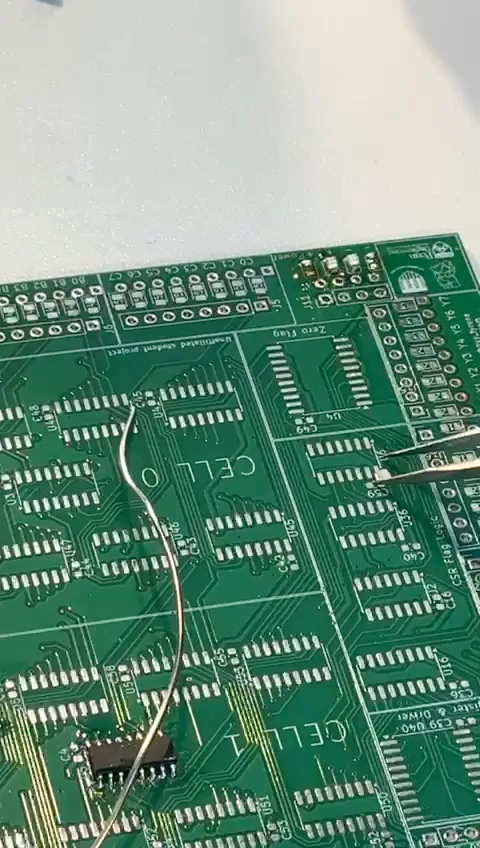
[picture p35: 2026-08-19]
web/assets/assembly/soldering-led.webp

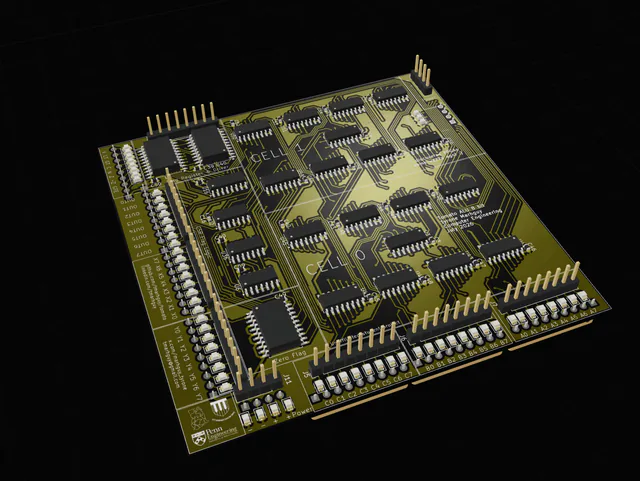
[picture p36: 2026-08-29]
web/assets/gallery/assembly/3d-olive-penn-branding-640w.webp

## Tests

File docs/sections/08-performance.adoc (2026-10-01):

[[performance]]
== Performance

This chapter gives the clock, throughput, and video numbers with exact
wording. Each number names its domain; domains are never merged.

=== Clocks

[width="100%",cols="34%,33%,33%",options="header"]
|===
|Quantity |Value |Meaning
|Board oscillator |100 MHz |Nexys A7 input clock
|CPU clock (default) |6.25 MHz |Board clock divided by 16 (`CPU_DIV_LOG2 = 4`)
|Pixel clock |25 MHz |Board clock divided by 4; 640x480 scanout at ~59.52 Hz
|Routing target |90 MHz |nextpnr `--freq` timing target, not a runtime frequency
|===

[stem]
++++
f_{cpu} = 100\ \mathrm{MHz} / 16 = 6.25\ \mathrm{MHz},
\qquad
f_{refresh} \approx \frac{25\ \mathrm{MHz}}{800 \times 525} \approx 59.52\ \mathrm{Hz}
++++

The 90 MHz value is the configured place-and-route timing target in
`hardware/fpga/core/Makefile` (`FREQ_MHZ := 90`).
It is not an oscillator value, CPU runtime frequency, measured Fmax, or
instruction rate.

=== Throughput projection

At 6.25 MHz, instruction throughput depends on cycles per instruction
(CPI). Checked-in Icarus samples range from 2.000 to 2.556 CPI;
converting the unweighted ~2.13-CPI summary gives a workload-derived
projection, not measured board throughput:

[stem]
++++
\mathrm{MIPS} \approx \frac{6.25}{2.13} \approx 2.9
++++

Authority: `hardware/fpga/core/reports/CPI.md` and `METRICS.md`.
Do not present this as a universal operations-per-second rating.

=== Browser execution budget

Virtual execution is host-budgeted functional execution.
A guest-timer constant models a 6.25 MHz CPU for timer purposes, while the
UI loop runs as many ISA steps as an 8 ms / 60,000-step frame budget
permits. It must not be described as a 6.25 MHz or cycle-accurate emulator.
Authority: `web/js/tomato-cpu.js`, `web/js/virtual.js`.

IMPORTANT: Throughput, oscillator, pixel clock, routing target, and
emulator budget are different metrics.
State the domain with every number.

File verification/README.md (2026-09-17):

# Tomato — ALU verification

<p align="center"><strong>Formal and directed checks, plus an optional UVM harness, for the dual-LUT ALU.</strong></p>

 

Layered verification for the **Tomato dual-LUT 32-bit ALU**: independent
3-input LUT planes per bit, ripple carry across byte slices, and flag latches
on the top 8-bit slice — `out = f(a,b,c) + g(a,b,c) + cin`. Checks run from
the 1-bit programmable-LUT cell through the exported 32-bit netlist.

**Tools:** SymbiYosys formal (1b → 8b → 32b comb + sequential flag cover), Icarus directed replay of Digital test vectors, Questa UVM with a shared reference model.

**FPGA dual-LUT ALU:** [gauntlet/](gauntlet/) — recorded Verilator **10B**
(8-bit) and **130B** (32-bit) runs plus SymbiYosys on a copy of
[`hardware/fpga/core/rtl/alu.v`](../hardware/fpga/core/rtl/alu.v). The harness
and reproduction targets are checked in; full run logs are not.
`make gauntlet_smoke` · `make gauntlet_claim`.

**Harness root:** `verification/` · **RTL policy:** Digital exports in `rtl/`
are read-only copies — regenerate from
[alu-32b-final.dig](../hardware/digital/modules/alu-32b-final.dig), then rerun
the intended verification tier.

**Project map:** [Root README](../README.md) · **ASIC metrics:** [synthesis/README.md](synthesis/README.md) · **Carry benchmark:** [test/README.md](../test/README.md)

<p align="center">
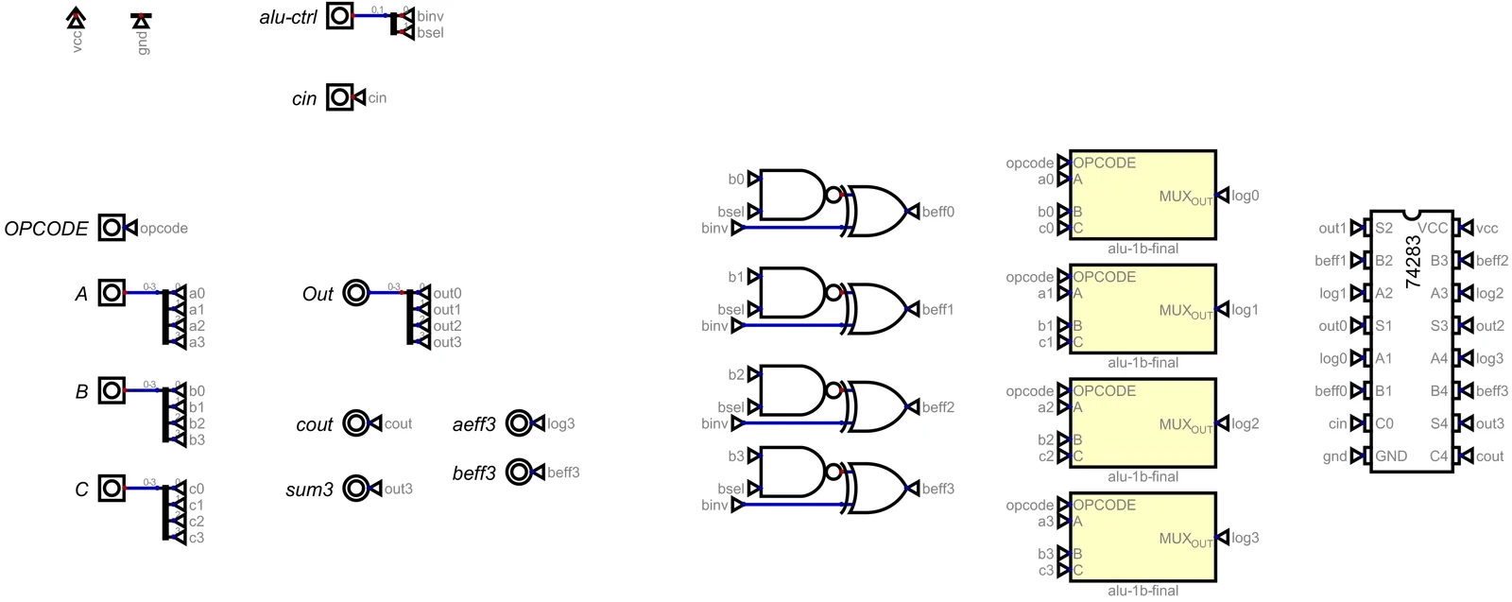
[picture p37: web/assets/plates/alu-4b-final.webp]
ALU 4-bit cell plate
  
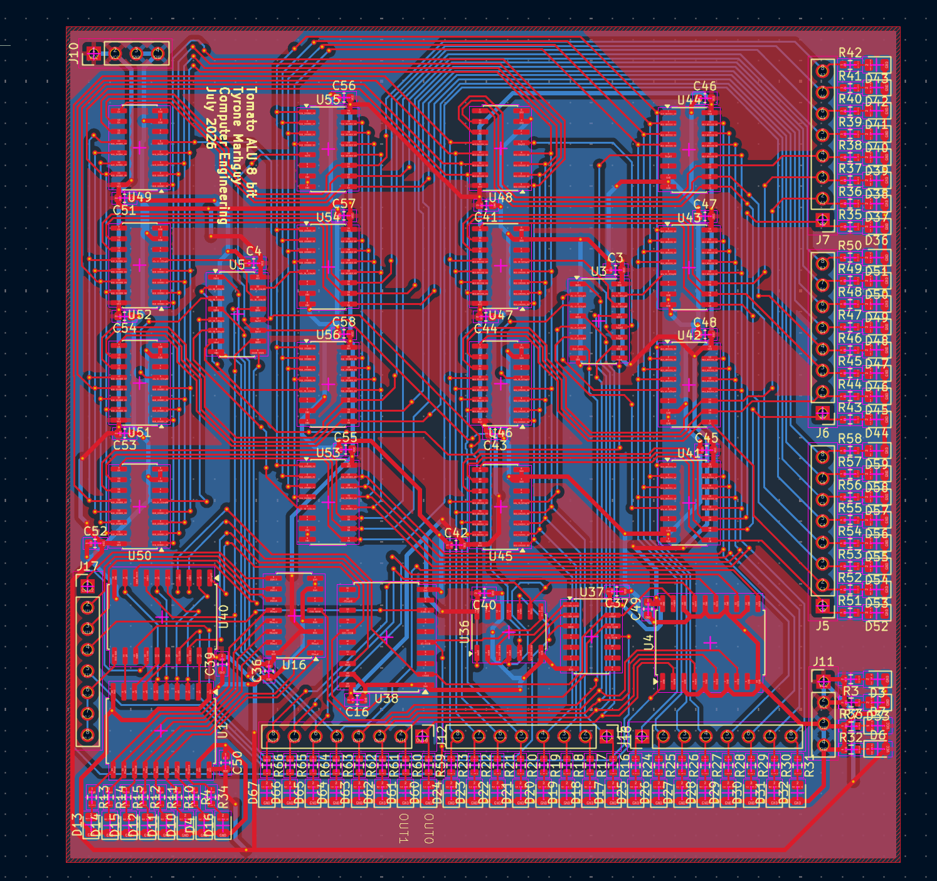
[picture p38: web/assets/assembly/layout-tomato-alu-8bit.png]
Tomato 8-bit ALU layout
  
</p>
<p align="center"><em>What gets proved · Dual-LUT slice hierarchy</em></p>

---

## Table of Contents

- [Recorded result](#recorded-result)
- [What each layer proves](#what-each-layer-proves)
- [Quick start](#quick-start)
- [Layout](#layout)
- [Sign-off criteria](#sign-off-criteria)
- [Known limits](#known-limits)
- [Related docs](#related-docs)

---

## Recorded result

**Date:** 2026-06-19 · **Netlist:** `rtl/alu-32b-final.v` (Digital export)

This table records the cited run; it is not a live CI dashboard. UVM rows still
require a local Questa installation.

| Step | Tool | Scope | Result | Notes |
|---|---|---|---|---|
| G | `generate.py` | 91-op table + 476 directed vectors | **PASS** | Skips 6 flag-only vectors (exp=`x`) |
| F1 | SymbiYosys | `alu-1b-final` — LUT3 + G/P | **PASS** | k-induction, z3 |
| F2 | SymbiYosys | `alu-8b-final` — per-bit LUT3 + G/P | **PASS** | k-induction, z3 |
| F3 | SymbiYosys | `alu-32b-final` — 12 spot properties | **PASS** | fast regression |
| F4 | SymbiYosys | `alu-32b-final` **full comb equiv** | **PASS** | ~74 s — all inputs, `CSR_FLAG[4]` as `flag_c` |
| F5 | SymbiYosys | flags reachability | **PASS** | cover mode |
| L | Verilator | Lint all slices | **PASS** | |
| D | Icarus | **476/476** vectors vs golden | **PASS** | no skips; `flag_c` 0/1 for `csel=10` |
| U | Questa UVM | 1b + 8b + 32b | **Requires Questa** | scoreboard uses full golden |

```bash
make signoff        # fast local sign-off (~35 s): spot formal + directed + lint
make signoff_full   # adds formal_32b_equiv end-to-end comb proof
```

From repo root: `make test` runs the zero-provisioning open tier, `make signoff` the strict sign-off above.

---

## What each layer proves

| Layer | Proven property |
|---|---|
| **Formal 1b** | For all inputs: `MUX_OUT = OPCODE[{C,B_eff,A_eff}]`, `G = A_eff & B_eff`, `P = A_eff ^ B_eff`. Complete programmable-LUT plane for one bit. |
| **Formal 8b** | Same relations applied independently to each of 8 bit-slices (parallel 1b composition). |
| **Formal 32b equiv** | `Out === golden(..., CSR_FLAG[4])` for all inputs (`make formal_32b_equiv`) |
| **Formal 32b spot** | 12 fast regression properties — subset of equiv (`make formal_32b`) |
| **Formal 32b flags** | Cover: FLAG_WE reachability (`make formal_32b_flags`) |
| **Directed** | **476/476** vs unified golden (all `csel`, all opcodes) | `make directed` |
| **UVM 1b** | Scoreboard on every stimulus: MUX_OUT + G + P vs `alu_ref_model_pkg`. Exhaustive test: 128-row `0x96` table + 256× LUT sweep + G/P corners. |
| **UVM 8b** | Full 8b `out`, `G`, `P` vs ref model; random, CLA boundary, and logic-sweep sequences. |
| **UVM 32b** | Clock-driven env; comb `Out` check + `CSR_FLAG` when `FLAG_WE`; 91-op coverage bin; SVA `FLAG_WE → !$isunknown(CSR_FLAG)`; 7 tests + full regression. |

---

## Quick start

```bash
cd verification

# Tier 1 — no Digital exports, no Questa (~30 s + gauntlet formal):
# Needs python3 + sby/solvers (OSS CAD Suite on PATH — see gauntlet/README.md).
make test               # vectors + inventory + gauntlet formal (1b/8b/32b)

# Tier 2 — full sign-off. One-time provisioning first (local-only, gitignored):
#   Digital → open hardware/digital/modules/alu-{1b,8b,32b}-final.dig →
#   Export Verilog → save as rtl/alu-{1b,8b,32b}-final.v (see rtl/README.md).
#   (The committed synthesis/rtl/alu-32b-final.v copy has a different
#   top-level port map — do not substitute it.)
#   Every strict target checks this first and tells you if it is missing.

# No commercial simulator license required
make signoff              # fast local sign-off (~35 s)
make signoff_full         # + 32b equiv prove (~3 min)
make formal_32b_equiv     # full comb proof (~74 s)
make directed             # 476 vectors (Icarus)
make generate             # re-extract vectors from the Digital TBs

# Questa required (vlog/vsim on PATH)
make uvm_1b_exhaustive
make uvm_8b_full
make uvm_32b_regression   # directed + ops91 + edge + flag + 10k random
make uvm_regression       # 1b exhaustive + 8b full + 32b regression

# FPGA ALU gauntlet (Verilator + SymbiYosys on hardware/fpga/core copy)
make gauntlet_smoke        # 1e6 vectors each, ~1 min
make gauntlet_10b          # 10e9 on 8b slice, ~7 min
make gauntlet_130b         # 130e9 on 32b ALU, ~2-3 h
make gauntlet_claim        # formal + 10B + 130B → gauntlet/results/CLAIM.txt
# Pilot before the full run: make gauntlet_130b VECTORS_130B=100000000 SEED=7
# Full reference: [gauntlet/README.md](gauntlet/README.md)

# Sky130 synthesis characterization
make synth                # see synthesis/README.md
```

**Dependencies (local sign-off):** `python3`, `yosys`, `symbiyosys` (`sby`), `z3`, `iverilog`, `verilator` — plus the `rtl/` netlists above for the strict tier. `make help` lists every target; anything missing fails fast with the exact fix. (Gauntlet proofs reuse the FPGA OSS CAD Suite solvers already in `hardware/fpga/.tools/`.)

**UVM:** [Questa Intel FPGA Starter](https://www.intel.com/content/www/us/en/software-kit/750666/intel-quartus-prime-lite-edition-design-software-version-23-1-for-windows.html) or equivalent with `vlog`/`vsim`. `uvm_*` targets check for them first and stop with a pointer if absent.

**Before first run:** provision the Digital-export netlists (`alu-1b-final.v`, `alu-8b-final.v`, `alu-32b-final.v`) into `rtl/` — see [rtl/README.md](rtl/README.md). `rtl/` holds only local, gitignored copies.

---

## Layout

```
verification/
├── README.md           ← you are here
├── Makefile            ← targets (`test` open tier; `signoff`, formal, UVM, synth)
├── rtl/                → [rtl/README.md](rtl/README.md) — Digital-export DUT netlists
├── formal/             → [formal/README.md](formal/README.md)
├── directed/           → [directed/README.md](directed/README.md)
├── gauntlet/           → [gauntlet/README.md](gauntlet/README.md) — FPGA ALU 10B/130B + SymbiYosys
├── synthesis/          → [synthesis/README.md](synthesis/README.md) — Yosys → Sky130 HD
├── uvm/                → [uvm/README.md](uvm/README.md)
│   ├── common/         → ref model, op table, directed vectors (generated pkgs committed)
│   ├── alu_1b/         → [uvm/alu_1b/README.md](uvm/alu_1b/README.md)
│   ├── alu_8b/         → [uvm/alu_8b/README.md](uvm/alu_8b/README.md)
│   └── alu_32b/        → [uvm/alu_32b/README.md](uvm/alu_32b/README.md)
└── scripts/            → generate.py (Digital-TB vector extractor → directed/run_extracted_tb.v)
```

Generated at build time (gitignored in root `.gitignore`): `work/`, `results/`, `formal/alu_*_verify/`, `directed/run_extracted_tb.v`, `synthesis/reports/`, `test/reports/`.

---

## Sign-off criteria

**Scope reminder:** this harness signs off the **ALU export**, not the full Tomato CPU, ISA decode, memory system, or FPGA top.

| Metric | Target | Command |
|---|---|---|
| Open tier (no DUT) | vectors + inventory + gauntlet formal PASS | `make test` (= `signoff_open`) |
| Formal 1b LUT + G/P | PASS (prove) | `make formal_1b` |
| Formal 8b per-bit | PASS (prove) | `make formal_8b` |
| Formal 32b equiv | PASS (all inputs) | `make formal_32b_equiv` |
| Formal 32b spot | PASS (fast) | `make formal_32b` |
| Formal 32b flags | PASS (cover) | `make formal_32b_flags` |
| Formal inventory | **5/5 jobs**; **19 assert + 20 cover** (40+48 elaborated) | `make formal_inventory` → [formal/PROPERTY_INVENTORY.md](formal/PROPERTY_INVENTORY.md) |
| Directed vectors | 476/476 pass vs ALU golden | `make directed` |
| FPGA ALU smoke | Verilator 1e6 on 8b + 32b | `make gauntlet_smoke` → [gauntlet/](gauntlet/) |
| FPGA ALU 10B | Verilator 10e9 on 8b slice (~7 min) | `make gauntlet_10b` |
| FPGA ALU 130B | Verilator 130e9 on 32b ALU (~2–3 h) | `make gauntlet_130b` |
| FPGA ALU (core copy) | SymbiYosys 1b+8b+32b; Verilator 10B / 130B | `make gauntlet_claim` → [gauntlet/](gauntlet/) |
| Lint | 0 errors | `make lint` |
| UVM `op91_cp` | Covergroup over **91 ALU control-table rows** (not 512 CPU opcodes, not toggle/branch %) | `make uvm_32b_ops91` (Questa) |
| UVM directed replay | 476 vectors | `make uvm_32b_directed` |
| UVM full regression | 0 scoreboard errors | `make uvm_32b_regression` |

---

## Known limits

| Limit | Status |
|---|---|
| Scope = **ALU only** | Full CPU / FPGA / ISA ROM are **not** covered by this harness |
| `op91_cp` | 91 **ALU** `(lut,ctrl,csel)` table rows — **not** 512 ROM opcodes, not code coverage |
| Toggle / branch / line coverage | **Not measured** here |
| `csel==2'b10` carry-fed logic | **Closed** — unified ripple-LUT golden; `Flag_C` primary input in formal |
| Directed 476 vectors | PASS vs golden; many vectors exercise modes beyond the 91 named rows |
| Sequential `CSR_FLAG` prove | **Cover + UVM** — SMT latch prove not feasible; use `alu_32b_flag_test` |
| UVM in CI | `verify.yml` runs vectors + inventory + gauntlet smoke + formal 1b; UVM needs Questa (local only) |

---

## Related docs

| Doc | Link |
|-----|---|
| Tomato architecture | [docs/architecture.md](../docs/architecture.md) |
| Synthesis (Sky130 metrics) | [synthesis/README.md](synthesis/README.md) |
| Kogge-Stone benchmark | [test/README.md](../test/README.md) |
| 91-op control map (authority) | [docs/alu/alu-1b/alu_control_map.tex](../docs/alu/alu-1b/alu_control_map.tex) |
| Digital source schematic | [alu-32b-final.dig](../hardware/digital/modules/alu-32b-final.dig) |
| Root shortcut | `make test` → open tier · `make signoff` → strict sign-off |

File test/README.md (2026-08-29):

# Sky130 benchmark — Kogge-Stone vs Tomato ALU

<p align="center"><strong>Same PDK · ripple Dual-LUT vs Kogge-Stone carry.</strong></p>

 

Side-by-side synthesis on **SkyWater 130nm HD** (same Yosys + ABC flow as [verification/synthesis](../verification/synthesis/README.md)):

**Project map:** [Root README](../README.md) · [Verification](../verification/README.md) · [Synthesis](../verification/synthesis/README.md)

| Design | What it is |
|---|---|
| **Ripple ALU** | Production netlist — dual-LUT + ripple 4b/8b carry + flags ([rtl](../verification/synthesis/rtl/alu-32b-final.v)) |
| **KS adder only** | Fastest classical carry topology — parallel prefix adder ([rtl/kogge_stone_32.v](rtl/kogge_stone_32.v)) |
| **ALU + KS** | Same dual-LUT datapath, Kogge-Stone 32b sum instead of ripple ([rtl/alu-32b-koggestone.v](rtl/alu-32b-koggestone.v)) |

We are **aware** that the programmable path is `adder(mux3_LUT, mux3_LUT, carry_in)` — the same mux3 planes per bit on both sides. Swapping ripple carry for Kogge-Stone is the standard way to close the speed gap while keeping LUT flexibility. Production Tomato keeps ripple for simpler physical design and integrated flag/zero logic.

---

## Results (2026-08-02)

| Metric | Ripple ALU | KS adder only | ALU + KS | Notes |
|---|---|---|---|---|
| Chip area | **6531 um^2** | **1101 um^2** | **4704 um^2** | ALU+KS **28% smaller** than ripple ALU |
| Cells | **512** | **186** | **378** | ALU+KS **26% fewer** cells than ripple |
| Sequential area | 9.81% | 0% | 0% | Flags stripped in ALU+KS benchmark |
| LTP depth (top) | **4** | ~5 prefix | **2** | Hierarchical LTP understates flattened KS |
| Comb. delay (est.) | **4.12 ns** | **2.23 ns** | **3.25 ns** | ALU+KS **1.27x** faster than ripple |
| Fmax comb. (est.) | **243 MHz** | **449 MHz** | **308 MHz** | ALU+KS **1.27x** faster than ripple |
| Reg. cycle (est.) | **4.77 ns** | **2.88 ns** | **3.90 ns** | ALU+KS **1.22x** faster than ripple |
| Fmax registered (est.) | **210 MHz** | **347 MHz** | **256 MHz** | ALU+KS **1.22x** faster than ripple |

Full machine-readable output: [reports/comparison.txt](reports/comparison.txt), [reports/metrics.txt](reports/metrics.txt), [reports/alu_ks_metrics.txt](reports/alu_ks_metrics.txt).

---

## What this means

**Same datapath, faster carry.** ALU+KS keeps the dual 3-input LUT planes (`lutA`, `lutB` mux3 per bit) and replaces the four-slice ripple chain with one Kogge-Stone 32b add. That recovers most of the speed lost to ripple (~308 MHz comb vs ~243 MHz) while staying programmable.

**KS adder-only is still the speed ceiling.** A hardened prefix adder with no LUT muxes is ~1.45x faster comb than ALU+KS and ~4.3x smaller — expected, since it only adds.

**Ripple ALU trades speed for integration.** Flags, carry select, and byte-slice hierarchy add ~10% sequential area and keep carry depth at four slice boundaries — a deliberate PCB/PD choice, not an unawareness of prefix adders.

Timing uses the same **pre-route liberty arc estimate** methodology as the synthesis README (LUT mux depth + KS prefix levels for ALU+KS; not OpenSTA sign-off).

---

## Run

Requires OSS CAD Suite and liberty in `../verification/synthesis/pdk/` (run `verification/synthesis/scripts/fetch_lib.ps1` if missing).

```powershell
cd test
.\run.bat
```

```bash
cd test
./run.sh
```

Outputs: `reports/synth.log`, `reports/metrics.txt`, `reports/alu_ks_synth.log`, `reports/alu_ks_metrics.txt`, `reports/comparison.txt`.

---

## Layout

```
test/
├── README.md
├── run.bat / run.sh
├── rtl/
│   ├── kogge_stone_32.v
│   ├── alu_slice_support.v      # Mux_8x1 + alu_1b_final
│   ├── alu_lut_planes_32.v
│   └── alu-32b-koggestone.v     # dual-LUT + KS top
├── scripts/
│   ├── synth.ys / synth_alu_ks.ys
│   ├── extract_metrics.py / extract_metrics_alu_ks.py
│   ├── estimate_timing.py / estimate_timing_alu_ks.py
│   └── compare.py
└── reports/                     # generated (gitignored)
```

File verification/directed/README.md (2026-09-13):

# Directed — Digital vector replay (Icarus)

Replays **476 test vectors** extracted from three Digital-exported testbenches. Compares DUT output against the unified golden in `alu_ref.v` (same model as formal equiv + UVM).

```bash
make directed    # builds run_extracted_tb.v via generate.py if missing, then iverilog + vvp
make generate    # force-reextract (after editing a source TB)
```

---

## Stimulus vs check

All **482** pattern rows are *applied* in source order — including the 6 flag-only rows whose expected-Out is `x` (they advance the flag latches, exactly as the Digital benches do). The **476** rows with a known expected-Out are *checked* against `alu_predict_out()`.

---

## Source testbenches (hand-maintained)

| File | Content |
|---|---|
| `alu-32b-final_Exhaustive 91 Ops Test_tb.v` | Bulk of the 91-op directed suite |
| `alu-32b-final_alu-comb-flags_tb.v` | Combinational + flag cases |
| `alu-32b-final_alu-flagc-carry_tb.v` | Flag/carry corner cases |

Digital module names contain spaces — **Icarus cannot compile them directly**. `scripts/generate.py` parses `144'b…` pattern lines and emits `run_extracted_tb.v`.

---

## Files

| File | Role |
|---|---|
| `alu_ref.v` | Unified ripple-LUT golden (`alu_predict_out`) |
| `alu_32b_dut_wrap.v` | Clean port names → escaped Digital ports |
| `run_extracted_tb.v` | **Generated** — 476-vector compare loop |

---

## Vector packing (144 bits)

```
[143:112] A
[111:80]  B
[79:48]   C
[47:40]   Opcode
[39:36]   control
[35:34]   csel
[33]      CLK (unused in compare)
[32]      FLAG_WE
[31:0]    expected Out (Digital golden — not used; we compare vs alu_ref.v)
```

---

## Timing and carry policy

The TB drives each vector with `clk = 0`, settles, then pulses the clock once so `FLAG_WE` latches exactly once per vector (the pattern `CLK` bit itself is ignored). `Out` is sampled after the edge.

Every checked vector is compared against `alu_predict_out()`:

```verilog
exp0 = alu_predict_out(A, B, C, Opcode, control, csel, csr_flag[4]);
// if mismatch and csel==2'b10, retry with flag_c=1
```

`flag_c` for carry-fed logic (`csel == 2'b10`) is the live latch bit the DUT itself reports — no opcode or `csel` skips. Six source vectors with `x` in the expected-out field are applied but not checked (flag-only stimulus).

---

## UVM reuse

Same 476 vectors in `uvm/common/directed_vectors_pkg.sv` for `alu_32b_directed_seq`.

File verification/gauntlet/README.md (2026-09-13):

# Tomato — ALU gauntlet

<p align="center"><strong>Verilator + SymbiYosys on the FPGA dual-LUT ALU.</strong></p>

 

Exhaustive-random verification of the working-machine ALU
(`hardware/fpga/core/rtl/alu.v`):

- **SymbiYosys** proves `alu1b`, `alu8b`, and the 32-bit datapath against `out = fa + fb + cin`
- **Verilator** drives **10 billion** vectors on the 8-bit slice and **130 billion** on the 32-bit ALU; every vector checks DUT against golden and exits on mismatch

This directory keeps a **committed copy** of `alu.v` — refresh with `make sync`;
do not edit `core/` from here. Every run asserts the copy matches core first
(`check-sync`), so a stale copy fails loudly instead of proving the wrong RTL.

---

## Prerequisites

| Tool | Needed for | Install |
|---|---|---|
| `verilator` | `smoke`, `run_10b`, `run_130b` | OSS CAD Suite (`make setup` in `hardware/fpga/core`) or `brew install verilator` |
| `sby` + solvers | `formal` | Same suite (`z3` for 1b, `bitwuzla` for 8b/32b ride along in `hardware/fpga/.tools/oss-cad-suite/bin`), or `brew install sby` |
| C++ toolchain | Verilator build | Xcode CLT / `build-essential` |

`make check-tools` asserts `sby` + `yosys` + `verilator` are on `PATH` with the fix
(`check-tools-sby` / `check-tools-verilator` check each side alone — smoke and the
long Verilator runs don't require `sby`, formal doesn't require `verilator`).
The gauntlet Makefile prepends `hardware/fpga/.tools/oss-cad-suite/bin` to `PATH`,
so a provisioned FPGA checkout works with no extra setup.

---

## Run tiers

| Tier | Command (here or via `verification/`) | Vectors | Wall time¹ | What it proves |
|---|---|---|---|---|
| Smoke | `make smoke` / `make -C verification gauntlet_smoke` | 1e6 on 8b + 1e6 on 32b | ~1 min | Build works, golden matches, no gross breakage |
| 10B | `make run_10b` / `make -C verification gauntlet_10b` | 10e9 on `alu8b` (8-bit) | ~7 min | Byte-slice exhaustive-random sign-off |
| 130B | `make run_130b` / `make -C verification gauntlet_130b` | 130e9 on `alu` (32-bit) | ~2–3 h | Full-datapath exhaustive-random sign-off |
| Formal | `make formal` / `make -C verification gauntlet_formal` | exhaustive (proof) | ~minutes | 1b + 8b + 32b `Out ≡ golden` for **all** inputs |
| Claim | `make claim` / `make -C verification gauntlet_claim` | formal + 10B + 130B | ~3 h | Everything → `results/CLAIM.txt` |

¹ Measured on Apple Silicon: ~25 Mvec/s (8b), ~13–16 Mvec/s (32b).
From the repo root: `make gauntlet-smoke`, `make gauntlet-10b`,
`make gauntlet-130b`, `make gauntlet-claim`.

```bash
cd verification/gauntlet
make sync            # refresh rtl/alu.v from core (after editing the FPGA ALU)

make formal          # SymbiYosys 1b + 8b + 32b
make smoke           # quick Verilator check, 1e6 vectors each
make run_10b         # 10,000,000,000 vectors on alu8b
make run_130b        # 130,000,000,000 vectors on alu
make claim           # formal + run_10b + run_130b → results/CLAIM.txt
```

Legacy aliases `make core10b` (= `run_10b`) and `make slice130b` (= `run_130b`)
still work; new docs and CI use the `run_*` names.

---

## Custom counts and seeds (pilots, repro)

All counts and the RNG seed are overridable. The seed is fixed by default,
so a re-run with the same seed replays the same stream.

```bash
make smoke VECTORS_SMOKE=100000                    # short smoke
make run_130b VECTORS_130B=100000000 SEED=7         # 1e8 pilot before the full run
make -C verification gauntlet_130b VECTORS_130B=100000000 SEED=7
```

| Variable | Default | Meaning |
|---|---|---|
| `VECTORS_SMOKE` | `1000000` | Vectors per DUT in `smoke` |
| `VECTORS_10B` | `10000000000` | Vectors in `run_10b` |
| `VECTORS_130B` | `130000000000` | Vectors in `run_130b` |
| `SEED` | `1` | xorshift64 seed (`0` → fallback stream) |
| `GAUNTLET_PROGRESS_EVERY` | `1000000000` | Vectors between `progress` status lines |

---

## Watching a long run

Every run already tees to a log file — open a second terminal and follow it:

```bash
tail -f verification/gauntlet/results/slice_130b.txt   # 130B run
tail -f verification/gauntlet/results/core_10b.txt     # 10B run
```

Log shape: one `alu32 start: target=… directed=… seed=…` banner line up front
(no more silent startup), then `progress N / TOTAL (x.xxx Gvec/s)` status lines,
then a final `PASS alu32 vectors=…` line. Default cadence is one status line per
1e9 vectors (minutes apart on some machines) — turn it up for a live run:

```bash
GAUNTLET_PROGRESS_EVERY=100000000 make run_130b   # status ~10x more often
```

`FAIL @N: …` on stderr with the exact vector means mismatch — the run exits
non-zero immediately, so any `PASS` line at the end means every vector matched.

---

## Stimulus, checking, logs

- **Directed warmup is baked in**, then random fill to the count:
  - 8b: full `lutA × lutB × {A,B,C} × cin` sweep (1,048,576 vectors), then random.
  - 32b: `PASS_A`+`PASS_B` low-byte sweep + `lutA` minterm sweep, then random
    (including periodic `flag_we` pulses so latched-carry paths are exercised).
- **Every vector is checked** against the shared golden (`verilator/golden.h`,
  mirroring `formal/alu_ref.v`). First mismatch prints the vector and exits non-zero —
  a passing run always ends with a `PASS alu8b …` / `PASS alu32 …` line stating
  vectors, directed count, seed, time, and rate. The long targets `grep` that line,
  so a truncated run fails instead of looking green.
- **Progress** prints every `GAUNTLET_PROGRESS_EVERY` vectors (default 1e9;
  `progress N / TOTAL (x.xxx Gvec/s)`), with a `… start: …` banner up front.
- **Logs** land in `results/` (gitignored): `smoke_8b.txt`, `smoke_32b.txt`,
  `core_10b.txt`, `slice_130b.txt`, and `CLAIM.txt` (claim only — records date,
  `dut_sha256`, `git_rev`, seed, and vector counts for reproducibility).

---

## Layout

```
gauntlet/
├── rtl/alu.v           committed copy of fpga/core (make sync)
├── formal/             .sby jobs + alu_ref.v + binds
├── verilator/          C++ benches + golden.h
├── obj/                build (gitignored)
└── results/            PASS logs + CLAIM.txt (gitignored)
```

Also: Digital-export ALU harness in [verification/README.md](../README.md) ·
machine in [hardware/fpga/core/README.md](../../hardware/fpga/core/README.md).

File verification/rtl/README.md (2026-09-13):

# RTL — Digital-exported DUT

Read-only netlists copied from Digital. **Do not edit** verification logic into these files; bind wrappers, UVM, and directed TBs live in sibling folders.

Files in this directory (except this README) are **local-only and gitignored** — every sign-off target checks for them first (`make …` tells you exactly which export is missing).

## Provisioning (one-time)

1. Install [Digital](https://github.com/hneemann/Digital) and open `hardware/digital/modules/`.
2. For each of `alu-1b-final.dig`, `alu-8b-final.dig`, `alu-32b-final.dig`: **Export → Verilog**, save here as `alu-1b-final.v`, `alu-8b-final.v`, `alu-32b-final.v`.
3. Re-run `make -C verification signoff`.

## Files

| File | Top module | Role |
|---|---|---|
| `alu-1b-final.v` | `\alu-1b-final` | 1-bit programmable LUT cell + G/P propagate/generate |
| `alu-8b-final.v` | `\alu-8b-final` | 8-bit slice (8× 1b + CLA glue) |
| `alu-32b-final.v` | `\alu-32b-final` | Full 32-bit ALU: opcode LUT, control decode, CLA, flag latches |

## Port naming

Digital exports use escaped identifiers (e.g. `\~flag_a_is_zero`). Wrappers in `directed/alu_32b_dut_wrap.v` and formal bind modules map these to simulation-friendly names.

## How each layer uses RTL

| Consumer | File used |
|---|---|
| Formal 1b | `alu-1b-final.v` |
| Formal 8b | `alu-8b-final.v` |
| Formal 32b / flags | `alu-32b-final.v` |
| Directed (Icarus) | `alu-32b-final.v` |
| UVM 1b | `alu-1b-final.v` |
| UVM 8b | `alu-8b-final.v` |
| UVM 32b | `alu-32b-final.v` + `alu_32b_assertions.sv` (bind) |
| Lint | All three (Verilator reports `MODDUP` for shared submodules — expected) |

## Source of truth

Regenerate from Digital when the schematic changes, then re-run `make signoff`. The behavioral contract is defined in `docs/alu/alu-1b/alu_control_map.tex` and checked by formal bind properties + `uvm/common/alu_ref_model_pkg.sv`.

Do **not** substitute `synthesis/rtl/alu-32b-final.v` here: it is a genuine Digital export but its top-level port map (`lutA`/`lutB`, 3-bit `csel`, 8-bit `csr`) differs from what the directed wrapper and formal binds expect (`Opcode`, `control`, 2-bit `csel`, 13-bit `CSR_FLAG`). Export all three netlists fresh from the current `.dig` sources.

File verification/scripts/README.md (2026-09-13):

# Verification helper scripts

| Script | Role |
|---|---|
| [`generate.py`](generate.py) | Parse `144'b…` pattern lines out of the three Digital TBs in `directed/` and emit `directed/run_extracted_tb.v` (482 stimulus rows applied, 476 checked). Output order matches `uvm/common/directed_vectors_pkg.sv`. |
| [`inventory_formal.py`](inventory_formal.py) | Recount ALU formal assert/cover → `formal/PROPERTY_INVENTORY.md` |

```bash
make -C verification generate formal_inventory
```

Note: the committed packages under `uvm/common/` (op table, directed vectors, ref model) remain authoritative — `generate.py` only rebuilds the Icarus replay bench from the same sources.

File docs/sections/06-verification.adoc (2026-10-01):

[[verification]]
== Verification

This chapter states what has been checked, with commands that reproduce
each claim. Simulation evidence is labeled simulation; it never stands in
for physical execution.

=== Strategy

[width="100%",cols="32%,38%,30%",options="header"]
|===
|Layer |Method |Reproduce
|ISA consistency |Microcode checker |`python3 tools/gen_microcode_v1.py --check`
|Assembler vocabulary |Selftest |`python3 software/assembler.py --selftest`
|Core regression |Icarus testbenches |`make -C hardware/fpga/core test`
|OS boot in simulation |Icarus OS run |`make -C hardware/fpga/core os`
|ALU / datapath |Directed + formal + gauntlet |`make gauntlet-smoke`
|===

NOTE: The table above is the verification contract.
A passing build or simulation does not prove a board is programmed.

=== Focused checks

[source,bash]
----
python3 tools/gen_microcode_v1.py --check
python3 software/assembler.py --selftest
make -C hardware/fpga/core burn-check
----

The first two check the ISA and assembler contracts.
The third checks the FPGA burn against the ISA source.
Full simulation and hardware programming are separate activities.

=== ALU record

The verification record reports a completed 130-billion-vector 32-bit ALU
run against a reference model.
The harness and reproduction command are checked in; the full run log and
artifact are not.

[source,bash]
----
# FPGA ALU gauntlet (Verilator + SymbiYosys on the core copy)
# smoke: ~1 min | 10b: ~7 min | 130b: ~2-3 h | claim: formal + 10b + 130b
make gauntlet-smoke
make gauntlet-10b
make gauntlet-130b
make gauntlet-claim
----

Details and scope limits live in `verification/gauntlet/README.md`.
The counter-FSM search over all 65,536 LUT pairs verifies one fixed
example per hit; it does not prove a general function.

=== Simulation vs hardware

* _RTL simulation_ means the local Icarus-driven machine and testbenches.
  Label its results simulation, never physical execution.
* _Virtual_ means the browser ISA-level emulator. It is host-budgeted
  functional execution, not a 6.25 MHz or cycle-accurate emulator.
* _Hardware_ means the FPGA machine with live completion evidence from an
  active bridge. Source, screenshots, tests, or build output alone do not
  qualify.

WARNING: A timeout on a hardware job means the outcome is unknown.
Do not silently replay it virtually and present the replay as hardware output.

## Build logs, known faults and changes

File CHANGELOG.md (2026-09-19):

# Changelog

Tomato’s project history, written from the engineering journal
([`docs/log/`](docs/log/)) and the full git timeline (606 commits,
2026-06-05 → 2026-09-18). This is not a dump of commit subjects: each
section explains what changed, why it mattered, and what was later
superseded.

**Current machine facts** live in [`docs/status.md`](docs/status.md).
Where a journal entry disagrees with that file (word width, opcode
counts, register file size, OS version), the status file wins. Journals
remain valuable as the trail of how the machine was discovered.

---

## Unreleased

Local work not yet committed to `main` (ISA LUT CSV exploration,
remote-compute preview notes, Nordic envelop setup scratch, regenerated
FPGA/microcode artifacts, and similar) is omitted until it lands.

---

## [2026-09-14] – [2026-09-18] — Envelop, Dual-LUT compiler, Virtual Tomato

Tomato stopped being only a desktop-on-HDMI demo and grew a path to the
outside world: a messaging client, a bounded remote compute story, and a
browser emulator that can run the same OS image without waiting on a
bitstream.

### Envelop (messaging + remote compute)

Envelop began as a separate project so Tomato could send and receive
text without turning the Tomato repository into a chat product. The
name replaced a short-lived “Pigeon” label. On the Tomato side, an OS
menu entry, assembly client, and bounded executor were linked into the
firmware image; web/native clients, backend, and nearby bridge live in
the Envelop repository.

Design choices that stuck:

- **Chat-only scope.** Envelop is not a general companion app. It
  carries messages and bounded compute requests.
- **Nearby radio as a radio.** An nRF8001 ACI controller was wired onto
  the Nexys path so the FPGA talks BLE ACI rather than absorbing Wi-Fi
  into the same board story. Nordic-generated setup records are not
  redistributed; physical radio use needs a locally supplied setup
  image.
- **Provenance over personality.** Remote math is a tiny deterministic
  parser → Tomato IR path, fail-closed on unknowns—not an LLM persona
  pretending to be the machine.
- **Hardware vs preview are separate.** A hardware job that times out
  is an unknown outcome; it must not silently fall back to Virtual
  Tomato. Browser preview is explicit and labeled.

Journal trail:
[Origin](docs/log/2026-09-14%20-%20Envelop%20Origin.md),
[message app](docs/log/2026-09-14%20-%20Envelop%20-%20Tomato%20gets%20a%20message%20app.md),
[Native Bridge](docs/log/2026-09-14%20-%20Envelop%20Native%20Bridge.md),
[Website and World Connect](docs/log/2026-09-14%20-%20Envelop%20Website%20and%20World%20Connect.md),
[Multiple Participants](docs/log/2026-09-14%20-%20Multiple%20Participants.md),
[Parsing](docs/log/2026-09-15%20-%20Envelop%20Parsing%20-%20Simplest.md),
[Scope](docs/log/2026-09-15%20-%20Envelop%20Scope%20Optimization.md),
[Virtual vs AI](docs/log/2026-09-15%20-%20Virtual%20Fallback%20vs%20AI.md).

### Dual-LUT compiler on the FPGA

The opcode-search idea from July returned as real RTL: a 16-bit counter
FSM that enumerates all 65,536 `{lutB,lutA}` pairs for fixed A, B, C,
carry, and expected output, stopping at the first match. A hit proves
that example only—not a full truth table. HOLD/RESET controls and a
Compiler panel landed in the OS menu so the sweep is visible on the
desktop, not only in a testbench.

MMIO mapped the compiler (and radio) onto the keyboard-adjacent control
plane so software could drive the hardware without inventing a second
I/O architecture.

### Virtual Tomato

Long synth waits pushed a Python/web preview that runs the assembled OS
image functionally. Instead of discarding it, the preview became
**Virtual Tomato** on the site: a functional ISA-level emulator with
dual-LUT ALU behavior, banks, MMIO, and an ACI mailbox model—honestly
labeled as not cycle-accurate and not a substitute for a programmed
board. Image build tooling packs mem words, microcode planes, and
assets into a checked-in web image with freshness checks.

Journal:
[Synthesis Bypass](docs/log/2026-09-14%20-%20Synthesis%20Bypass.md),
[Discard or Integrate](docs/log/2026-09-15%20-%20Discard%20Previewer%20or%20Integrate.md).

### Documentation and site

Canonical project facts were written down, the docs hierarchy rebuilt,
architecture diagrams published, and the public site foregrounded the
board plus live OS/compiler story. The build journal became searchable.
An Ethernet bring-up harness appeared briefly and was removed as a
superseded experiment.

### Also in this window

- Assembler and microcode regenerated for the expanded ALU family;
  FPGA burn/sim copies kept in sync.
- Envelop firmware shipped with site refresh; remote/Envelop test
  targets made self-contained.
- Dual-LUT remote ABI polish and live board activity LEDs (2026-09-18).

**PRs:** #34 (compiler FSM), #35/#36 (messaging entry points).

---

## [2026-09-05] – [2026-09-13] — Desktop v1.2, ISA growth, open verify

### Desktop polish on real glass

With HDMI working, attention shifted to making Tomato feel like a small
computer rather than a menu of demos. Ghana wallpaper was burned as an
RGB444 ROM and composited under the text framebuffer. Data memory grew
to **384 KiB**. Keypad debounce was restored and exercised so one press
stayed one press after the earlier edge fix.

**Sudoku** joined the OS despite the five-button keyboard: arrows move,
a button cycles digits 1–9—hardware limits treated as UI constraints,
not blockers. An HDMI capture card replaced phone-at-monitor footage
for documentation.

The workspace UI revision is **Desktop v1.2**; the assembled OS title
string is **TOMATO OS v3.0** with a **14-entry** menu (see status.md).
Early August’s six-entry menu and ~52-opcode burns are historical.

Journal:
[Sudoku](docs/log/2026-09-11%20-%20Of%20Course%20Tomato%20Needs%20Sudoku.md),
[Wallpaper & polish](docs/log/2026-09-11%20-%20Wallpaper%2C%20Polish%2C%20and%20the%20Rest%20of%20the%20Computer.md),
[HDMI captured](docs/log/2026-09-11%20-%20HDMI%2C%20Properly%20Captured.md),
[Assembly barrier](docs/log/2026-09-11%20-%20When%20assembly%20is%20still%20too%20high-level%20for%20Tomato.md).

### ISA upgrade — naming what the ALU already could do

Assembly mnemonics had been hiding capacity already present in the
dual-LUT hardware. Nine new ALU tricks were burned as named rows
without new chips—ANDN, ORN, CSEL, the MASKADD family (ANDADD / ORADD /
XORADD), ADC, SBC, RSB—taking the control ROM from the mid-50s up to
**61 instructions plus NOP (62 burned rows)** in a 512-row table.
Pseudos still do not add burned rows.

A latent RSB bug (always returning zero) was caught and fixed; a
`p0p1` regression covers the new set. MASKADD/XORAND also landed in
assembler, microcode packing, FPGA headers, and exhibit benches (ALU
Studio alongside Sudoku and Racer).

Journal: [ISA Upgrade](docs/log/2026-09-13%20-%20ISA%20Upgrade.md).

### Verification and CI

An open verification tier was added: gauntlet smoke / 10B / 130B paths,
signoff separated from everyday `make test`, a GitHub verify workflow,
and a Digital testbench extractor. Bare FPGA `make` targets wrap
through `env.sh`. Solderpad **SHL-2.1** SPDX headers were restored after
the mid-August license experiment.

**PR:** #33.

---

## [2026-08-26] – [2026-08-31] — HDMI OS, FOSS FPGA flow, “Tomato works”

### Video that actually reaches a monitor

Passive VGA→HDMI adapters failed on the lab monitor. The pivot was a
**PMOD DVI** path so the Artix-7 generates pixel data on pins that
already work. Color bars appeared immediately once the module arrived;
Tomato OS GUI work was unblocked.

Journal: [PMOD Pivot](docs/log/2026-08-26%20-%20The%20PMOD%20Pivot.md),
[Successful Video](docs/log/2026-08-28%20-%20Successful%20Video%20-%20FPGA%20+%20PMOD.md),
[Pixels on the Glass](docs/log/2026-08-28%20-%20Pixels%20on%20the%20Glass.md).

### Leaving Vivado as the daily driver

With video proven, Vivado on the available Windows machine became the
bottleneck. The default FPGA flow moved to **Yosys → nextpnr-xilinx →
Project X-Ray → openFPGALoader**, with an optional Vivado batch target
kept for the same board. The point was minutes-scale iteration, not
abandoning Xilinx silicon.

Journal:
[Beyond Vivado](docs/log/2026-08-28%20-%20Exploring%20Beyond%20Vivado%20-%20Open-Source%20Synthesis%20Pivot.md).

### Tomato OS v1.0 on HDMI

A real desktop burned into dmem: chrome, About, Fibonacci, Snake,
Tetris, Racer. Assembler gained `.space` for runtime arrays.
Place-and-route was targeted at **90 MHz** (a nextpnr `--freq` goal—not
the CPU clock; the board still divides 100 MHz to a **6.25 MHz** CPU
domain per status.md).

### One press, one key

The menu was unusable: a single D-pad tap skipped several entries
because the edge stayed asserted for the entire sample window while
software polled thousands of times. The fix was a short debounce plus a
**one-clock-wide edge**, plus a temporary cut to a clean six-entry menu
while the input path settled. Assembler **pseudos** (`CALL`, `BEQZ`,
`LI`, …) were driven from `tomato.v1.pseudo.csv` and rewritten across
the OS without adding burned ROM rows—binary stayed byte-identical to
the expanded source story.

Journal: [One Press, One Key](docs/log/2026-08-28%20-%20One%20Press%2C%20One%20Key.md).

### Milestone: it feels like a computer

By 29 August the FPGA was driving a TV with a multi-thousand-line OS
and playable games—the first experience that matches the project’s
vocabulary of **FPGA Tomato as the complete machine**, while the
soldering bench still held a **discrete ALU slice**. Dual-LUT ALU
gauntlet verification was wired into the harness. Gallery and README
heroes filled with Lot 07 plates and OS stills. A discrete-era proposal
for a much larger register file appeared in narrative surfaces; the
**current FPGA RTL remains 256 × 32-bit entries**.

Journal:
[Tomato works beautifully!](docs/log/2026-08-29%20-%20Tomato%20works%20beautifully!.md).

**PRs:** #27–#32.

---

## [2026-08-16] – [2026-08-25] — Broadsheet web, media, first solder

### Making the site as careful as the copper

The public site stayed vanilla HTML/CSS/JS plus Three.js—no React
bundler. The 3D ALU tour was the performance crisis: a ~31 MB KiCad
GLB with tens of thousands of meshes froze the main thread. A Draco
pipeline (dedup → join → flatten → weld → compress) brought it to
~1.3 MB and a handful of meshes. Paper/Black stock themes, hero MP4s,
opcode-sweep clips (Digital sim and FPGA), and security/caching
headers on Vercel followed. A film-letterbox/fog camera pass was tried
and removed for honesty.

Journal:
[Web Optimization](docs/log/2026-08-16%20-%20Tomato%20Web%20Optimization.md).

### Gallery temptation, then restraint

A magazine-layout gallery with save-scroll felt like a second website.
It was **reverted** to a simple slideshow with captions—the
“gallery paradox.”

Journal: [Gallery Paradox](docs/log/2026-08-20%20-%20The%20Gallery%20Paradox.md).

### First phase of assembly

DigiKey parts arrived. The first `07_alu` board took ACT151 muxes,
ACT283 adders, then LEDs and headers. Power-on showed light without
shorts; bad joints were hunted down. Caps were left off for early LED
tests. Without an onboard FSM, stimulus planning for A/B/C and opcode
pins pointed at 5 V ATmega rather than 3.3 V ESP32 headaches—useful for
slice validation even as the complete machine story moved to FPGA.

Journal:
[First Phase of Assembly](docs/log/2026-08-18%20-%20First%20Phase%20of%20Assembly.md),
[First Lights and Flux](docs/log/2026-08-21%20-%20First%20Lights%20and%20Flux.md),
[Invisible Logic](docs/log/2026-08-23%20-%20The%20Invisible%20Logic.md).

**PRs:** #23–#26.

---

## [2026-08-01] – [2026-08-15] — Order, license, FPGA burn, public face

### Remaining boards while fab runs

With the ALU routed, work shifted to 32-bit plumbing: data bus
arbitration via tri-state drivers and one-hot decode rather than
forests of 74257s, then register, PC/SP, memory, and shift/mul lots.
The July advice held: do not build a throwaway FSM for the fab wait;
build pieces that ship in the final machine.

Journal:
[Designing Additional Boards](docs/log/2026-08-02%20-%20Designing%20Additional%20Boards.md).

### Ordered Tomato

JLCPCB bare `07_alu` boards and DigiKey BOM for **two** 8-bit dual-LUT
slices (16-bit cascade bring-up): ACT151s, ACT283s, flag latch, zero
compare, LEDs, SIP networks—on the order of tens of dollars for parts
plus near-nothing for bare boards. Tomato left the screen.

Journal: [Ordered Tomato](docs/log/2026-08-07%20-%20Ordered%20Tomato.md).

### Broadsheet identity

The site rejected Stripe-product polish and generic colorful React.
Tomato is 70s–90s 74xx copper with a door back to now, so the front
became a **1990s broadsheet** (Ashtown Valley framing) with modern 3D
KiCad plates. The name “Tomato” itself was an escape from endless
“32b/40b cpu” generics—not a tomato joke with a backstory.

Journal:
[Ashtown Valley](docs/log/2026-08-13%20-%20Front-Page%20News%20in%20Ashtown%20Valley.md),
[Solder Station](docs/log/2026-08-13%20-%20Solder%20Station%20Arrives.md).

### ISA as a wire

Public wording rejected “supports N ISAs” marketing. An ISA here is a
parametric map of external bits onto mux selects—overlay word,
immediate box, dual-LUT—not a second computer in copper. Profiles and
CSV revisions can look numerous; the mechanism is the claim.

Journal: [ISA as a Wire](docs/log/2026-08-15%20-%20ISA%20as%20a%20Wire.md).

### PCBs arrive; FPGA and software pipelines land

Five `07_alu` boards arrived and passed power-rail continuity. On the
digital side: `main.v` with tomato.v1 microcode burn, assembler
`.s` → `.mem`, fib/collatz/MMIO smoke programs, Sky130 synthesis
hooks, formal/directed/UVM ALU harness, CPI reporting from Icarus.
Licensing and SPDX headers went public (SHL-2.1; a brief CERN-OHL-P-2.0
experiment on Aug 15 was later restored to SHL in September). The first
tomato.tmarhguy.com wave shipped Dual-LUT playground, board catalog
(lots 01–08), architecture map, and 3D tour.

Journal: [PCBs Arrive!](docs/log/2026-08-15%20-%20PCBs%20Arrive!.md).

**PRs:** #7–#21.

---

## [2026-07-30] – [2026-07-31] — The 40-bit day, then settling on 32

After months on Tomato32, instruction encoding—not the ALU—felt like
the bottleneck: 10-bit opcode, three register fields, and bank bits
filled a 32-bit word with no honest fourth operand for dual-LUT. A
unified **40-bit** word (12-bit INS, four register fields, roomier
banking) was designed and briefly widened through Digital.

The next day, buildability won. Tomato **fell back to 32-bit**: 512-row
/ 9-bit opcode index, four 5-bit operand fields plus 3-bit bank → **256
addressable GPRs** in the scheme that matches current RTL addressing.
The dual-LUT ALU PCB stayed as designed. The lingering strategic choice
was how to bring the board up—minimal FSM vs real peripherals—settling
toward peripherals and sim vectors rather than disposable stimulus
hardware, and not investing further in the 40-bit widen.

Journal:
[40b redesign](docs/log/2026-07-30%20-%20Redesign%20into%2040b%20(Old%20design%20=%2032b).md)
*(superseded)*,
[Falling back to 32b](docs/log/2026-07-31%20-%20Falling%20back%20to%2032b.md),
[Lingering thoughts](docs/log/2026-07-31%20-%20The%20lingering%20thoughts.md).

This is the permanent width decision. Tomato remains 32-bit.

---

## [2026-07-04] – [2026-07-26] — Dual-LUT lock-in, reusable slices, demos

### Architecture: two LUT3 planes into the adder

The lasting ALU identity landed: **`f(a,b,c) + g(a,b,c) + cin`**. A
single masked-invert / LUT2 path was rejected in favor of a second
independent 8:1 LUT3 despite needing more opcode bits—the operational
space mattered more than saving two chips per cell. Theoretical
redundancy was acknowledged for later pruning.

Journal:
[Architecture Upgrade](docs/log/2026-07-13%20-%20Architecture%20Upgrade.md).

### Board strategy experiments

A **16-bit cascading macro-cell** plan aimed at fab reuse (four boards
→ 64-bit) and smaller ~120 mm squares instead of a cramped 240 mm
monolith. Flag logic was planned only on edge boards; zero would
propagate Zin/Zout. That exploration is **superseded** as the primary
story—the physical path that shipped was an **8-bit dual-LUT slice**,
with the complete computer on FPGA—but modularity intent survived.

Journal:
[16b × 4](docs/log/2026-07-13%20-%20Downgrade%20for%20an%20upgrade%20-%2032b%20to%2016b%20x%204.md)
*(superseded exploration)*.

### Truth-table latch and opcode-search demos

Opcode truth tables gained latch thinking so repeated ADD does not
“black out” mid-resolve. Demo ideas rejected Fib/Collatz as the only
showpiece and sketched a self-programming FSM that searches opcodes
against expected results—seed of the later Dual-LUT compiler. Pipelined
“reprogram a cell just before use” stayed a thought experiment.

Journal:
[Truth Table Latch](docs/log/2026-07-13%20-%20Truth%20Table%20Latch.md),
[Demo Ideas](docs/log/2026-07-13%20-%20Demo%20Ideas.md),
[Pipelined FPGA](docs/log/2026-07-13%20-%20Pipelined%20FPGA%20-%20What%20if....md).

### Copper progress

KiCad routing drove through 16-bit and 8-bit boards toward DRC-clean
signoff; zero-flag logic used a 74688 instead of a reduction tree;
silkscreen art (Ghana, Achimota, Penn) appeared; FPGA FSM stubs began
brute-force opcode search and segment display tests.

---

## [2026-06-22] – [2026-06-30] — Schematics complete, then de-bloating the ALU

### Getting to zero ERC

Core ALU schematics closed; hex displays confirmed 32-bit sim behavior;
gated clocks gave way to OR-enforced output enables; global labeling
drove ERC from hundreds of issues to clean. `inv32`, LEDs, and override
switches made the board probeable. PCB dimensions and placements locked;
buses started to route.

### The big discrete optimizations

Routing pressure forced several architectural cleanups that define the
physical slice:

1. **74251 / 151 mux cells** over 125+138 trees—same logic, stronger
   drive, less contention, shorter buses.
2. **4-bit 74283 slices** instead of a one-bit soup, with generate /
   propagate cleaned via NAND identities (~eight inverter-driver chips
   saved vs naïve AND + 54541 banks).
3. **Elimination of mode multiplexers.** Parallel adder-vs-LUT races
   into banks of 74257s were deleted. The LUT3 feeds the adder A inputs:
   arithmetic programs the LUT as a wire; logic programs the LUT and
   forces B=0 / cin=0 so the adder is a transparent exit. Eight 74257s
   and thirty-two A-mask gates left the design. Carry-skip inside each
   4-bit slice replaced a full CLA “central spine” that was hell to
   route on PCB.
4. Tri-state 251 paths later preferred **151** where High-Z faults
   threatened.

Journal:
[74251 redesign](docs/log/2026-06-26%20-%20ALU%20-%20Redesign%20with%2074251.md),
[ALU refinement](docs/log/2026-06-26%20-%20ALU%20Architecture%20Refinement%20&%20Logic%20Optimization.md),
[Mode mux elimination](docs/log/2026-06-27%20-%20Elimination%20of%20Mode%20Multiplexers.md).

Register-file testing (3R/1W), CSR flag widening, and ATF16V8B segment
displays rounded out the month. Absolute discrete-MHz claims in the
journals are historical estimates—not the current Nexys CPU clock story.

---

## [2026-06-15] – [2026-06-21] — Multiply, modular microcode, seeing the buses

### Multiplication without a chip farm

Naïve shift-add (~32 cycles) and Wallace-tree area were both rejected.
The settled discrete approach is a **priority-encoder feedback loop**:
smaller operand into the encoder, jump to the next set bit, barrel-shift
the multiplicand by 2ⁿ in one cycle, clear that bit, repeat—best case
about one cycle, worst case on the order of sixteen for a 32-bit-out
multiply, reusing shifter and ALU rather than a dedicated array. Shift
and mul-div boards merged.

Journal:
[Mul-Div Engine](docs/log/2026-06-10%20-%20Implementing%20Mul-Div%20Engine.md),
[Multiplication and Division](docs/log/2026-06-15%20-%20Multiplication%20and%20Division.md).

### Microcode as six local boards

One central EEPROM and a 64-bit splitter was fanout hell on a real
backplane. Decode split into small boards next to what they drive—ALU,
shift/mul, IR/reg/writeback, mem I/O, mem bus, PC/stack—each with its
own small EEPROM on a shared IR opcode backplane. HALT stayed on main.
The FPGA later burns the same modular planes as headers and mem files.

Journal:
[Microcode Modularization](docs/log/2026-06-16%20-%20Microcode%20Control%20Modularization.md).

### Display and verification

A thirty-two-digit hex display for A/B/C/W went through BCD dead-ends
and gate-count disasters into a shared font ROM with scanned latches
(~69 ICs). Formal 1b/8b/32b proofs, directed replay, and UVM scaffolding
started. Register file was pulled onto the ALU board to cut inter-board
wires (~96 → under 40). Writeback mux became the main bus; store-mux
left main.

Journal:
[ALU segment display](docs/log/2026-06-19%20-%20ALU%20segment%20display%20design.md).

---

## [2026-06-08] – [2026-06-14] — Flexible datapath, IR, PC, first ISA lock

The top-level Digital sheet stopped being a sketch and became a
multiplexed machine:

- Bus arbitration widened to **8:1 via drivers with enables**—more
  flexibility without a cost explosion.
- Instruction register gained **native immediate decode** and a
  byte-lane decoder aimed at RISC-V-shaped imm overlays—not to become
  RISC-V, but to map foreign encodings onto Tomato’s muxes.
- Sign extension replaced naïve split/merge; memory addressing moved
  toward banked models.
- **Program counter** was redesigned for ISA flexibility; **stack
  pointer** and **store-mux** appeared; VGA pins showed up on main.
- Microcode words grew toward **48 bits** as control fields multiplied;
  multiply results entered the writeback mux.
- Fetch discipline hardened: PC-out asserted on every fetch so other
  paths cannot steal the bus mid-instruction.
- Load/store microcode was audited: several offsetted load/store rows
  forced address zero (`alu-op`/`alu-pre` clear while bus-select said
  ALU)—fixed in the field map. Store data remaining hardwired to one
  register was noted as a conventional `SW` limitation without Din
  wiring changes.

By mid-June, dozens of Digital tests passed and on the order of forty
ISA operations were locked in JSON—early counts, later superseded by
the burned CSV.

The engineering **build log** started here so questions and answers
would not live only in chat.

Journal:
[Load Store Pipeline](docs/log/2026-06-11%20-%20Load%20Store%20Pipeline%20Analysis.md),
[Welcome](docs/log/Welcome%20to%20Tomato%2032.md).

---

## [2026-06-05] – [2026-06-07] — Project birth

Tomato began as scaffolding, docs, and toolchains, then immediately as
hardware: custom symbols, gate primitives, cascading mux hierarchies,
slice and adder cells, and a hierarchical **32-bit ALU** in Digital and
KiCad. Shift, flag, register, microcode, and IR boards appeared;
program-counter subcircuits and keyboard I/O simulation followed.

Primitive ALU operations were mapped and tested at about **ninety-one
single-cycle** truth-table ops—the first concrete “what can this cell
do?” catalog, long before the named ISA CSV. Early Verilog exports that
did not match the living Digital design were cleared out.

**PR:** #1.

---

## What was tried and later set aside

Useful as a reverse index when old docs disagree with the present
machine:

| Idea | When | Fate |
|---|---|---|
| Unified 40-bit machine word | 2026-07-30 | Reverted next day; Tomato is 32-bit |
| 16b × 4 cascade as primary PCB story | 2026-07-13 | Superseded exploration; shipped discrete path is 8b slice + FPGA computer |
| 32,768-GPR / deep bank narrative | late Aug narrative | Not current FPGA RTL (256 × 32-bit) |
| Gallery as magazine + save-scroll | 2026-08-20 | Reverted to slideshow |
| Film letterbox / fog 3D tour | 2026-08-16 | Removed |
| “Supports N ISAs” marketing | 2026-08-15 | Rejected framing (ISA as wire) |
| Vivado as default daily FPGA flow | pre-2026-08-28 | Default is Yosys / nextpnr / X-Ray |
| Six-entry menu / ~52–53 burned opcodes | Aug–early Sep | Grown to 14-entry OS v3.0 / Desktop v1.2 / 61+NOP |
| Envelop name “Pigeon” | Sep 14 | Retired |
| Ethernet bring-up harness | Sep 16–17 | Removed as superseded |
| Brief CERN-OHL-P-2.0 relicense | 2026-08-15 | SHL-2.1 restored |

---

## How to read this against the raw history

```bash
# Every subject line, oldest first
git log --reverse --pretty=format:'%ad  %s' --date=short

# Journal index (narrative companion to this file)
open docs/log/README.md
```

Commit messages record *that* something changed; this changelog and the
journals record *why*. Prefer [`docs/status.md`](docs/status.md) whenever
a dated number fights the machine that boots today.

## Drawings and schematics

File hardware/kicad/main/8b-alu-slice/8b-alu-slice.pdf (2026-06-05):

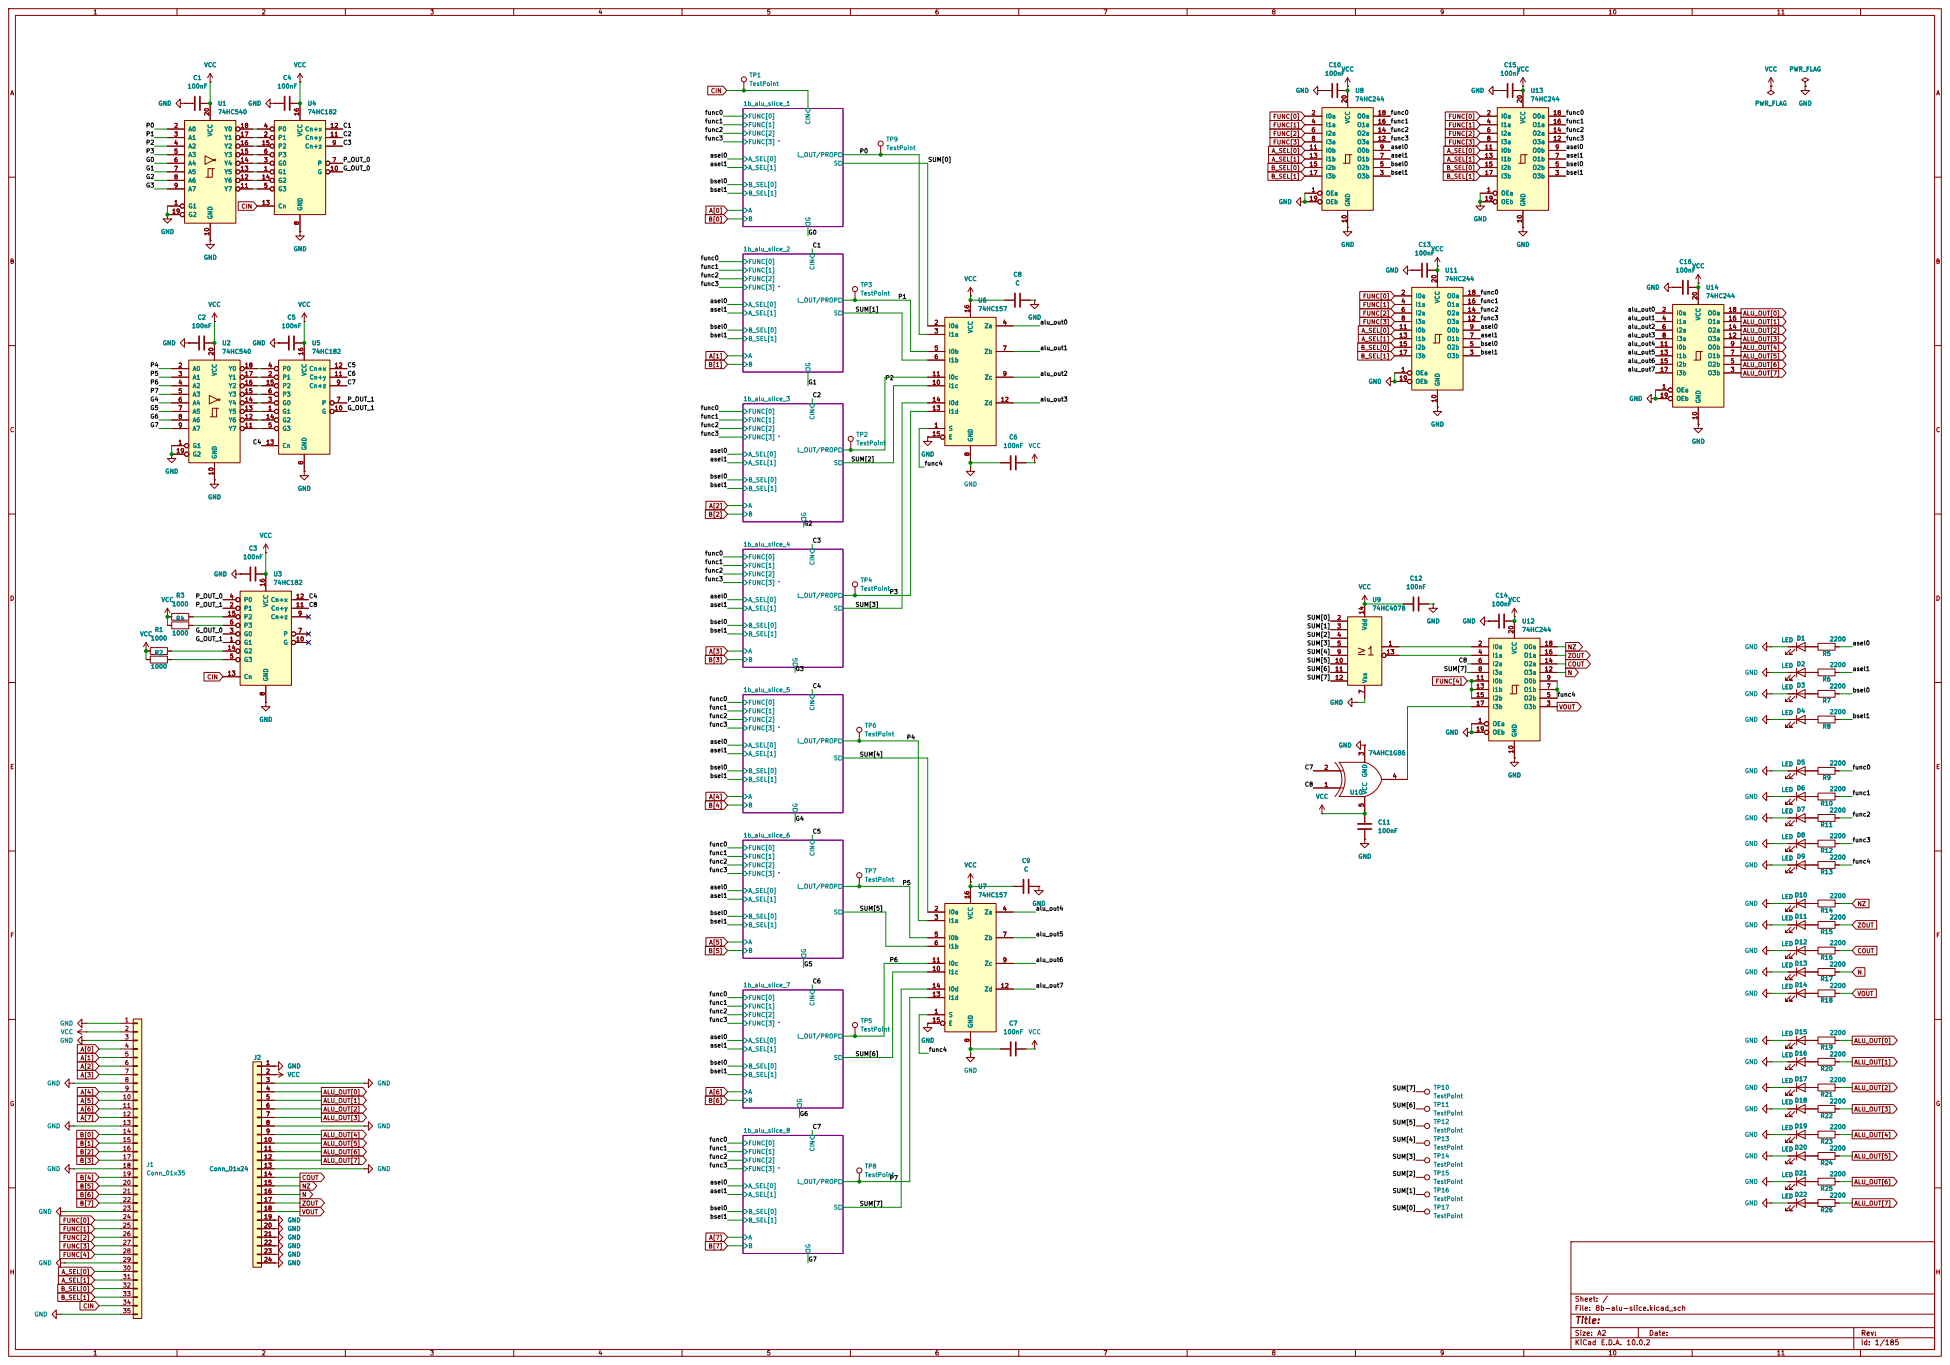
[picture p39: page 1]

Size: A2 | Rev:
KiCad E.D.A. 10.0.2 | Id: 1/185

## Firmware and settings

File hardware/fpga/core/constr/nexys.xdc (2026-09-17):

## Tomato — Nexys A7-100T (xc7a100tcsg324-1)
## Top: nexys_top. Video leaves on the 12-bit DVI PMOD across JC + JD.
set_property CFGBVS VCCO [current_design]
set_property CONFIG_VOLTAGE 3.3 [current_design]

## ---- 100 MHz board oscillator -------------------------------------------
set_property -dict { PACKAGE_PIN E3 IOSTANDARD LVCMOS33 } [get_ports clk]
create_clock -period 10.000 -name sys_clk -waveform {0.000 5.000} [get_ports clk]

## ---- CPU_RESETN (red button, high at rest) -------------------------------
set_property -dict { PACKAGE_PIN C12 IOSTANDARD LVCMOS33 } [get_ports cpu_resetn]

## ---- D-pad: stands in for a keyboard (rtl/board/keypad.v) ----------------
set_property -dict { PACKAGE_PIN N17 IOSTANDARD LVCMOS33 } [get_ports btnc]
set_property -dict { PACKAGE_PIN M18 IOSTANDARD LVCMOS33 } [get_ports btnu]
set_property -dict { PACKAGE_PIN P18 IOSTANDARD LVCMOS33 } [get_ports btnd]
set_property -dict { PACKAGE_PIN P17 IOSTANDARD LVCMOS33 } [get_ports btnl]
set_property -dict { PACKAGE_PIN M17 IOSTANDARD LVCMOS33 } [get_ports btnr]

## ---- Slide switches ------------------------------------------------------
set_property -dict { PACKAGE_PIN J15 IOSTANDARD LVCMOS33 } [get_ports {sw[0]}]
set_property -dict { PACKAGE_PIN L16 IOSTANDARD LVCMOS33 } [get_ports {sw[1]}]
set_property -dict { PACKAGE_PIN M13 IOSTANDARD LVCMOS33 } [get_ports {sw[2]}]
set_property -dict { PACKAGE_PIN R15 IOSTANDARD LVCMOS33 } [get_ports {sw[3]}]
set_property -dict { PACKAGE_PIN R17 IOSTANDARD LVCMOS33 } [get_ports {sw[4]}]
set_property -dict { PACKAGE_PIN T18 IOSTANDARD LVCMOS33 } [get_ports {sw[5]}]
set_property -dict { PACKAGE_PIN U18 IOSTANDARD LVCMOS33 } [get_ports {sw[6]}]
set_property -dict { PACKAGE_PIN R13 IOSTANDARD LVCMOS33 } [get_ports {sw[7]}]
set_property -dict { PACKAGE_PIN T8  IOSTANDARD LVCMOS18 } [get_ports {sw[8]}]
set_property -dict { PACKAGE_PIN U8  IOSTANDARD LVCMOS18 } [get_ports {sw[9]}]
set_property -dict { PACKAGE_PIN R16 IOSTANDARD LVCMOS33 } [get_ports {sw[10]}]
set_property -dict { PACKAGE_PIN T13 IOSTANDARD LVCMOS33 } [get_ports {sw[11]}]
set_property -dict { PACKAGE_PIN H6  IOSTANDARD LVCMOS33 } [get_ports {sw[12]}]
set_property -dict { PACKAGE_PIN U12 IOSTANDARD LVCMOS33 } [get_ports {sw[13]}]
set_property -dict { PACKAGE_PIN U11 IOSTANDARD LVCMOS33 } [get_ports {sw[14]}]
set_property -dict { PACKAGE_PIN V10 IOSTANDARD LVCMOS33 } [get_ports {sw[15]}]

## ---- LEDs ----------------------------------------------------------------
set_property -dict { PACKAGE_PIN H17 IOSTANDARD LVCMOS33 } [get_ports {led[0]}]
set_property -dict { PACKAGE_PIN K15 IOSTANDARD LVCMOS33 } [get_ports {led[1]}]
set_property -dict { PACKAGE_PIN J13 IOSTANDARD LVCMOS33 } [get_ports {led[2]}]
set_property -dict { PACKAGE_PIN N14 IOSTANDARD LVCMOS33 } [get_ports {led[3]}]
set_property -dict { PACKAGE_PIN R18 IOSTANDARD LVCMOS33 } [get_ports {led[4]}]
set_property -dict { PACKAGE_PIN V17 IOSTANDARD LVCMOS33 } [get_ports {led[5]}]
set_property -dict { PACKAGE_PIN U17 IOSTANDARD LVCMOS33 } [get_ports {led[6]}]
set_property -dict { PACKAGE_PIN U16 IOSTANDARD LVCMOS33 } [get_ports {led[7]}]
set_property -dict { PACKAGE_PIN V16 IOSTANDARD LVCMOS33 } [get_ports {led[8]}]
set_property -dict { PACKAGE_PIN T15 IOSTANDARD LVCMOS33 } [get_ports {led[9]}]
set_property -dict { PACKAGE_PIN U14 IOSTANDARD LVCMOS33 } [get_ports {led[10]}]
set_property -dict { PACKAGE_PIN T16 IOSTANDARD LVCMOS33 } [get_ports {led[11]}]
set_property -dict { PACKAGE_PIN V15 IOSTANDARD LVCMOS33 } [get_ports {led[12]}]
set_property -dict { PACKAGE_PIN V14 IOSTANDARD LVCMOS33 } [get_ports {led[13]}]
set_property -dict { PACKAGE_PIN V12 IOSTANDARD LVCMOS33 } [get_ports {led[14]}]
set_property -dict { PACKAGE_PIN V11 IOSTANDARD LVCMOS33 } [get_ports {led[15]}]

## ---- Seven-segment displays ----------------------------------------------
set_property -dict { PACKAGE_PIN T10 IOSTANDARD LVCMOS33 } [get_ports {seg[0]}]
set_property -dict { PACKAGE_PIN R10 IOSTANDARD LVCMOS33 } [get_ports {seg[1]}]
set_property -dict { PACKAGE_PIN K16 IOSTANDARD LVCMOS33 } [get_ports {seg[2]}]
set_property -dict { PACKAGE_PIN K13 IOSTANDARD LVCMOS33 } [get_ports {seg[3]}]
set_property -dict { PACKAGE_PIN P15 IOSTANDARD LVCMOS33 } [get_ports {seg[4]}]
set_property -dict { PACKAGE_PIN T11 IOSTANDARD LVCMOS33 } [get_ports {seg[5]}]
set_property -dict { PACKAGE_PIN L18 IOSTANDARD LVCMOS33 } [get_ports {seg[6]}]
set_property -dict { PACKAGE_PIN H15 IOSTANDARD LVCMOS33 } [get_ports dp]
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

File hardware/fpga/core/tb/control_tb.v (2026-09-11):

/*
 * Tomato — microcode decode spot-check (512-row v1 images)
 *
 * Engineer : Tyrone Marhguy
 * Project  : Tomato 32-bit CPU
 * File     : control_tb.v
 * Target   : simulation (cwd = hardware/fpga/core)
 * ISA      : docs/isa/tomato.v1.csv
 *
 * Copyright (c) 2025-2026 Tyrone Marhguy
 * SPDX-License-Identifier: Apache-2.0 WITH SHL-2.1
 */
`timescale 1ns/1ps
module control_tb;
    reg  [8:0] op;
    reg        fetch, exec;

    wire [7:0] lutA, lutB;
    wire [2:0] csel, wbsel, bussel, pcsrc, pccond;
    wire [3:0] immsel, bytesel;
    wire [1:0] shiftop, cycles, spop;
    wire flagwe, mulen, penc, regwe, banken, memrd, memwr;
    wire branchen, jumptype, pclinkwe, halt, alusel;

    aluctrl a (.op(op), .lutA(lutA), .lutB(lutB), .csel(csel),
               .flagwe(flagwe), .shiftop(shiftop), .mulen(mulen), .penc(penc));
    irctrl  i (.op(op), .immsel(immsel), .wbsel(wbsel), .regwe(regwe));
    memio   m (.op(op), .fetch(fetch), .banken(banken), .memrd(memrd),
               .memwr(memwr), .bytesel(bytesel));
    membus  b (.op(op), .bussel(bussel), .alusel(alusel));
    pcctrl  p (.exec(exec), .op(op), .branchen(branchen), .jumptype(jumptype),
               .pcsrc(pcsrc), .pclinkwe(pclinkwe), .cycles(cycles),
               .pccond(pccond), .spop(spop), .halt(halt));

    initial begin
        fetch = 0; exec = 1;

        op = 9'h001; #1;
        if (lutA !== 8'hAA || lutB !== 8'hCC) begin
            $display("FAIL: ADD lut %h %h", lutA, lutB); $finish(1);
        end
        if (csel !== 3'd0 || flagwe !== 1'b1 || regwe !== 1'b1 || immsel !== 4'd1) begin
            $display("FAIL: ADD ctrl csel=%0d flag=%b reg=%b imm=%0d",
                     csel, flagwe, regwe, immsel);
            $finish(1);
        end

        op = 9'h002; #1;
        if (lutA !== 8'hAA || lutB !== 8'h33 || csel !== 3'd1) begin
            $display("FAIL: SUB lut/csel %h %h %0d", lutA, lutB, csel); $finish(1);
        end

        // ADDI uses imm13
        op = 9'h020; #1;
        if (immsel !== 4'd3 || regwe !== 1) begin
            $display("FAIL: ADDI imm=%0d", immsel); $finish(1);
        end

        // LW: ALU.A = rA
        op = 9'h060; #1;
        if (memrd !== 1 || cycles !== 2'd2 || wbsel !== 3'd3 || alusel !== 0) begin
            $display("FAIL: LW"); $finish(1);
        end

        // SW: ALU.A = rB, imm8, store rA
        op = 9'h068; #1;
        if (memwr !== 1 || alusel !== 1 || immsel !== 4'd0 || wbsel !== 3'd4) begin
            $display("FAIL: SW alu=%b imm=%0d wb=%0d", alusel, immsel, wbsel);
            $finish(1);
        end

        // BNE → ~Z
        op = 9'h081; #1;
        if (branchen !== 1 || pccond !== 3'd1) begin
            $display("FAIL: BNE cond=%0d", pccond); $finish(1);
        end

        // JR → ALU / pass B
        op = 9'h0A3; #1;
        if (jumptype !== 1 || pcsrc !== 3'd4 || immsel !== 4'd1) begin
            $display("FAIL: JR src=%0d imm=%0d", pcsrc, immsel); $finish(1);
        end
        if (lutA !== 8'h00 || lutB !== 8'hCC) begin
            $display("FAIL: JR lut %h %h", lutA, lutB); $finish(1);
        end

        op = 9'h010; #1;
        if (mulen !== 1 || penc !== 0 || wbsel !== 3'd1) begin
            $display("FAIL: MUL"); $finish(1);
        end

        op = 9'h0C0; #1;
        if (spop !== 2'd2 || memwr !== 1 || bussel !== 3'd7) begin
            $display("FAIL: PUSH"); $finish(1);
        end

        // IN: lane sel=2, wb=mem, reg_we, no mem cycle
        op = 9'h0C8; #1;
        if (bytesel !== 4'd2 || wbsel !== 3'd3 || regwe !== 1'b1) begin
            $display("FAIL: IN bs=%0d wb=%0d we=%b", bytesel, wbsel, regwe);
            $finish(1);
        end
        if (memrd !== 1'b0 || memwr !== 1'b0) begin
            $display("FAIL: IN should not touch mem rd/wr"); $finish(1);
        end

        // OUT: latch path (no reg_we); imm_sel=1 passes rB unused — rA from IR
        op = 9'h0C9; #1;
        if (regwe !== 1'b0 || memrd !== 1'b0 || memwr !== 1'b0) begin
            $display("FAIL: OUT we/mem"); $finish(1);
        end

        op = 9'h0FF; #1;
        if (halt !== 1) begin $display("FAIL: HALT"); $finish(1); end

        $display("PASS: control (real-machine decode)");
        $finish;
    end
endmodule

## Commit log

2026-06-05 hardware: Add consolidated custom component symbols
    Fix: Pruned MyCPU.kicad_sym to exclusively contain foundational transistor primitives (Q_NMOS_BSS138 and Q_PMOS_BSS84).
    Achieved: A clean, lean baseline library for drawing logic gates without bloat.
2026-06-05 hardware/modules: Build fundamental logic gate schematics
    Built: AND, AOI22, Buffer, Inverter, NAND, NOR, OR, XNOR, and XOR gate implementations.
    Fix: Flattened the gate directory structures, removing legacy KiCad project wrappers (.pro, .pcb) and simulation caches.
    Achieved: A lean, modular schematic library ready for higher-order arithmetic and routing circuits.
    [gate_and.kicad_sch, gate_and_2in_8bit.kicad_sch, gate_and_3in.kicad_sch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]
2026-06-05 hardware/modules: Implement cascading multiplexer hierarchy
    Built: 2-to-1, 4-to-1, and 8-to-1 multiplexer schematics.
    Fix: Updated internal Sheetfile paths so mux_4to1 relies on mux_2to1, and mux_2to1 accurately pulls in the aoi22 and inv gate schematics using proper relative mapping.
    Achieved: Fully functional data routing blocks necessary for the ALU.
    [mux_2to1-8b.kicad_sch, mux_2to1.kicad_sch, mux_4to1-8b.kicad_sch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]
2026-06-05 hardware/modules: Add slice architectures and adder primitives
    Built: Base 1-bit and 8-bit slice layouts (1b-alu-slice, 8b-alu-slice) and standard adders (adder2, adder4, adder8).
    Achieved: Functional arithmetic sub-components ready for main board integration.
    [1b-alu-slice.kicad_pcb, 1b-alu-slice.kicad_sch, 8b-alu-slice.kicad_sch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]
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2026-06-05 hardware/boards: Build robust hierarchical 32-bit ALU architecture
    Built: Top-level alu-32b schematic, mid-level alu-8b boards, and base alu-1b schematics. Fix: Corrected hierarchical hsheet references top-to-bottom. Achieved: A completely linked, end-to-end hierarchical 32-bit ALU.
    [04_flag_reg.kicad_pcb, 04_flag_reg.kicad_sch, 1b-alu-slice.kicad_sch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]
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2026-06-06 feat: redesigned alu cell to reuse 4to1 mux for propagate signal 🎉
    Instead of the old design of a dedicated xor gate to generate a xor b for the carry look ahead, i am reusing the naturally cascaded 4to1 mux (x2) and 2to1 mux, where the top 4to1mux propagates signal and the top 2to1 mux xor with c. Functionally, it works same as the old design, but the 8to1 mux is no longer a black box. Additionally, since I can probe the intermediate 4to1 muxes... I have dual output so i can compute two independent a (*binary logic) b, at once via opcode mapping, and maintain the lut3 orignal capacity increasing flexibilty and data readiness.
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2026-06-07 feat: designed shift and flag reg kicad boards
    [03_shift.kicad_pcb, 03_shift.kicad_sch, 04_flag_reg.kicad_sch]
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2026-06-08 redesign: increased width to 8to1 mux via drivers with enable pins; massive improvement and flexibility for no cost
    Today, I realized instead of a naive mux, I can use 74xx541 and a decoder (74xx138,139) to build a mux of size n that does not cascade. Pros: allows any mux-n to be built without worrying about cascade; exploit two enable pins ensuring high Z and lowest chance of contention.
    Cons: so far nothing :)
2026-06-08 schematics: improved mux8to1 via 74xx151; will change to 74xx541 + 139
    Today, I realized instead of a naive mux, I can use 74xx541 and a decoder (74xx138,139) to build a mux of size n that does not cascade. Pros: allows any mux-n to be built without worrying about casca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
    [gate_aoi22.kicad_sch, mux_8to1.kicad_sch]
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2026-06-08 feat: updated them and kicad cosmetic self update
    [alu-32b.kicad_sch, alu-8b.kicad_sch, gate_inv.kicad_sch]
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2026-06-08 feat: redesigning; currently considering size increase 32b->40b or 32b->48b (in progress)
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2026-06-09 feat: designing muxes using drivers
    Conventionally, drivers used as muxes will be called drivers. driverAB_CtoD means a mux of word size AB and selects between C word signals into one hot D output.
    [drive8_2to1.kicad_pcb, drive8_2to1.kicad_sch]
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2026-06-10 fix: fixed wiring error that was causing data loop.
    forgot to remove data-in->ir-bus which i did for testing. fixed and main works
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2026-06-11 docs: initial opcode map of isa and use cases.
    This map will undergo extreme and rigorous test and retesting to assert their validity. I will increase it substantially to cover all that Tomato32 was designed for
    [opcode-map.csv]
2026-06-11 test: last test as of current hex encoding and probe
    [opcode-test-results.csv]
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2026-06-11 fix: switched addr from flat 256 addr to 64 addr @ 16banks
    Closes #2
    General Purpose Registers increase from 256 to 1024 for A, B, C, and Ir opcode increases from 256 to 1024 supporting more operations and cross isa native load
2026-06-12 feat: created new program counter with much cleaner design for flexibility across ISAs
    Replaced old program counter with cleaner one. This version asserts conditional/unconditional branch. It merges the sequencer and program counter. It takes out the stack pointer which will be a new board
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2026-06-13 redesign: switched from 64b->48b for additional space for future wiring
    This ensures that things are locked in and need no further change. 64b importantly allows me to finalize the ISA, assembler and schematic wirings without a need for considerable redesign to "save" bits
2026-06-13 del: remove bloat from verilog exports from digital
    [opcode-test-results.csv]
2026-06-13 arch: refactored and redesigned carry logic onto top board; merged flag register and alu
    closes #3
2026-06-15 feat: created vga
    Found a true dual port sram so I created the vga out. CPU writes to both internal single port memory and the display ram asserted with MSBs. The probing board can snoop the display ram without chance of collision. Took a lot of design and sourcing. Ordered the dual ports on Ebay today. Design locked in.
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2026-06-16 checkpoint: last running main.dig
    Pending: update shift to new shift+mul+div board; fix program counter jump logic to handle interrupts correctly and return
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2026-06-17 schematics: initiated kicad project for all boards to match simulation
    [02_shift_encoder.kicad_pcb, 02_shift_encoder.kicad_sch, 03_memory.kicad_pcb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]
2026-06-17 module: designed 8to1 mux with drivers (74125+74138) and decoder to match 74151
    This module will replace native 8to1 muxes (1b) for sheer pro over native muxes except for contention which the 138 verifiably solves.
    [driver1_8to1.kicad_sch]
2026-06-17 docs: csv map of other isas to tomato32's natives; initial map
    [alpha.csv, arc-v-rmx.csv, arm-a32.csv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]
2026-06-17 feat: designed alu0-control unit and wired on top level of 32b alu
    [alu-1b.kicad_sch, alu-32b.kicad_sch, alu-8b.kicad_sch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]
2026-06-17 chore: deleted obsolete kicad files and refactored with latest numbered ones
    [02_register.kicad_pcb, 02_register.kicad_sch, 03_shift.kicad_pcb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]
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2026-06-19 redesign: moved register onto ALU to cut wires from 96 to under 40
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2026-06-21 feat: designed the display module for the alu operands
    [1-seg-display.kicad_sch, alu-display.kicad_sch, text-clk.kicad_sch]
2026-06-21 feat: designed alu-control unit (eeprom controlled)
    I may switch to sram design if I find a coin cell holder
    [alu_control.kicad_sch]
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2026-06-21 kicad: checkpoint; designed the alu display logic; clock circuit
    Added registers for each display to ensure robustness and less worry about debugging screen, keeping focus on the alu board and other components
    [1-seg-display.kicad_sch, alu-1b.kicad_sch, alu-32b.kicad_pcb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]
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2026-06-22 module: designed muxes prioritizing drivers for large switching preserving depth of ~1 gate
    [drive32_2to1.kicad_sch, drive8_2to1.kicad_sch, driver1_8to1.kicad_sch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]
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2026-06-22 refactor: improved global labeling and reduced ERC from 300+ to 6 power flags and minor connector in errors
    [1-seg-display.kicad_sch, alu-1b.kicad_sch, alu-32b.kicad_sch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]
2026-06-22 fix: fixed erc to 0; remaining are warnings about labeling which are being fixed; latest alu schematics pending decoration and organization
    [1-seg-display.kicad_sch, alu-1b.kicad_sch, alu-32b.kicad_pcb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]
2026-06-23 refactor: placing buses in design across alu to improve readability and debugging
    [1-seg-display.kicad_sch, alu-1b.kicad_sch, alu-32b.kicad_sch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]
2026-06-23 feat: created inv32 with 74540 chip x4 for use case in ALU inversion
    [drive_inv32.kicad_sch]
2026-06-23 feat: designed ALU board with 0 ERC errors or warnings 🎉
    Final review of logical correctness and footprints and then routing begins
    [1-seg-display.kicad_sch, alu-1b.kicad_sch, alu-32b.kicad_pcb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]
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2026-06-23 arch: added LEDs, override switches; fixed errors and warnings to 0
    ready for routing after logical coherence check
    [1-seg-display.kicad_sch, alu-1b.kicad_sch, alu-32b.kicad_pcb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]
2026-06-23 chore: removed extra vcc on inMode switch; added missing flags export to pinSocket out pins
    [alu-1b.kicad_sch, alu-32b.kicad_sch]
2026-06-24 fix: fixed the zero flag detection logic
    [1-seg-display.kicad_sch, alu-32b.kicad_pcb, alu-32b.kicad_sch]
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2026-06-25 design: latest routing attempt; components placed approx.
    Current dimension is under 25mm by 25mm
    [alu-32b.kicad_pcb]
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2026-06-26 checkpoint: main.dig with swapped EEPROM with RAM for verilog export capacity
2026-06-26 arch: replaced 3 footpring 125+138 with one strong 8to1 mux
    [alu-1b.kicad_sch]
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2026-06-27 log: redesigning ALU with 251 mux over tristate drivers + decoders
2026-06-27 schematics: designed alu into 4b slices saving several chips and "de-bloating" board of several glue and drivers
    [alu-1b.kicad_sch, alu-32b.kicad_pcb, alu-32b.kicad_sch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]
2026-06-27 arch: redesigned segment displays with ATF16V8B
    Clearly a "bloated" choice, but I need the display to be as robust and stable as possible for debugging purposes. While time multiplexing works well, the hardware for multiplexing for 32b x3 + 1 out is much more complicated than a flat system that takes a nibble and outputs to a segment display
    [1-seg-display.kicad_sch]
2026-06-27 chore: delete obsolete files; replaced store-mux with wb-mux, pc2 replaced with final program counter
    [store_mux.kicad_sch]
2026-06-27 feat: updated the kicad schematics with updated correct control fanouts
    [alu-control.kicad_sch]
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2026-07-01 arch(alu): replace 251 tri-state MUX with 151 to prevent High-Z faults
    Eliminates dead Tri-State functionality on point-to-point traces, preventing potential logic oscillation and chip damage from floating pins. Drive strength and speed are unaffected.
    Closes #4
    [alu-1b.kicad_sch, alu-4b.kicad_sch]
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2026-07-04 schematics: routed all 16b of board; laid out buses
    Changed the clearance from 0.5mm to 0.25mm since ALU is purely combinational and max speed and edge goals remain large enough that crosstalk is extremely negligible at min mhz and 5v logic
    [alu-32b.kicad_pcb]
2026-07-04 feat: routed all 32b; pending layout and final placements, interconnects, and DRC checks
    [alu-32b.kicad_pcb]
2026-07-05 feat: routed right hand side cells; aligned bus traces; fixed DRC to 0 on each cell
    [alu-32b.kicad_pcb]
2026-07-05 feat: added 8to1 mux for cin variety; routed major bus on RHS cells; updated main.dig with cin mux
    Updated alu-control with correct global labels for cin-sel[2..0]
    [alu-32b.kicad_pcb, alu-32b.kicad_sch, alu-control.kicad_sch]
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2026-07-13 feat: implemented flag logic and led for 16 alu; refactored alu-1b cells
    [07_alu.kicad_pcb, 07_alu.kicad_sch, alu-1b.kicad_sch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]
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2026-07-19 fix: resolved kicad erc tests to 0
    [07_alu.kicad_pcb, 07_alu.kicad_sch, alu-32b.kicad_pcb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]
2026-07-19 feat: created seperate led and data input board
    Handles cross wiring and clean grounding while keeping area under tight 100mm on the original board
    [08_display.kicad_pcb, 08_display.kicad_sch]
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2026-07-20 checkpoint: routing flags and finishing final traces before pcb annotations and text
    [07_alu.kicad_pcb, flags_logic.kicad_sch, iopins.kicad_sch]
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2026-07-21 feat: routed final board 🎉
    Area: 100mm by 100mm
    Layer: 2 layers
    Power trace: 0.5mm
    Default trace: 0.25mm
    Clearance: 0.25mm
    DRC: 4 drc thermal errors after routing and pending resolution
    [07_alu.kicad_pcb]
2026-07-24 fpga: implemented fsm to brute force find matching opcode
    It finds opcode by brute force sweeping across 256 by 256 and checking if computed output is equal to expected test output
    [07_alu.kicad_pcb, flags_logic.kicad_sch]
2026-07-24 fix: updated the flag logic to match simulation in digital design
    [07_alu.kicad_pcb, flags_logic.kicad_sch]
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2026-07-26 feat: route 8b ALU slice and annotate pending final signoff 🎉🎉
    Highlights:
    - 0 ERC/DRC errors
    - 0 Unrouted nets
    - 2345 track segments
    - 388 vias after cleanup
    - 760 pads
    - 18 core 74xx chips
    - 7 flag 74xx chips
    Pending additional confirmation of hardware-simulation faithfulness and fidelity.
    [07_alu.kicad_pcb, 07_alu.kicad_sch, flags_logic.kicad_sch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]
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2026-07-26 fix: placed power flags to resolve flag error in kicad
    DRC/ERC are both 0 :)
    [07_alu.kicad_sch, iopins.kicad_sch]
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2026-08-03 docs: swapped from gif to png for faster alu pcb loading in root readme
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2026-08-03 docs(verification):rebrand README and add make synth targets
    document synthesis/benchmark links,
    wire make synth into verification Makefile, fix clean target.
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2026-08-08 fix: replaced with resistor array/network over individual components
    fix #5
    [07_alu.kicad_pcb, flags_logic.kicad_sch, led_unit.kicad_sch]
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2026-08-12 feat(fpga): main.v + tomato.v1 microcode burn (#8)
    [coldfire.csv, datapath-audit.csv, ebpf.csv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]
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2026-08-14 chore(web): wire playground and boards into nav and sanity tests
    Keep every sheet on the same mast and fail CI if the new pages or modules go missing.
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2026-08-25 feat(web): story gallery and live datapath; wire 01_alu display sheet (#27)
    * chore(web): add the in-place media optimizer
    * media(web): recompress plates, pcb, and gallery WebPs
    * media(web): add story gallery stills and responsive WebPs
    * test(web): cover story gallery LCP preload
    * feat(web): retell the gallery from notebook to 07_alu
    * feat(web): embed the Dual-LUT strip on the front page
    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
    [alu-32b.kicad_sch, alu-control.kicad_sch, untitled.kicad_sch]
2026-08-26 feat(web): polish magazine front, mast, playground, and mobile LCP
    Ship the assembly bench media, journal plates, nav/theme layout fixes, and a responsive high-priority hero poster so mobile Lighthouse can clear LCP without shrinking the paper voice.
2026-08-28 feat(fpga): move core tree off Vivado, add DVI video, and OSS build
    Rename tomato/ to core/, drop .xpr cruft, wire DVI PMOD video and TomatoOS burn, and add Makefile-driven open-source synthesis for hdmi_test on the Mac.
    [bus_tb.v, control_tb.v]
2026-08-28 hardware: add alu verification sheets and lot 08 kicad stub
    Check in Digital alu-1b/alu-8b sheets, the Electric library, verilog burn harness, and kicad readme updates for the 07_alu bring-up path.
    [08_alu.kicad_pcb, 08_alu.kicad_sch]
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2026-08-28 chore: update root readme, notices, and isa audit paths
    Refresh repo-level docs and tooling after the media migration and FPGA core rename.
    [datapath-audit.csv]
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2026-08-29 feat(fpga): rebuild on burn, wire games/keypad, time at 90 MHz
    `include of rtl/burn/*.vh was invisible to make, so `make fpga`
    said nothing to be done and re-flashed a stale bitstream. nextpnr
    --freq 100 was a vanity Fmax check the CPU does not run at.
2026-08-29 docs: log the pivot off Vivado to the OSS FPGA flow
    Yosys, nextpnr-xilinx, and prjxray replace the laptop Vivado wait
    once HDMI already proved pixels on the glass.
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2026-08-29 docs(isa): split assembler vocabulary into tomato.v1.pseudo.csv
    Burn ROM stays the single opcode authority; pseudos expand into burned ops.
    [tomato.v1.csv, tomato.v1.pseudo.csv]
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2026-08-29 media: add tomato-v1-burn main.dig plate for the paper
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2026-08-29 docs: clone-ready Get to work — what is tracked vs gitignored
    Spell out that a fresh clone can `make test` with Icarus only; the 2.7 GB
    FPGA toolchain stays ignored until `make setup`. Fix the stale software stub
    in the repo map and status table.
2026-08-31 feat(web): Vercel analytics, site identifiers, and deployment polish
    Wire Web Analytics and Speed Insights for production Vercel hosts, add
    conventional site identifiers (web manifest, humans.txt, security.txt),
    fix 3D Bottom view controls, and ship recent landing and gallery UX work.
2026-08-31 fix(web): track public site identifier text files
    Allow robots.txt, humans.txt, and .well-known/security.txt through the
    global *.txt gitignore so conventional crawler and security files deploy.
2026-08-31 fix(web): reveal landing sections that stayed invisible on desktop
    Scroll-reveal CSS hid .landing-reveal / .landing-scrub at opacity 0, but
    nothing added .is-in. Gate the hide behind JS and observe into view.
2026-09-05 fix(web): smooth gallery swipe on desktop
    Drop expensive cover-flow blur during drag, add flick velocity, and settle the track after the gesture so web swipes feel less janky.
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2026-09-07 fix(web): stabilize mobile hero board and tighten CTA row
    Drop viewport-fill/nav-height resize so the 3D stage keeps a fixed
    aspect ratio while scrolling, center the board toolbar, and shrink the
    hero actions to one line on small screens.
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2026-09-11 feat(web): publish When assembly is still too high-level for Tomato.
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2026-09-11 docs(log): When assembly is still too high-level for Tomato
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2026-09-11 docs(isa): burn MASKADD and XORAND into tomato.v1.csv
    [tomato.v1.csv]
2026-09-11 test(fpga): keep games_tb aligned with the current OS burn
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2026-09-16 docs(isa): count 61 burned opcodes
    The CSV and README have to match the generator so the burn list is the authority, not an old 52-opcode badge.
    [tomato.v1.csv]
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2026-09-17 fix(web): refresh landing script asset hash
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2026-09-18 fix: Dual-LUT remote ABI + live board activity LEDs
    Teach remote_exec and the preview compiler Envelop's Dual-LUT nest opcodes
    (e.g. NANDAND for nand(a,b,c)) so physical jobs stop returning INVALID_OPCODE.
    Drive Nexys LEDs from compiler sweep/latch, writeback, and Envelop RX/TX pulses.
    Keep Nordic ACI setup out of the tree; local hardware can overlay .local/.
    [lut-nested-fuse.csv, lut.csv, luts.csv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]
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2026-10-01 fix(fpga): pin macOS SDK without arm64e.x1 TBD for prjxray build
    Newest CLT SDKs ship arm64e.x1 slices in libSystem.B.tbd that the
    bundled ld cannot parse, failing CMake's compiler check. Pick the
    newest installed SDK without those slices when SDKROOT is unset,
    and clear a stale CMakeCache so the retry configures clean.

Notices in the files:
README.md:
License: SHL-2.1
